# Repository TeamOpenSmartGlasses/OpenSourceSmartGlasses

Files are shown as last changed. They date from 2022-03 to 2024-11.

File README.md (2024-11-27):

# Open Source Smart Glasses

### Update 2024 - we've moved on to build [AugmentOS](https://augmentos.org/), a unifying OS for smart glasses such as *Even Reality G1* and *Vuzix Z100*. It combines your favorite smart glasses apps, an app store, and SDK. We hope you like it <3

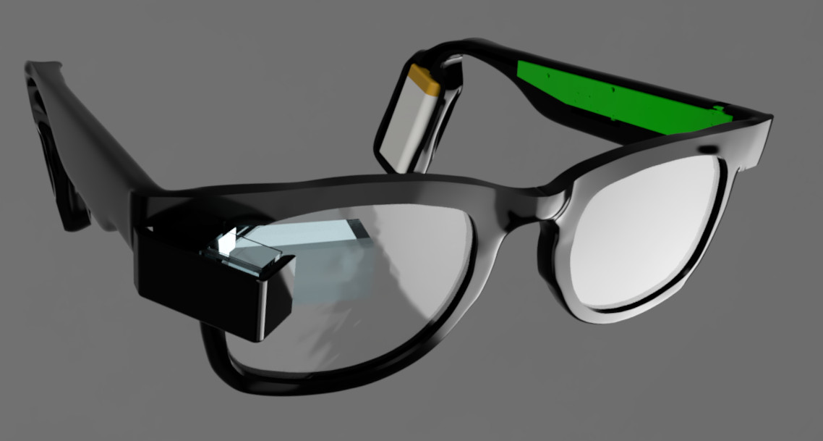
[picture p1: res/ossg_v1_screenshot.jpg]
OSSG Latest CAD Render


Smart glasses with display, microphones, wireless phone connection, prescription lenses, hours of battery life, and LED indicator. These glasses connect directly to the [Wearable Intelligence System](https://github.com/emexlabs/WearableIntelligenceSystem), so they host a suite of apps like live language translation, contextual search engine, intelligent assistant, web search, and more.

We're building open source smart glasses designed to be:  
1. All day wearable 
2. Immediately useful 
3. Extendable for makers, startups, and everyone else.  

This repo holds mechanical, electrical, and software files for the open source smartglasses developed by Team Open Smart Glasses.

This project is built by members of TeamOpenSmartGlasses and the [H20 Smart Glasses Community](https://smartglasses.community/), a community of engineers, researchers, makers, designers, entrepreneurs, and anyone else driven to build technology that enhances user's intelligence in daily life.  

## Videos

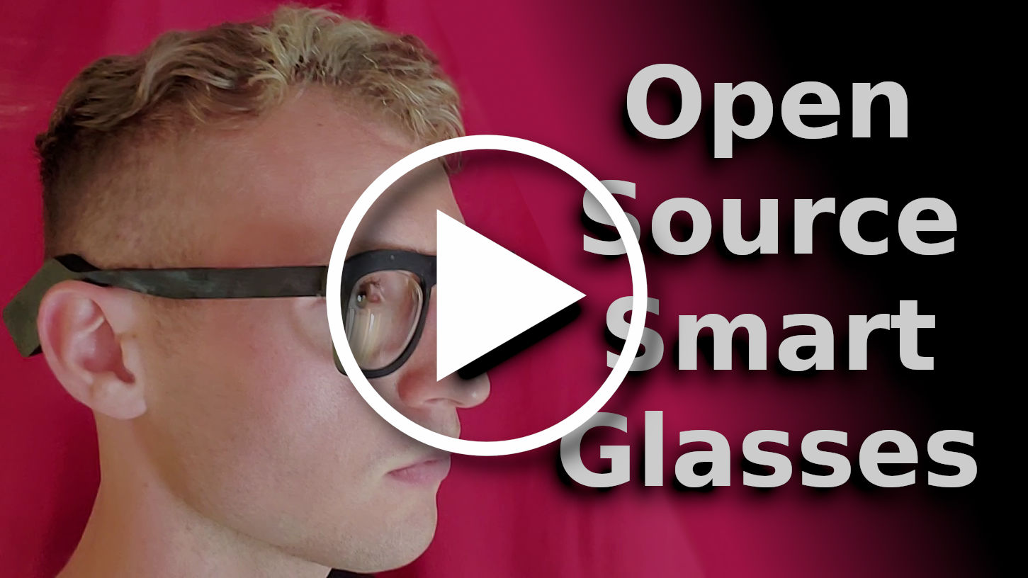
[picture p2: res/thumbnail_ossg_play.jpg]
Open Source Smart Glasses Prototype Project/Progress Video (https://www.youtube.com/watch?v=PwmGNWkpKW8 "Open Source Smart Glasses")


## Images

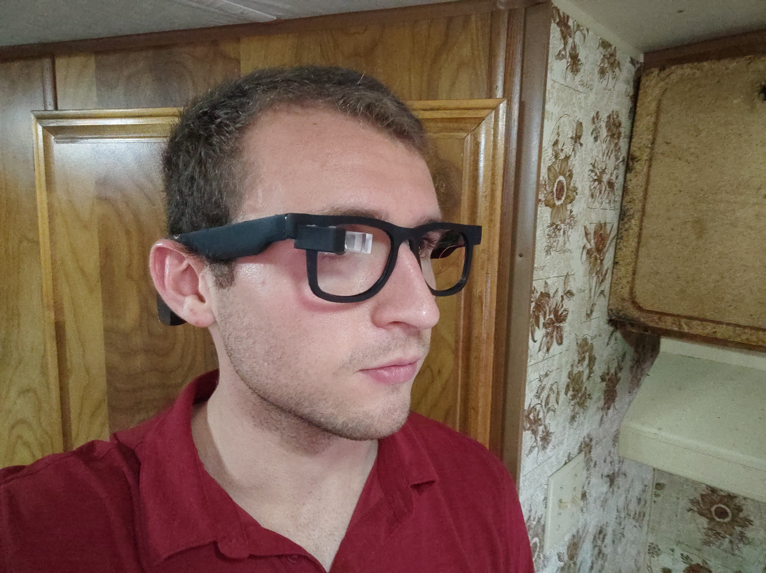
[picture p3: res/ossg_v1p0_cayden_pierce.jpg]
User Wearing OSSG v1.0

OSSG Latest CAD Render
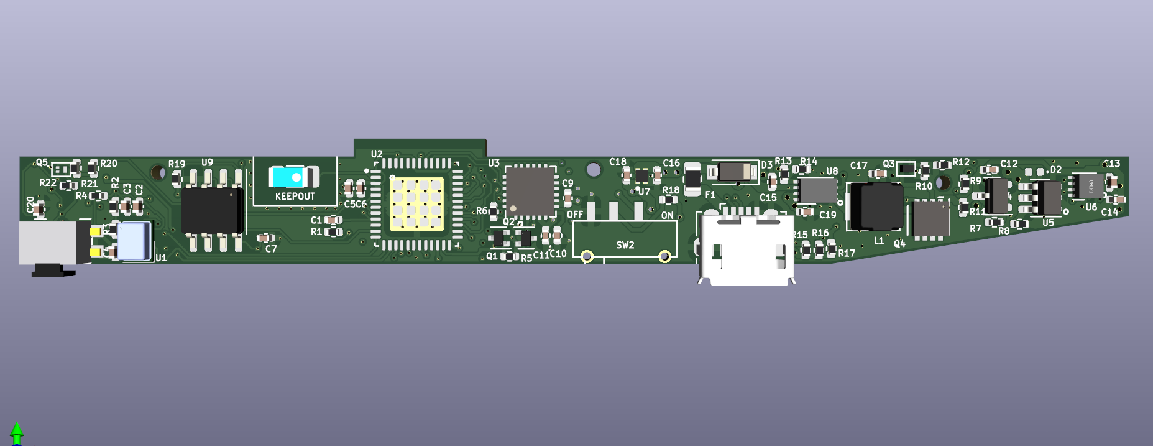
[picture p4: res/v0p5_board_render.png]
OSSG v0p5 Board Design Render

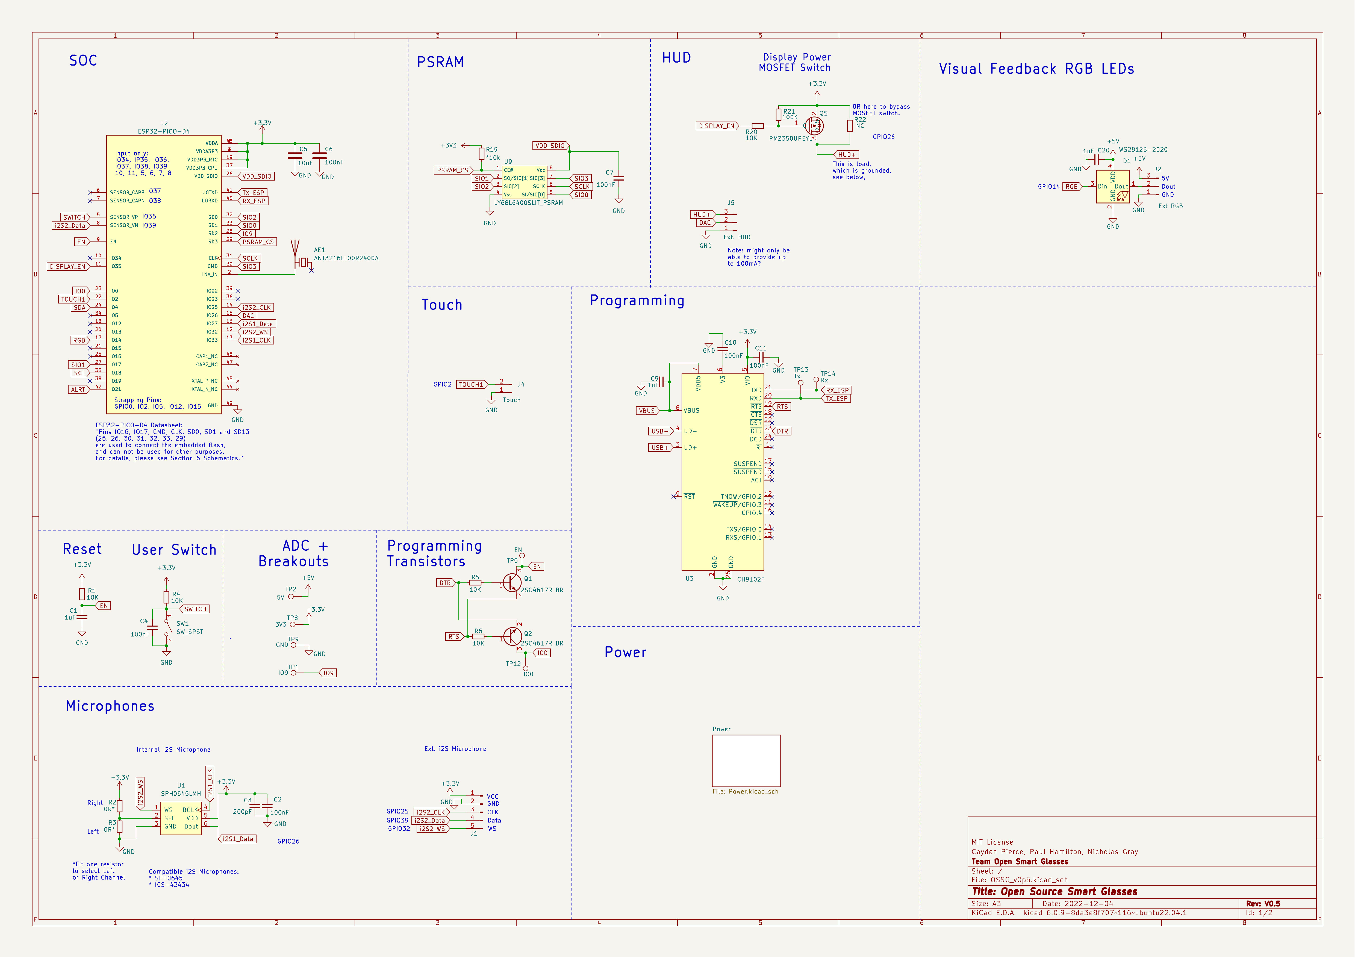
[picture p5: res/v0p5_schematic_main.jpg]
OSSG v0.5 Main Schematic

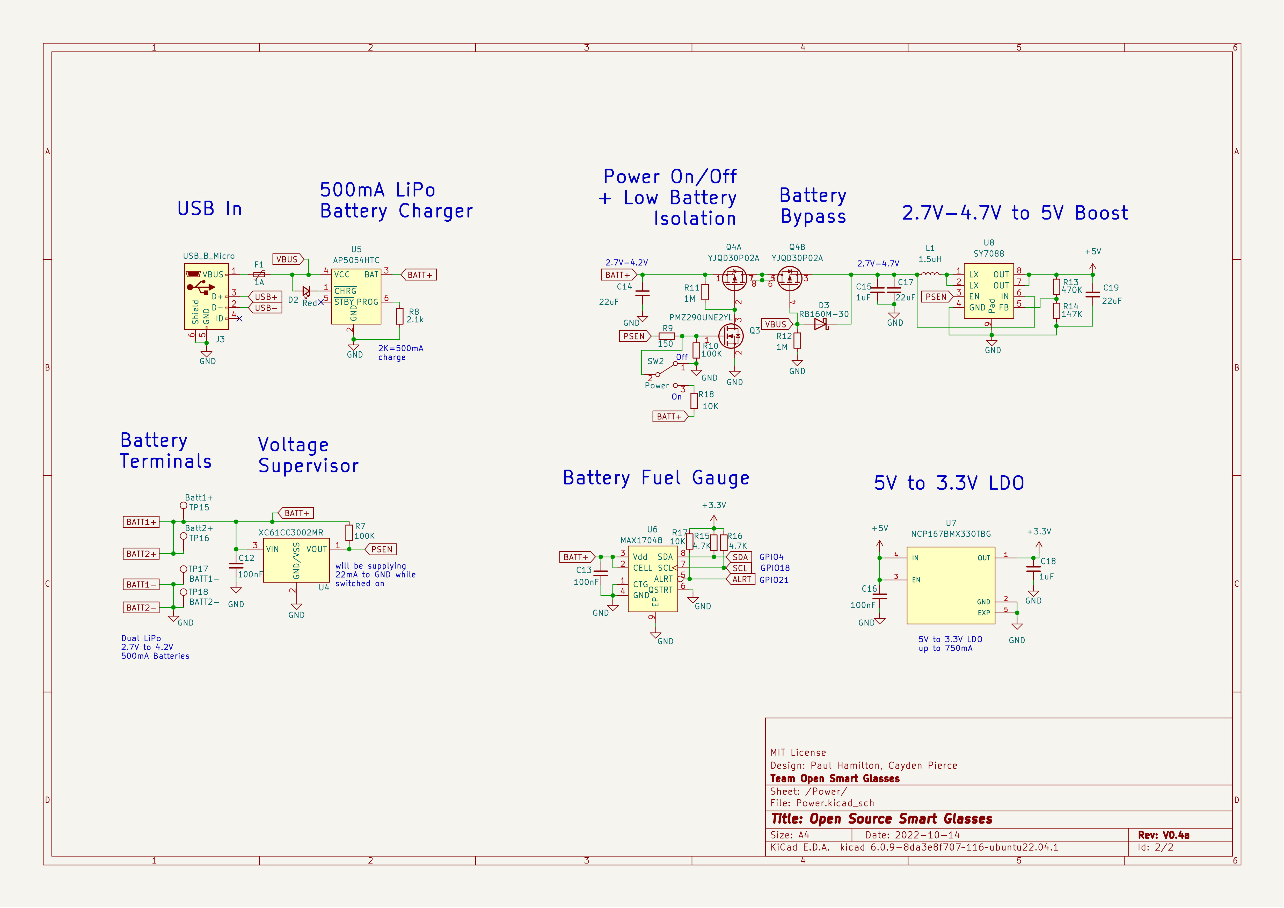
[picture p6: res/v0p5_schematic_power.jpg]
OSSG v0.5 Power Schematic

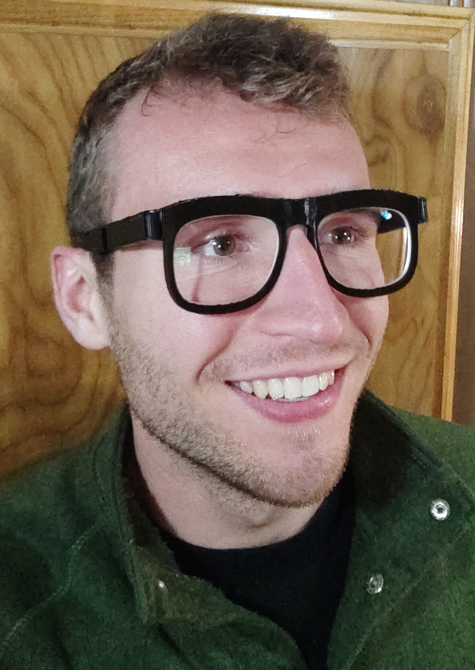
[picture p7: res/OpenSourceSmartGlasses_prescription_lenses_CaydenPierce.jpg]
OSSG Prescription Lenses

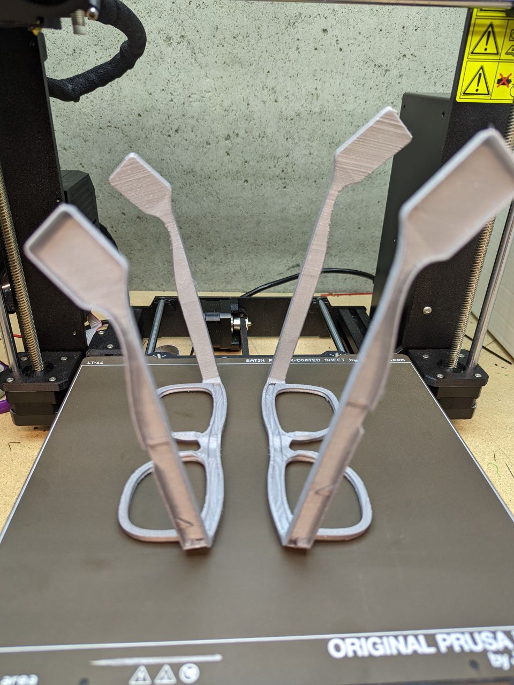
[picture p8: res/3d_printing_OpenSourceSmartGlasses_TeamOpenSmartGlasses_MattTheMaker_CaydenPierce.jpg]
OSSG 3D Printing DIY

## License

All work contained here is licensed under the MIT License.

## Overview

See the wiki, this README, and the discord for an overview of the project vision and roadmap. More information to be added soon. Here's [the discord](https://discord.gg/5ukNvkEAqT).

### OSSG - Open Source Smart Glasses

1. All day wearability. There is a difference between something that you could wear and something that you will wear. We are laser focused on building a form factor that users (us) will enjoy wearing from the start in terms of comfort, shape, size, weight, and aesthetics.
2. Immediately useful. There is a difference between will wear and want to wear. From the beginning, we are designing and building hardware with use cases in mind.
3. Extendable for makers, startups, researchers, and everyone else. Our Open Source approach is aimed at helping everyone use smart glasses. We believe the most valuable use cases will only arise when smart glasses are accessable to be built, worn, and hacked, so that's what we're making.

#### Plan

1. We want full fledged smart glasses with all-day wearability, display, camera, microphone, sensor suite, batteries, wireless communications, speakers, etc. that is low power, low heat, low profile (stylish), and provides a host of novel and valuable use cases, that is as open and extendable as possible.
2. Trying to do that all at once is too big of a task. Faster, better progress is made if one starts with something that works and then focuses on quick iterationn cycles for building something useful that we can wear all day, everday. We start with something all day wearable, and then we iterate from there. 
3. Instead of just focusing on hardware and hoping that the use case presents itself, our design starts from the use cases that we want, and we design from there. 
4. Build the first version of our glasses that meets the use case but stays technically simpler so we can never stray from our core value of all day wearability.
5. Once this early version is working and we all wear it all day, move on to more complicated things - like an applications processor and display.

## Team Open Smartglasses

Team Open Smartglasses is a group of engineers, researchers, makers, and designers from around the world joining forces to build Open Source Smartglasses. We're a highly technical team of people who have all built custom wearables on our own in the past, coming together to build the world's best smart glasses, Open Source.

## Community

If you're interested in developing Open Source Smart Glasses, feel free to to join the [Discord server](https://discord.gg/5ukNvkEAqT).

## Contributors / Collaborators

The system is fully Open Source and built by this growing list of contributors:

- [Cayden Pierce](https://caydenpierce.com) - [Emex Labs](https://emexwearables.com)
- [Alex Israelov](https://alexisraelov.com)
- Paul Hamilton
- [Adrian Papineau](https://www.parallelinnov.com/about-us/)
- [Nicholas Gray](https://github.com/Thecactusman0)
- Matthew Jansen
- Paul M
- Your Name Here, [join us](https://discord.gg/5ukNvkEAqT)!

## How Do I Buy A Pair?

We reccomend building your own. There is no way to purchase a pair. Please don't reach out to the developers to buy a pair.

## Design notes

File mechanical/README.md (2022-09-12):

## How to Print
To print full pair of glasses; 

- Print left arm
- Print right arm
- Print front frame
- Print left arm cover
- Print right arm cover

## How to Build
Hardware:
- M2 3-6mm bolts (preferably flat head)
- 2mm threaded inserts

Insert threaded inserts into glasses arms using soldering iron.

Screw arm covers into threaded inserts with M2 screws.

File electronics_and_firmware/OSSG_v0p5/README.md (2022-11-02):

# Open Source Smartglasses PCB V0.4
---

This version was an attempt to use a 2P battery pack.  

### PCB 0.4 Features:

First batch sent off for production: 2022-09-22 for Australian delivery, assembling and testing
- fix missing missing ESP32_VDD3P3 connection
- solder connector pads for i2S microphones (non PDM)
- onboard PDM (over i2S)  microphone
- 2P battery configuration
- 2P battery charger
- MAX17048 Li battery fuel gauge
- power on/off switch
- USB 1A resetable fuse
- auto switch off when battery pack goes below 2.7V
- SY7088 3V to 5V at 1A DC-DC Boost converter
- provision for WS2812B-2020 RGB LED as visual feed back to wearer with connector for more external LEDs
- side mounted user tactile switch
- adjusted ESP32-Pico footprint
- adjusted mounting holes to M1.6 for screws and a M1.5 non-screw hole for alignment
- touch sensor connector pads
- Heads Up Display connector (experimental)

### PCB:

- 4 layer
- 9mm x 85mm long
- 0.8mm thick (Australian board is 1.0mm thick)

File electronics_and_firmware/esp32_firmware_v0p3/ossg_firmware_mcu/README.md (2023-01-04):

# OSSG Firmware

This firmware serves as as smart glasses thin client for the [Wearable Intelligence System](https://github.com/emexlabs/WearableIntelligenceSystem) (WIS) for smart glasses powered by ESP32. The WIS Android smart phone (ASP) and GNU/Linux Box (GLBOX) servers handle all of the processing, logic, AI, etc., and this firmware sends signals to the WIS and receives UI prompts from the WIS (i.e. a thin client). See the [WIS](https://github.com/emexlabs/WearableIntelligenceSystem) for the ASP + GLBOX, as well as another frontend with the same API but designed for Android-powered smart glasses (ASG).

## Features

* Displays pretty UI over composite video using LovyanGFX + LVGL
* Streams recoreded audio to an Android device
* Receives JSON commands from an Android device

## Setup

1. Install VSCODE
2. Install platformio in VSCODE
3. a) If your ESP32 has PSRAM, enable PSRAM in menuconfig. Otherwise, disable PSRAM in menuconfig
```
platformio run -t menuconfig
```
Component config -> ESP32 Specific -> SPIRAM/PSRAM Enable/Disable  
b) Comment/uncomment PSRAM lines from platformio.ini depending on your ESP32 hardware

## Gotchas

If build goes well and then at the very end you get undefined reference to a task function that doesn't take arguments, make sure you have it take the `void *args` argument.

## TODO

* Search engine result
* Command success page (success? And what the command did)
* Screen to stream in new text (live life captions/speech translate)

## History

This project's display solution is heavily inspired by the [Telescope](https://github.com/alex1115alex/Wearables-Telescope), a Google Glass-inspired project designed to be as compact and cheap as possible by taking advantage of the ESP32's composite video output capabilities. By Alex Israelov.

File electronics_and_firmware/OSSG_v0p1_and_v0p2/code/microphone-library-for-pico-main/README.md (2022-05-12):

# Firmware for Mico 

This project makes the minor modifications to Sandeep Mistry's 
repo below: 

https://github.com/ArmDeveloperEcosystem/microphone-library-for-pico

Changes:

1. Added a PIO based LED blink program.
2. Changed company and product description for USB audio.

Original README follows below:

<hr/>

# Microphone Library for Pico

Capture audio from a microphone on your [Raspberry Pi Pico](https://www.raspberrypi.org/products/raspberry-pi-pico/) or any [RP2040](https://www.raspberrypi.org/products/rp2040/) based board. 🎤

## Hardware

 * RP2040 board
   * [Raspberry Pi Pico](https://www.raspberrypi.org/products/raspberry-pi-pico/)
 * Microphones
   * Analog
     * [Electret Microphone Amplifier - MAX9814 with Auto Gain Control](https://www.adafruit.com/product/1713) 
   * PDM
     * [Adafruit PDM MEMS Microphone Breakout](https://www.adafruit.com/product/3492)

### Default Pinout

#### Analog Microphone

| Raspberry Pi Pico / RP2040 | Analog Microphone |
| --- | --- |
| 3.3V | VCC |
| GND | GND |
| GPIO 26 | OUT |

#### PDM Microphone

| Raspberry Pi Pico / RP2040 | PDM Microphone |
| --- | --- |
| 3.3V | VCC |
| GND | GND |
| GND | SEL |
| GPIO 2 | DAT |
| GPIO 3 | CLK |

GPIO pins are configurable in examples or API.

## Examples

See [examples](examples/) folder.

## Cloning

```sh
git clone https://github.com/ArmDeveloperEcosystem/microphone-library-for-pico.git 
```

## Building

1. [Set up the Pico C/C++ SDK](https://datasheets.raspberrypi.org/pico/getting-started-with-pico.pdf)
2. Set `PICO_SDK_PATH`
```sh
export PICO_SDK_PATH=/path/to/pico-sdk
```
3. Create `build` dir, run `cmake` and `make`:
```
mkdir build
cd build
cmake .. -DPICO_BOARD=pico
make
```
4. Copy example `.uf2` to Pico when in BOOT mode.

## License

[Apache-2.0 License](LICENSE)

## Acknowledgements

This project was created on behalf of the [Arm Software Developers](https://developer.arm.com/) team, follow them on Twitter: [@ArmSoftwareDev](https://twitter.com/armsoftwaredev) and YouTube: [Arm Software Developers](https://www.youtube.com/channel/UCHUAckhCfRom2EHDGxwhfOg) for more resources!

The [OpenPDM2PCM](https://os.mbed.com/teams/ST/code/X_NUCLEO_CCA02M1//file/53f8b511f2a1/Middlewares/OpenPDM2PCM/) library is used to filter raw PDM data into PCM. The [TinyUSB](https://github.com/hathach/tinyusb) library is used in the `usb_microphone` example.

---

Disclaimer: This is not an official Arm product.

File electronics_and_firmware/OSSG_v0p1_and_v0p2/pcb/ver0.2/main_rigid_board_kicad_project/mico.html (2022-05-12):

# mico.priv BOM Rev V 0.1

Date

# 2021-11-20

Company

# Electronut Labs

Comment 1

# Designed by Mahesh Venkitachalam

Comment 2

# Drawn by Sivaprakash

Comment 3

Comment 4

Total Parts

# 37 (Unique 18)

Ref

Qty

Value

Footprint

Datasheet

MANUFACTURER

MAXIMUM_PACKAGE_HEIGHT

PARTREV

STANDARD

[C] -

C1 C5 C17

3

10uF

Capacitor_SMD:C_0402_1005Metric

~

C2 C4 C6 C7 C10 C11 C12 C13 C14 C15 C16

11

0.1uF

Capacitor_SMD:C_0402_1005Metric

~

C3 C8 C9

3

1uF

Capacitor_SMD:C_0402_1005Metric

~

C18 C19

2

27pF

Capacitor_SMD:C_0402_1005Metric

~

[D] -

D1

1

APA3010SECK

mico:APA3010SECK

~

[J] -

J1

1

USB_plug

mico:usb-PCB

J2

1

SWD Prog

mico:SMD_1x04_P1.27mm

~

[R] -

R1 R3 R8

3

10K

Resistor_SMD:R_0402_1005Metric

~

R2 R7

2

1K

Resistor_SMD:R_0402_1005Metric

~

R4 R5

2

27R

Resistor_SMD:R_0402_1005Metric

~

R6

1

470R

Resistor_SMD:R_0402_1005Metric

~

[TP] -

TP1

1

TestPoint_2Pole

mico:SMD_1x02_P1.27mm

~

TP2

1

TestPoint

TestPoint:TestPoint_Pad_D1.0mm

~

[U] -

U1

1

MCP1702

Package_TO_SOT_SMD:SOT-23

http://ww1.microchip.com/downloads/en/DeviceDoc/20001826D.pdf

U2

1

MP23DB01HPTR

mico:MP23DB01HP

U3

1

W25Q128JV

mico:SOIC127P790X216-8N

U4

1

RP2040

mico:QFN40P700X700X90-57N

Raspberry Pi

0.9 mm

1.6.1

IPC 7351B

[Y] -

Y1

1

H130B-12.000-20-3050-EXT-TR

Crystal:Crystal_SMD_5032-4Pin_5.0x3.2mm

~

# BOM made with KICAD_BOM_WIZARD (https://github.com/HashDefineElectronics/KiCad_BOM_Wizard) (Generated 11/21/21 00:19:01)

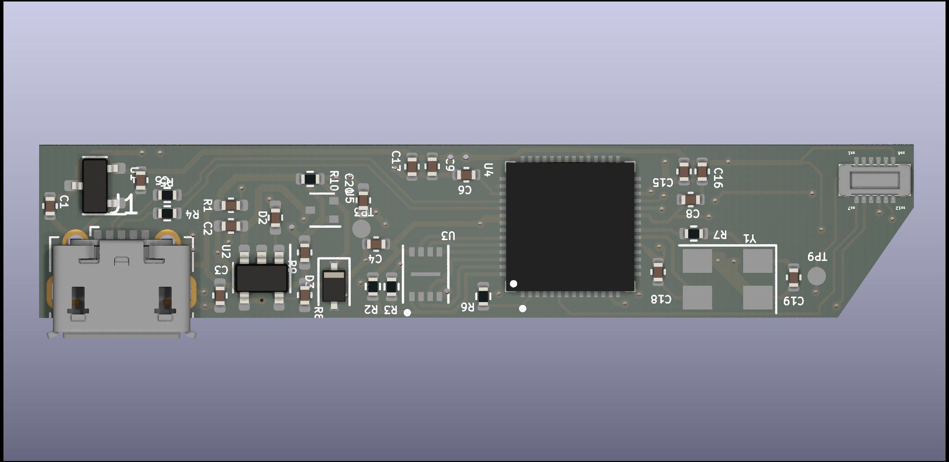
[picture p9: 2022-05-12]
electronics_and_firmware/OSSG_v0p1_and_v0p2/pcb/ver0.2/main_rigid_board_kicad_project/msa_main_board_0v2.png

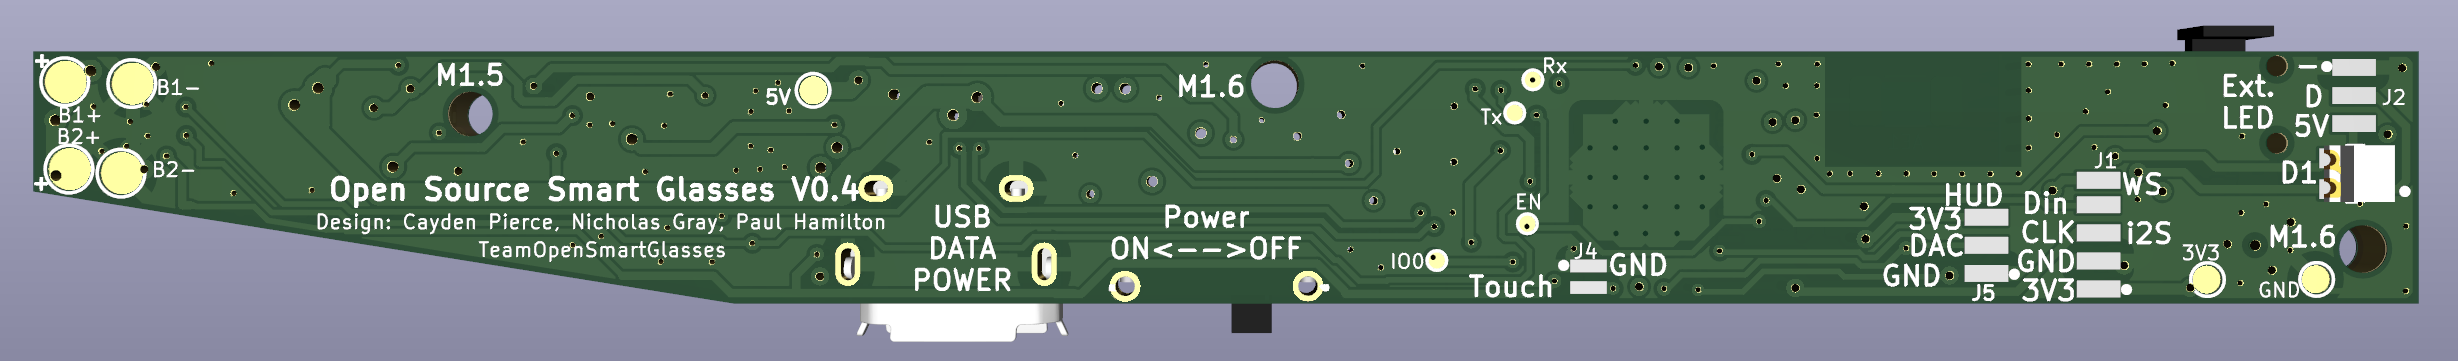
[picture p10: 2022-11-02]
electronics_and_firmware/OSSG_v0p5/Screenshots/V0.4b6-PCB-Backside_20220921-222840.png

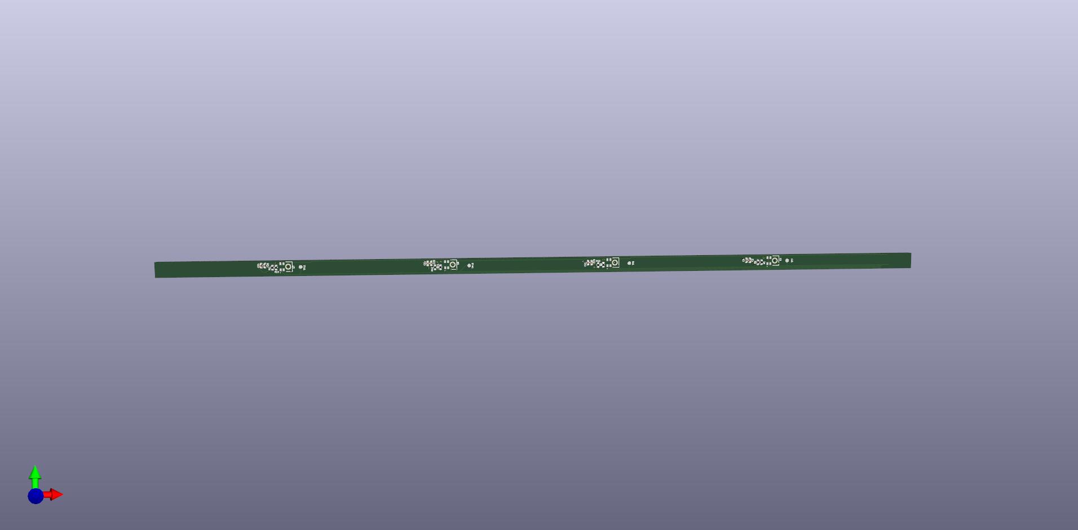
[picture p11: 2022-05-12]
electronics_and_firmware/OSSG_v0p1_and_v0p2/pcb/ver0.2/mic_array_flex_board_kicad_project/msa_flex_pcb_v0.2.jpg

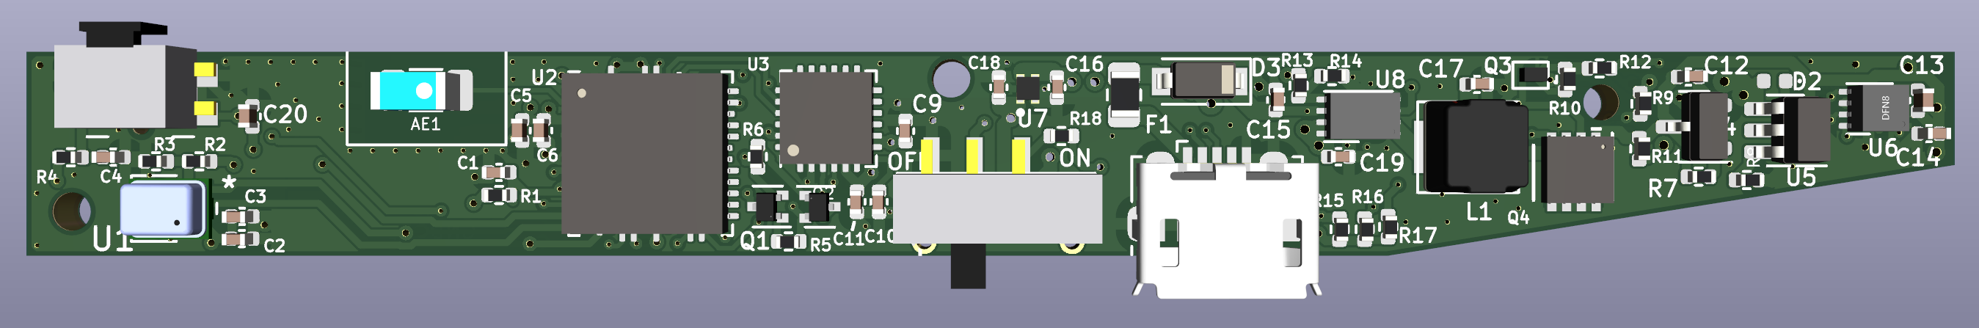
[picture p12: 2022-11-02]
electronics_and_firmware/OSSG_v0p5/Screenshots/V0.4b6-PCB-Frontside_20220921-222951.png

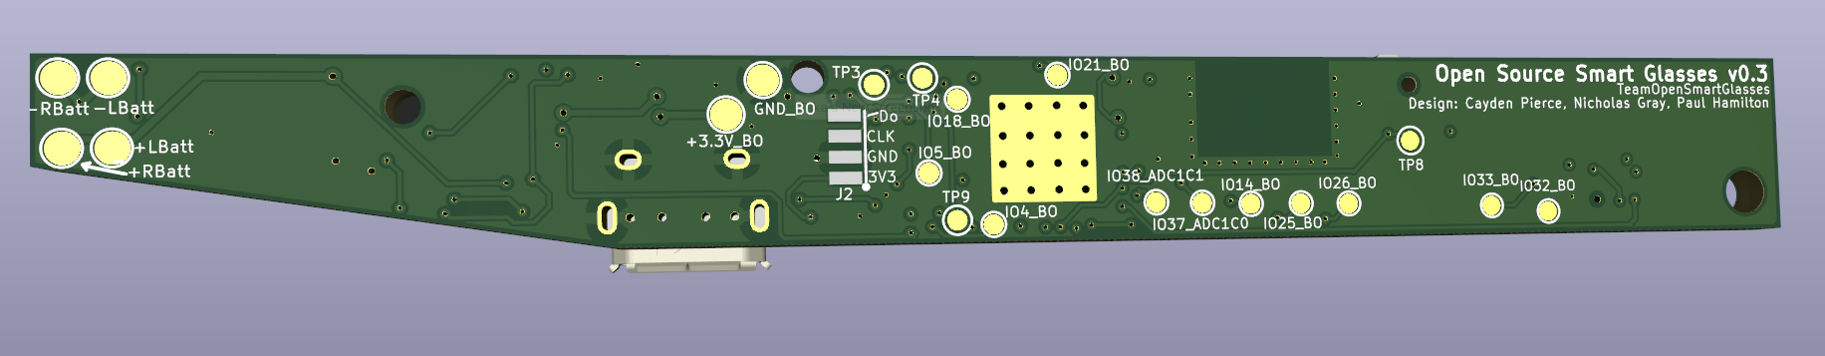
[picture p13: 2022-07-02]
electronics_and_firmware/OSSG_v0p4-2S/Screenshots/V0.3_SmartglassesPCB-3DModels_Backside.png

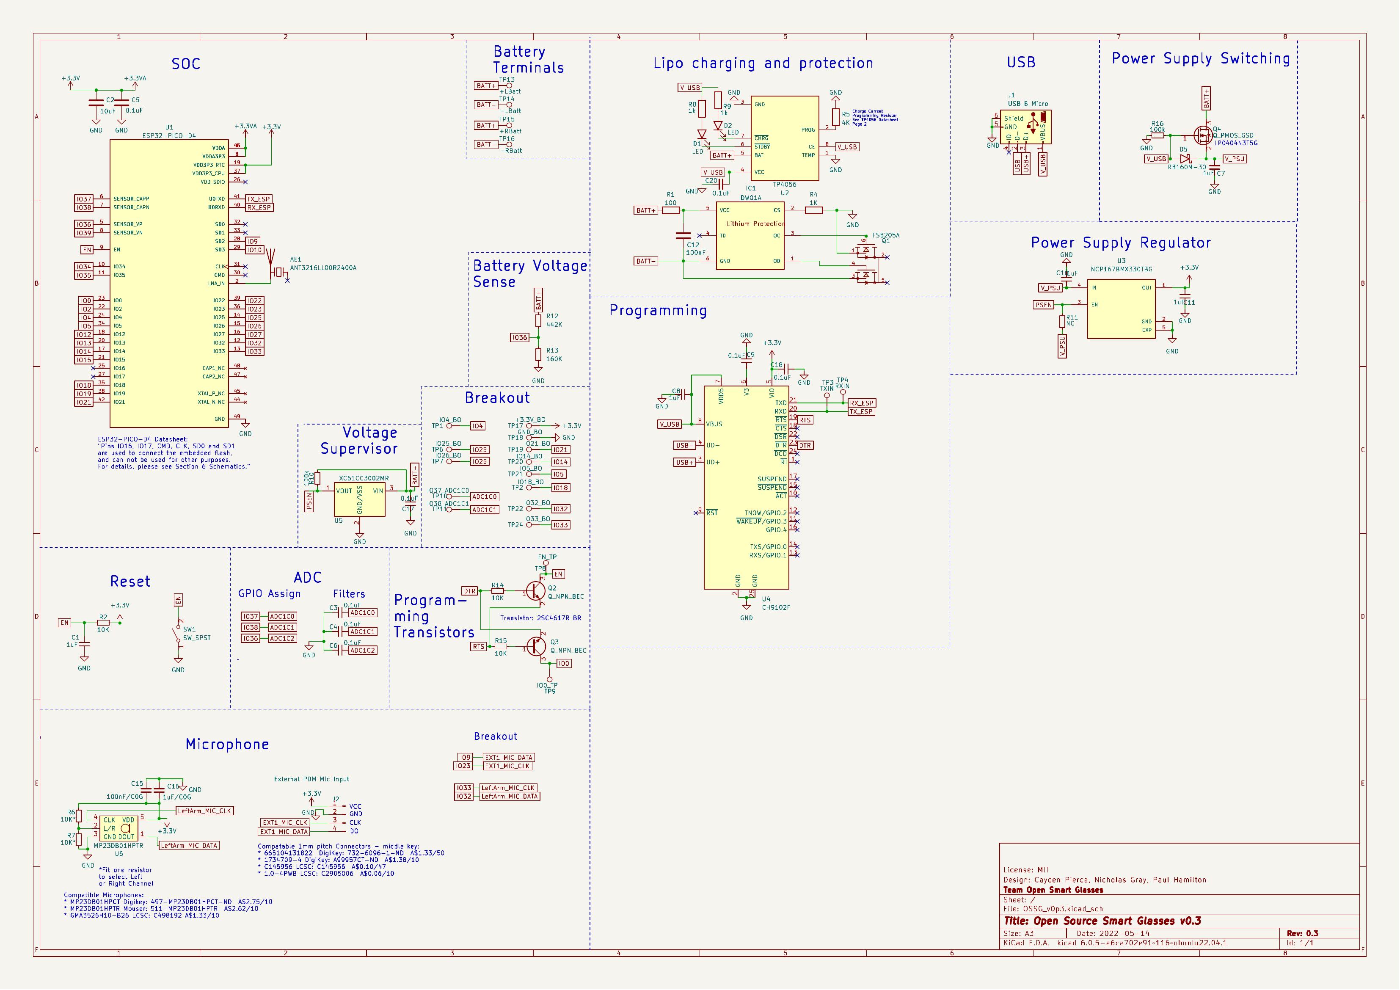
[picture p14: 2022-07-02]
res/OSSGv0p3_schematic_20220701.jpg

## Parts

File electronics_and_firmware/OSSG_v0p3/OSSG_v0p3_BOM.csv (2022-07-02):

Item | Qty | Reference(s) | Value | LibPart | Footprint | Datasheet | DigiKeyLink | LCSC | LCSCLink | LinkLCSC | MANUFACTURER | MAXIMUM_PACKAGE_HEIGHT | MPN | MPN_LCSC | MPN_LSCC | PARTREV | Price | Price_LCSC | Price_LCSSC | STANDARD | VALUE
1 | 1 | AE1 | ANT3216LL00R2400A | Device:Antenna_Chip | OSSG_footprints:ANT3216LL00R2400A | https://datasheet.lcsc.com/lcsc/1810241140_YAGEO-ANT3216LL00R2400A_C293767.pdf |  |  |  |  |  |  |  | C293767 |  |  |  | 0.1226
2 | 5 | C1, C7, C8, C10, C11 | 1uF | Device:C_Small | Capacitor_SMD:C_0402_1005Metric | https://search.murata.co.jp/Ceramy/image/img/A01X/G101/ENG/GRT155C80J105KE01-01.pdf | https://www.digikey.ca/en/products/detail/murata-electronics/GRT155C80J105KE01J/13904934 |  | https://lcsc.com/product-detail/Multilayer-Ceramic-Capacitors-MLCC-SMD-SMT_Samsung-Electro-Mechanics-CL05A105KP5NNNC_C14445.html |  |  |  | 490-GRT155C80J105KE01JCT-ND | C14445 |  |  | 0.0448 | 0.0018
3 | 1 | C2 | 10uF | Device:C | Capacitor_SMD:C_0402_1005Metric | https://media.digikey.com/pdf/Data%20Sheets/Samsung%20PDFs/CL05A106MP5NUNC_Spec.pdf | https://www.digikey.ca/en/products/detail/samsung-electro-mechanics/CL05A106MP5NUNC/3887108 |  | https://lcsc.com/product-detail/Multilayer-Ceramic-Capacitors-MLCC-SMD-SMT_Samsung-Electro-Mechanics-CL05A106MQ5NUNC_C15525.html |  |  |  | 1276-1450-1-ND | C15525 |  |  | 0.1092 | 0.0057
4 | 7 | C3, C4, C6, C9, C17, C18, C20 | 0.1uF | Device:C_Small | Capacitor_SMD:C_0402_1005Metric | ~ |  |  | https://lcsc.com/product-detail/Chip-Resistor-Surface-Mount_FH-Guangdong-Fenghua-Advanced-Tech-RC-02W101JT_C258109.html | https://lcsc.com/product-detail/Multilayer-Ceramic-Capacitors-MLCC-SMD-SMT_FH-Guangdong-Fenghua-Advanced-Tech-0402B104K160NT_C41851.html |  |  |  | C41851 |  |  |  | 0.0008
5 | 1 | C5 | 0.1uF | Device:C | Capacitor_SMD:C_0402_1005Metric | https://media.digikey.com/pdf/Data%20Sheets/Samsung%20PDFs/CL05A104KA5NNNC.pdf | https://www.digikey.ca/en/products/detail/samsung-electro-mechanics/CL05A104KA5NNNC/3886701 |  |  | https://lcsc.com/product-detail/Multilayer-Ceramic-Capacitors-MLCC-SMD-SMT_FH-Guangdong-Fenghua-Advanced-Tech-0402B104K160NT_C41851.html |  |  | 1276-1043-1-ND | C41851 |  |  | 0.006 | 0.0008
6 | 1 | C12 | 100nF | Device:C | Capacitor_SMD:C_0402_1005Metric | ~ |  |  |  |  |  |  |  | C41851 |  |  |  | 0.0008
7 | 1 | C15 | 100nF/C0G | Device:C_Small | Capacitor_SMD:C_0402_1005Metric | https://datasheet.lcsc.com/lcsc/1811141742_FH-Guangdong-Fenghua-Advanced-Tech-0402B104K160NT_C41851.pdf |  |  |  | https://lcsc.com/product-detail/Multilayer-Ceramic-Capacitors-MLCC-SMD-SMT_FH-Guangdong-Fenghua-Advanced-Tech-0402B104K160NT_C41851.html |  |  |  | C41851 |  |  |  | 0.0009
8 | 1 | C16 | 1uF/C0G | Device:C_Small | Capacitor_SMD:C_0402_1005Metric | ~ |  |  |  |  |  |  |  | C14445 |  |  |  | 0.0018
9 | 2 | D1, D2 | LED | Device:LED | Diode_SMD:D_0402_1005Metric | ~ |  |  |  |  |  |  |  | C2984137 |  |  |  | 0.0727
10 | 1 | D5 | RB160M-30 | Device:D_Schottky | Diode_SMD:D_SOD-123 | https://datasheet.lcsc.com/lcsc/2201121800_High-Diode-RB160M-30_C2937163.pdf |  |  |  |  |  |  |  | C2937163 |  |  |  | 0.0743
11 | 1 | IC1 | DW01A | DW01A:DW01A | Package_TO_SOT_SMD:SOT-23-6 |  |  | C351410 | https://lcsc.com/product-detail/Battery-Management-ICs_PUOLOP-DW01A_C351410.html |  |  |  | DW01A | C351410 |  |  |  | 0.0605 |  |  | DW01A
12 | 1 | J1 | USB_B_Micro | Connector:USB_B_Micro | Connector_USB:USB_Micro-B_Amphenol_10118194_Horizontal | https://www.molex.com/pdm_docs/sd/1050170001_sd.pdf | https://www.digikey.ca/en/products/detail/molex/1050170001/2350832 |  |  | https://lcsc.com/product-detail/USB-Connectors_MOLEX-1050170001_C136000.html |  |  | WM1399CT-ND | C136000 |  |  | 1.33 | 0.244
14 | 1 | Q1 | FS8205A | FS8205A:FS8205A | Package_TO_SOT_SMD:SOT-23-6 |  |  |  | https://www.lcsc.com/product-detail/MOSFETs_TECH-PUBLIC-FS8205A_C2830320.html |  | Fortune Semiconductor | 1.2mm |  | C2830320 |  | 1.7 | 0.0661 |  |  | IPC 7351B
15 | 2 | Q2, Q3 | Q_NPN_BEC | Device:Q_NPN_BEC | Package_TO_SOT_SMD:SOT-523 | ~ |  |  | https://lcsc.com/product-detail/Bipolar-Transistors-BJT_CBI-2SC4617R-BR_C2836080.html |  |  |  |  | C2836080 |  |  |  | 0.0163
16 | 1 | Q4 | Q_PMOS_GSD | Device:Q_PMOS_GSD | Package_TO_SOT_SMD:SOT-883 | ~ |  |  |  |  |  |  |  | C172433 |  |  |  | 0.0424
17 | 1 | R1 | 100 | Device:R | Resistor_SMD:R_0402_1005Metric | ~ |  |  | https://lcsc.com/product-detail/Chip-Resistor-Surface-Mount_FH-Guangdong-Fenghua-Advanced-Tech-RC-02W101JT_C258109.html |  |  |  |  | C258109 |  |  |  | 0.005
18 | 3 | R2, R14, R15 | 10K | Device:R_Small | Resistor_SMD:R_0402_1005Metric | https://www.seielect.com/catalog/sei-rmcf_rmcp.pdf | https://www.digikey.ca/en/products/detail/stackpole-electronics-inc/RMCF0402JT10K0/1758206 |  | https://lcsc.com/product-detail/Chip-span-style-background-color-ff0-Resistor-span-Surface-Mount_FOJAN-FRC0402J103-TS_C2906885.html |  |  |  | RMCF0402JT10K0CT-ND | C2906885 |  |  | 0.018 | 0.0005
19 | 1 | R4 | 1K | Device:R | Resistor_SMD:R_0402_1005Metric | ~ |  |  |  | https://lcsc.com/product-detail/Chip-Resistor-Surface-Mount_FOJAN-FRC0402J102-TS_C2906899.html |  |  |  | C2906899 |  |  |  | 0.0005
20 | 1 | R5 | 4K | Device:R | Resistor_SMD:R_0402_1005Metric | ~ |  |  | https://lcsc.com/product-detail/Chip-Resistor-Surface-Mount_UNI-ROYAL-Uniroyal-Elec-0402WGF4021TCE_C43251.html |  |  |  |  | C43251 |  |  |  | 0.0006
21 | 2 | R6, R7 | 10K* | Device:R_Small | Resistor_SMD:R_0402_1005Metric | https://www.seielect.com/catalog/sei-rmcf_rmcp.pdf | https://www.digikey.ca/en/products/detail/stackpole-electronics-inc/RMCF0402JT10K0/1758206 |  | https://lcsc.com/product-detail/Chip-span-style-background-color-ff0-Resistor-span-Surface-Mount_FOJAN-FRC0402J103-TS_C2906885.html |  |  |  | RMCF0402JT10K0CT-ND | C2906885 |  |  | 0.018 | 0.0005
22 | 2 | R8, R9 | 1k | Device:R | Resistor_SMD:R_0402_1005Metric | ~ |  |  | https://lcsc.com/product-detail/Chip-Resistor-Surface-Mount_FOJAN-FRC0402J102-TS_C2906899.html |  |  |  |  | C2906899 |  |  |  | 0.0005
23 | 2 | R10, R16 | 100k | Device:R_Small | Resistor_SMD:R_0402_1005Metric | ~ |  |  |  |  |  |  |  | C106234 |  |  |  | 0.0005
25 | 1 | R12 | 442K | Device:R_Small | Resistor_SMD:R_0402_1005Metric | ~ |  |  |  | https://lcsc.com/product-detail/Chip-span-style-background-color-ff0-Resistor-span-Surface-Mount_YAGEO-RC0402FR-07442KL_C273339.html |  |  |  | C273339 |  |  |  | 0.0006
26 | 1 | R13 | 160K | Device:R_Small | Resistor_SMD:R_0402_1005Metric | ~ |  |  | https://lcsc.com/product-detail/Chip-span-style-background-color-ff0-Resistor-span-Surface-Mount_UNI-ROYAL-Uniroyal-Elec-0402WGJ0164TCE_C423115.html |  |  |  |  | C423115 |  |  |  | 0.0005
27 | 1 | SW1 | SW_SPST | Switch:SW_SPST | Button_Switch_SMD:SW_SPST_B3U-3000P-B | https://omronfs.omron.com/en_US/ecb/products/pdf/en-b3u.pdf | https://www.digikey.ca/en/products/detail/omron-electronics-inc-emc-div/B3U-3100P-B/1811780 |  | https://lcsc.com/product-detail/Tactile-Switches_Omron-Electronics-B3U-3000PM-B_C306884.html |  |  |  | SW1103CT-ND | C306884 |  |  | 1.49 |  | 0.8963
49 | 1 | U1 | ESP32-PICO-D4 | ESP32-PICO-D4:ESP32-PICO-D4 | OSSG_footprints:ESP32_PICO_D4 | https://www.espressif.com/sites/default/files/documentation/esp32-pico-d4_datasheet_en.pdf | https://www.digikey.ca/en/products/detail/espressif-systems/ESP32-PICO-D4/9381722 |  | https://lcsc.com/product-detail/RF-Transceiver-ICs_Espressif-Systems-ESP32-PICO-D4_C193707.html |  | Espressif Systems | 1.04 mm | 1904-1029-1-ND | C193707 |  | v1.9 | 4.1837 |  |  | IPC 7351B
50 | 1 | U2 | TP4056 | TP4056:TP4056 | Package_SO:SOP-8_5.28x5.23mm_P1.27mm | https://dlnmh9ip6v2uc.cloudfront.net/datasheets/Prototyping/TP4056.pdf |  |  | https://lcsc.com/product-detail/Battery-Management-ICs_TOPPOWER-Nanjing-Extension-Microelectronics-TP4056M_C21417.html |  | NanJing Top Power ASIC Corp. | 1.75mm |  | C21417 |  |  |  | 0.3102 |  | IPC 7351B
51 | 1 | U3 | NCP167BMX330TBG | NCP167BMX330TBG:NCP167BMX330TBG | OSSG_footprints:REG_NCP167BMX330TBG | https://datasheet.lcsc.com/lcsc/2107280040_onsemi-NCP167BMX330TBG_C892227.pdf |  |  |  |  | ON Semiconductor | 0.43mm |  | C892227 |  | 3 |  | 0.4418 |  | Manufacturer recommendations
52 | 1 | U4 | CH9102F | wch-usb-uart:CH9102F | Package_DFN_QFN:QFN-24-1EP_4x4mm_P0.5mm_EP2.6x2.6mm | https://datasheet.lcsc.com/lcsc/2108181630_WCH-Jiangsu-Qin-Heng-CH9102F_C2858418.pdf |  |  |  |  |  |  |  | C2858418 |  |  |  | 1.35
53 | 1 | U5 | XC61CC3002MR | OSSG_components_lib:XC61C_voltage_supervisor | Package_TO_SOT_SMD:SOT-23 | https://datasheet.lcsc.com/lcsc/1811010914_Torex-Semicon-XC61CC3002MR_C80698.pdf |  |  |  |  |  |  |  | C80698 |  |  |  | 0.1688
54 | 1 | U6 | MP23DB01HPTR | microphone-rescue:MP23DB01HPTR-Pauls_Symbol_Library | OSSG_footprints:MP23DB01HPTR | https://www.st.com/resource/en/datasheet/mp23db01hp.pdf | https://www.digikey.ca/en/products/detail/stmicroelectronics/MP23DB01HPTR/12337705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 |  | https://www.lcsc.com/product-detail/MEMS-Microphones_INGHAi-GMA3526H10-B26_C498192.html |  |  |  | 497-MP23DB01HPCT-ND | C498192 |  |  | 3.31 | 1.0964
 | 2 | NA | 0R |  | 402 |  |  |  |  |  |  |  |  | C60485

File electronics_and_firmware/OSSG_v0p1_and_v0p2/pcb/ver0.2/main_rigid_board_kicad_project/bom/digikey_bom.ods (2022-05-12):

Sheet: OVERVIEW
OVERVIEW OF BOM – see sheets below
V0.1 – proof of concept, get microphone array fully working
V0.2 – put microphone array into a wearable form factor, make battery powered to experiment with wireless running
V0.3 – add applications processor for digital signal processing and streaming of audio over bluetooth/wifi, refine wearable casing for comfort
V0.3+ - NOT included in this application, but further versions will implement optics so users can see live captions
TOTAL ASK (3 iterations): | $1,513.98

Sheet: v0.1
Reference | Quantity | Value | Footprint | Datasheet | MANUFACTURER | MAXIMUM_PACKAGE_HEIGHT | PARTREV | STANDARD | Digikey Link | Digikey cost (CAD) at 3 units | Digikey PN | Total Price
C10 C7 C6 C11 C12 C13 C14 C15 C16 C4 C2 C20 C22 C24 | 14 | 0.1uF | Capacitor_SMD:C_0402_1005Metric | ~ |  |  |  |  | https://www.digikey.ca/en/products/detail/samsung-electro-mechanics/CL05A104KA5NNNC/3886701 | 0.0082 | CL05A104KA5NNNC | 0.1148
C17 C5 C1 | 3 | 10uF | Capacitor_SMD:C_0402_1005Metric | ~ |  |  |  |  | https://www.digikey.ca/en/products/detail/samsung-electro-mechanics/CL05A106MP5NUNC/3887108 | 0.181 | CL05A106MP5NUNC | 0.543
C18 C19 | 2 | 27pF | Capacitor_SMD:C_0402_1005Metric | ~ |  |  |  |  | https://www.digikey.ca/en/products/detail/kemet/CBR04C270J5GAC/12701212 | 0.17 | CBR04C270J5GAC | 0.34
C8 C9 C3 C21 C23 C25 | 6 | 1uF | Capacitor_SMD:C_0402_1005Metric | ~ |  |  |  |  | https://www.digikey.ca/en/products/detail/murata-electronics/GRT155C80J105KE01J/13904934 | 0.081 | GRT155C80J105KE01J | 0.486
D1 | 1 | APA3010SECK | LED_SMD:LED_0402_1005Metric | ~ |  |  |  |  | https://www.digikey.ca/en/products/detail/kingbright/APA3010SECK-GX/3084811 | 0.64 | APA3010SECK | 0.64
FID1 FID2 FID3 | 3 | Fiducial | Fiducial:Fiducial_0.5mm_Mask1mm | ~ |  |  |  |  |  |  | NA | 0
J1 | 1 | USB_A | mico:USB-A | ~ |  |  |  |  | https://www.digikey.ca/en/products/detail/samtec-inc/USB-AM-S-F-W-TH/6692093 | 2.18 | USB-AM-S-F-W-TH | 2.18
J2 | 1 | SWD Prog | mico:SMD_1x04_P1.27mm | ~ |  |  |  |  |  |  | NA | 0
R3 R8 R1 R10 R9 R12 R11 R14 R13 | 9 | 10K | Resistor_SMD:R_0402_1005Metric | ~ |  |  |  |  | https://www.digikey.ca/en/products/detail/stackpole-electronics-inc/RMCF0402JT10K0/1758206 | 0.017 | RMCF0402JT10K0 | 0.153
R4 R5 | 2 | 27R | Resistor_SMD:R_0402_1005Metric | ~ |  |  |  |  | https://www.digikey.ca/en/products/detail/stackpole-electronics-inc/RMCF0402FT27R0/4439986 | 0.022 | RMCF0402FT27R0 | 0.044
R6 | 1 | 470R | Resistor_SMD:R_0402_1005Metric | ~ |  |  |  |  | https://www.digikey.ca/en/products/detail/stackpole-electronics-inc/RMCF0402FT470R/1761381 | 0.022 | RMCF0402FT470R | 0.022
R7 R2 | 2 | 1K | Resistor_SMD:R_0402_1005Metric | ~ |  |  |  |  | https://www.digikey.ca/en/products/detail/stackpole-electronics-inc/RMCF0402FT1K00/1761754 | 0.017 | RMCF0402FT1K00 | 0.034
TP1 | 1 | TestPoint_2Pole | mico:SMD_1x02_P1.27mm | ~ |  |  |  |  |  |  | NA | 0
TP2 | 1 | TestPoint | mico:SMD_1x01_P1.27mm | ~ |  |  |  |  |  |  | NA | 0
U1 | 1 | MCP1702 | Package_TO_SOT_SMD:SOT-23 | http://ww1.microchip.com/downloads/en/DeviceDoc/20001826D.pdf |  |  |  |  | https://www.digikey.ca/en/products/detail/microchip-technology/MCP1702T-1802E-CB/1098465 | 0.85 | MCP1702T-1802E/CB | 0.85
U2 U6 U7 U5 | 4 | MP23DB01HPTR | mico:MIC_SPH0641LU4H-1 |  |  |  |  |  | https://www.digikey.ca/en/products/detail/stmicroelectronics/MP23DB01HPTR/12337705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 | 2.52 | MP23DB01HPTR | 10.08
U3 | 1 | W25Q128JV | mico:PSON50P300X200X60-9N |  |  |  |  |  | https://www.digikey.ca/en/products/detail/winbond-electronics/W25Q80DVUXIE-TR/5155060 | 0.92 | W25Q80DVUXIE | 0.92
U4 | 1 | RP2040 | mico:QFN40P700X700X90-57N |  | Raspberry Pi | 0.9 mm | 1.6.1 | IPC 7351B | https://www.digikey.ca/en/products/detail/raspberry-pi/SC0914-13/14306010 | 1.46 | SC0914(13) | 1.46
Y1 | 1 | H130B-12.000-20-3050-EXT-TR | Crystal:Crystal_SMD_5032-4Pin_5.0x3.2mm | ~ |  |  |  |  | https://www.digikey.ca/en/products/detail/raltron-electronics/H130B-12-000-20-3050-EXT-TR/13150898 | 0.52 | H130B-12.000-20-3050-EXT-TR | 0.52
 |  |  |  |  |  |  |  |  |  |  |  | 0
 |  |  |  |  |  |  |  |  |  |  |  | 0
 |  |  |  |  |  |  |  |  |  |  |  | 0
 |  |  |  |  |  |  |  |  |  |  |  | 0
 |  |  |  |  |  |  |  |  |  |  |  | 0
 |  |  |  |  |  |  |  |  |  |  |  | 0
 |  |  |  |  |  |  |  |  |  |  |  | 0
 |  |  |  |  |  |  |  |  |  |  |  | 0
 |  |  |  |  |  |  |  |  |  |  |  | 0
 |  |  |  |  |  |  |  |  |  |  |  | 0
 |  |  |  |  |  |  |  |  |  |  |  | 0
 |  |  |  |  |  |  |  |  |  |  | TOTAL: | 18.3868
 |  |  |  |  |  |  |  |  |  | Number of boards: | 5
 |  |  |  |  |  |  |  |  |  | Total Parts cost: |  | 91.934
 |  |  |  |  |  |  |  |  |  | PCB Cost: |  | $80.00
 |  |  |  |  |  |  |  |  |  | Stencil Cost: |  | 50
 |  |  |  |  |  |  |  |  |  | Solder wick |  | 8.87 | https://www.amazon.ca/gp/product/B007Z7Y7XM/ref=ppx_yo_dt_b_asin_title_o05_s00?ie=UTF8&psc=1
 |  |  |  |  |  |  |  |  |  | Solder |  | 15.99 | https://www.amazon.ca/gp/product/B06XKSSQDF/ref=ppx_yo_dt_b_asin_title_o09_s01?ie=UTF8&psc=1
 |  |  |  |  |  |  |  |  |  | Tweezers set |  | 15.99 | https://www.amazon.ca/gp/product/B07N2QGS75/ref=ppx_yo_dt_b_asin_title_o02_s01?ie=UTF8&psc=1
 |  |  |  |  |  |  |  |  |  | USB cables |  | 14.99 | https://www.amazon.ca/gp/product/B00P0ES0TE/ref=ppx_yo_dt_b_asin_title_o06_s00?ie=UTF8&psc=1
 |  |  |  |  |  |  |  |  |  | Solder flux |  | 9.89 | https://www.amazon.ca/gp/product/B08ZT19JJS/ref=ppx_yo_dt_b_asin_title_o09_s00?ie=UTF8&psc=1
 |  |  |  |  |  |  |  |  |  | SMD solder hotplate |  | 31.5 | https://www.amazon.ca/gp/product/B000B2WOWE/ref=ppx_yo_dt_b_asin_title_o04_s00?ie=UTF8&psc=1
 |  |  |  |  |  |  |  |  |  | Jumper wires |  | 9.9 | https://www.amazon.ca/gp/product/B01M1IEUAF/ref=ppx_yo_dt_b_asin_title_o07_s00?ie=UTF8&psc=1
 |  |  |  |  |  |  |  |  |  | TOTAL: |  | $329.06

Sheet: v0.2
Reference | Quantity | Value | Footprint | Datasheet | MANUFACTURER | MAXIMUM_PACKAGE_HEIGHT | PARTREV | STANDARD | Digikey Link | Digikey cost (CAD) EACH at 3 units | Digikey PN | Total Price
C10 C7 C6 C11 C12 C13 C14 C15 C16 C4 C2 C20 C22 C24 | 14 | 0.1uF | Capacitor_SMD:C_0402_1005Metric | ~ |  |  |  |  | https://www.digikey.ca/en/products/detail/samsung-electro-mechanics/CL05A104KA5NNNC/3886701 | 0.0082 | CL05A104KA5NNNC | 0.1148
C17 C5 C1 | 3 | 10uF | Capacitor_SMD:C_0402_1005Metric | ~ |  |  |  |  | https://www.digikey.ca/en/products/detail/samsung-electro-mechanics/CL05A106MP5NUNC/3887108 | 0.181 | CL05A106MP5NUNC | 0.543
C18 C19 | 2 | 27pF | Capacitor_SMD:C_0402_1005Metric | ~ |  |  |  |  | https://www.digikey.ca/en/products/detail/kemet/CBR04C270J5GAC/12701212 | 0.17 | CBR04C270J5GAC | 0.34
C8 C9 C3 C21 C23 C25 | 6 | 1uF | Capacitor_SMD:C_0402_1005Metric | ~ |  |  |  |  | https://www.digikey.ca/en/products/detail/murata-electronics/GRT155C80J105KE01J/13904934 | 0.081 | GRT155C80J105KE01J | 0.486
D1 | 1 | APA3010SECK | LED_SMD:LED_0402_1005Metric | ~ |  |  |  |  | https://www.digikey.ca/en/products/detail/kingbright/APA3010SECK-GX/3084811 | 0.64 | APA3010SECK | 0.64
FID1 FID2 FID3 | 3 | Fiducial | Fiducial:Fiducial_0.5mm_Mask1mm | ~ |  |  |  |  |  |  | NA | 0
J1 | 1 | USB_A | mico:USB-A | ~ |  |  |  |  | https://www.digikey.ca/en/products/detail/samtec-inc/USB-AM-S-F-W-TH/6692093 | 2.18 | USB-AM-S-F-W-TH | 2.18
J2 | 1 | SWD Prog | mico:SMD_1x04_P1.27mm | ~ |  |  |  |  |  |  | NA | 0
R3 R8 R1 R10 R9 R12 R11 R14 R13 | 9 | 10K | Resistor_SMD:R_0402_1005Metric | ~ |  |  |  |  | https://www.digikey.ca/en/products/detail/stackpole-electronics-inc/RMCF0402JT10K0/1758206 | 0.017 | RMCF0402JT10K0 | 0.153
R4 R5 | 2 | 27R | Resistor_SMD:R_0402_1005Metric | ~ |  |  |  |  | https://www.digikey.ca/en/products/detail/stackpole-electronics-inc/RMCF0402FT27R0/4439986 | 0.022 | RMCF0402FT27R0 | 0.044
R6 | 1 | 470R | Resistor_SMD:R_0402_1005Metric | ~ |  |  |  |  | https://www.digikey.ca/en/products/detail/stackpole-electronics-inc/RMCF0402FT470R/1761381 | 0.022 | RMCF0402FT470R | 0.022
R7 R2 | 2 | 1K | Resistor_SMD:R_0402_1005Metric | ~ |  |  |  |  | https://www.digikey.ca/en/products/detail/stackpole-electronics-inc/RMCF0402FT1K00/1761754 | 0.017 | RMCF0402FT1K00 | 0.034
TP1 | 1 | TestPoint_2Pole | mico:SMD_1x02_P1.27mm | ~ |  |  |  |  |  |  | NA | 0
TP2 | 1 | TestPoint | mico:SMD_1x01_P1.27mm | ~ |  |  |  |  |  |  | NA | 0
U1 | 1 | MCP1702 | Package_TO_SOT_SMD:SOT-23 | http://ww1.microchip.com/downloads/en/DeviceDoc/20001826D.pdf |  |  |  |  | https://www.digikey.ca/en/products/detail/microchip-technology/MCP1702T-1802E-CB/1098465 | 0.85 | MCP1702T-1802E/CB | 0.85
U2 U6 U7 U5 | 4 | MP23DB01HPTR | mico:MIC_SPH0641LU4H-1 |  |  |  |  |  | https://www.digikey.ca/en/products/detail/stmicroelectronics/MP23DB01HPTR/12337705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 | 2.52 | MP23DB01HPTR | 10.08
U3 | 1 | W25Q128JV | mico:PSON50P300X200X60-9N |  |  |  |  |  | https://www.digikey.ca/en/products/detail/winbond-electronics/W25Q80DVUXIE-TR/5155060 | 0.92 | W25Q80DVUXIE | 0.92
U4 | 1 | RP2040 | mico:QFN40P700X700X90-57N |  | Raspberry Pi | 0.9 mm | 1.6.1 | IPC 7351B | https://www.digikey.ca/en/products/detail/raspberry-pi/SC0914-13/14306010 | 1.46 | SC0914(13) | 1.46
Y1 | 1 | H130B-12.000-20-3050-EXT-TR | Crystal:Crystal_SMD_5032-4Pin_5.0x3.2mm | ~ |  |  |  |  | https://www.digikey.ca/en/products/detail/raltron-electronics/H130B-12-000-20-3050-EXT-TR/13150898 | 0.52 | H130B-12.000-20-3050-EXT-TR | 0.52
 | 2 | 400 mAh lithium polymer batteries |  |  |  |  |  |  |  | 15 |  | 30
 | 3 | Lithium polymer battery charge controller |  | https://cdn.sparkfun.com/assets/learn_tutorials/6/9/5/MCP738312.pdf |  |  |  |  | https://www.digikey.ca/en/products/detail/microchip-technology/MCP73831T-2ACI-OT/964301 | 1.01 |  | 3.03
 |  |  |  |  |  |  |  |  |  |  |  | 0
 |  |  |  |  |  |  |  |  |  |  |  | 0
 |  |  |  |  |  |  |  |  |  |  |  | 0
 |  |  |  |  |  |  |  |  |  |  |  | 0
 |  |  |  |  |  |  |  |  |  |  |  | 0
 |  |  |  |  |  |  |  |  |  |  |  | 0
 |  |  |  |  |  |  |  |  |  |  |  | 0
 |  |  |  |  |  |  |  |  |  |  |  | 0
 |  |  |  |  |  |  |  |  |  |  |  | 0
 |  |  |  |  |  |  |  |  |  |  | TOTAL: | 51.4168
 |  |  |  |  |  |  |  |  |  | Number of boards: | 3
 |  |  |  |  |  |  |  |  |  | Total Parts cost: |  | 154.2504
 |  |  |  |  |  |  |  |  |  | Rigid PCB + stencil Cost (PCBWAY): |  | 94.68
 |  |  |  |  |  |  |  |  |  | Flex PCB + Stencil (PCBWAY): |  | 205.42
 |  |  |  |  |  |  |  |  |  | 30 awg Silicone Electrical Wire Cable |  | 25 | https://www.amazon.ca/Silicone-Electrical-Electronics-Stranded-Flexible/dp/B07THYFTJY
 |  |  |  |  |  |  |  |  |  | Estimated 3D print cost: |  | 15
 |  |  |  |  |  |  |  |  |  | Glasses lenses cost (quantity 2 pairs) |  | 60
 |  |  |  |  |  |  |  |  |  | TOTAL: |  | $595.42

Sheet: v0.3
Reference | Quantity | Value | Note | Footprint | Datasheet | MANUFACTURER | MAXIMUM_PACKAGE_HEIGHT | PARTREV | STANDARD | Digikey Link | Digikey cost (CAD) EACH at 3 units | Digikey PN | Total Price
C10 C7 C6 C11 C12 C13 C14 C15 C16 C4 C2 C20 C22 C24 | 14 | 0.1uF |  | Capacitor_SMD:C_0402_1005Metric | ~ |  |  |  |  | https://www.digikey.ca/en/products/detail/samsung-electro-mechanics/CL05A104KA5NNNC/3886701 | 0.0082 | CL05A104KA5NNNC | 0.1148
C17 C5 C1 | 3 | 10uF |  | Capacitor_SMD:C_0402_1005Metric | ~ |  |  |  |  | https://www.digikey.ca/en/products/detail/samsung-electro-mechanics/CL05A106MP5NUNC/3887108 | 0.181 | CL05A106MP5NUNC | 0.543
C18 C19 | 2 | 27pF |  | Capacitor_SMD:C_0402_1005Metric | ~ |  |  |  |  | https://www.digikey.ca/en/products/detail/kemet/CBR04C270J5GAC/12701212 | 0.17 | CBR04C270J5GAC | 0.34
C8 C9 C3 C21 C23 C25 | 6 | 1uF |  | Capacitor_SMD:C_0402_1005Metric | ~ |  |  |  |  | https://www.digikey.ca/en/products/detail/murata-electronics/GRT155C80J105KE01J/13904934 | 0.081 | GRT155C80J105KE01J | 0.486
D1 | 1 | APA3010SECK |  | LED_SMD:LED_0402_1005Metric | ~ |  |  |  |  | https://www.digikey.ca/en/products/detail/kingbright/APA3010SECK-GX/3084811 | 0.64 | APA3010SECK | 0.64
FID1 FID2 FID3 | 3 | Fiducial |  | Fiducial:Fiducial_0.5mm_Mask1mm | ~ |  |  |  |  |  |  | NA | 0
J1 | 1 | USB_A |  | mico:USB-A | ~ |  |  |  |  | https://www.digikey.ca/en/products/detail/samtec-inc/USB-AM-S-F-W-TH/6692093 | 2.18 | USB-AM-S-F-W-TH | 2.18
J2 | 1 | SWD Prog |  | mico:SMD_1x04_P1.27mm | ~ |  |  |  |  |  |  | NA | 0
R3 R8 R1 R10 R9 R12 R11 R14 R13 | 9 | 10K |  | Resistor_SMD:R_0402_1005Metric | ~ |  |  |  |  | https://www.digikey.ca/en/products/detail/stackpole-electronics-inc/RMCF0402JT10K0/1758206 | 0.017 | RMCF0402JT10K0 | 0.153
R4 R5 | 2 | 27R |  | Resistor_SMD:R_0402_1005Metric | ~ |  |  |  |  | https://www.digikey.ca/en/products/detail/stackpole-electronics-inc/RMCF0402FT27R0/4439986 | 0.022 | RMCF0402FT27R0 | 0.044
R6 | 1 | 470R |  | Resistor_SMD:R_0402_1005Metric | ~ |  |  |  |  | https://www.digikey.ca/en/products/detail/stackpole-electronics-inc/RMCF0402FT470R/1761381 | 0.022 | RMCF0402FT470R | 0.022
R7 R2 | 2 | 1K |  | Resistor_SMD:R_0402_1005Metric | ~ |  |  |  |  | https://www.digikey.ca/en/products/detail/stackpole-electronics-inc/RMCF0402FT1K00/1761754 | 0.017 | RMCF0402FT1K00 | 0.034
TP1 | 1 | TestPoint_2Pole |  | mico:SMD_1x02_P1.27mm | ~ |  |  |  |  |  |  | NA | 0
TP2 | 1 | TestPoint |  | mico:SMD_1x01_P1.27mm | ~ |  |  |  |  |  |  | NA | 0
U1 | 1 | MCP1702 |  | Package_TO_SOT_SMD:SOT-23 | http://ww1.microchip.com/downloads/en/DeviceDoc/20001826D.pdf |  |  |  |  | https://www.digikey.ca/en/products/detail/microchip-technology/MCP1702T-1802E-CB/1098465 | 0.85 | MCP1702T-1802E/CB | 0.85
U2 U6 U7 U5 | 4 | MP23DB01HPTR |  | mico:MIC_SPH0641LU4H-1 |  |  |  |  |  | https://www.digikey.ca/en/products/detail/stmicroelectronics/MP23DB01HPTR/12337705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 | 2.52 | MP23DB01HPTR | 10.08
U3 | 1 | W25Q128JV |  | mico:PSON50P300X200X60-9N |  |  |  |  |  | https://www.digikey.ca/en/products/detail/winbond-electronics/W25Q80DVUXIE-TR/5155060 | 0.92 | W25Q80DVUXIE | 0.92
U4 | 1 | RP2040 |  | mico:QFN40P700X700X90-57N |  | Raspberry Pi | 0.9 mm | 1.6.1 | IPC 7351B | https://www.digikey.ca/en/products/detail/raspberry-pi/SC0914-13/14306010 | 1.46 | SC0914(13) | 1.46
Y1 | 1 | H130B-12.000-20-3050-EXT-TR |  | Crystal:Crystal_SMD_5032-4Pin_5.0x3.2mm | ~ |  |  |  |  | https://www.digikey.ca/en/products/detail/raltron-electronics/H130B-12-000-20-3050-EXT-TR/13150898 | 0.52 | H130B-12.000-20-3050-EXT-TR | 0.52
 | 2 | 400 mAh lithium polymer batteries |  |  |  |  |  |  |  |  | 15 |  | 30
 | 3 | Lithium polymer battery charge controller |  |  | https://cdn.sparkfun.com/assets/learn_tutorials/6/9/5/MCP738312.pdf |  |  |  |  | https://www.digikey.ca/en/products/detail/microchip-technology/MCP73831T-2ACI-OT/964301 | 1.01 |  | 3.03
 | 1 | MT41K256M16TW-107 | DDR3 memory |  |  |  |  |  |  |  | 14.31 |  | 14.31
 | 1 | MCIMX6Z0DVM09AB | Applications processor |  |  |  |  |  |  |  | 8.88 |  | 8.88
 | 1 | RTL8723BS-VQ-CG | Wifi/BT module chip |  |  |  |  |  |  |  | 3.17 |  | 3.17
 |  |  |  |  |  |  |  |  |  |  |  |  | 0
 |  |  |  |  |  |  |  |  |  |  |  |  | 0
 |  |  |  |  |  |  |  |  |  |  |  |  | 0
 |  |  |  |  |  |  |  |  |  |  |  |  | 0
 |  |  |  |  |  |  |  |  |  |  |  |  | 0
 |  |  |  |  |  |  |  |  |  |  |  |  | 0
 |  |  |  |  |  |  |  |  |  |  |  | TOTAL: | 77.7768
 |  |  |  |  |  |  |  |  |  |  | Number of boards: | 3
 |  |  |  |  |  |  |  |  |  |  | Total Parts cost: |  | 233.3304
 |  |  |  |  |  |  |  |  |  |  | Rigid PCB 1 + stencil Cost (PCBWAY): |  | 94.68
 |  |  |  |  |  |  |  |  |  |  | Flex PCB + Stencil (PCBWAY): |  | 205.42
 |  |  |  |  |  |  |  |  |  |  | Estimated 3D print cost: |  | 15
 |  |  |  |  |  |  |  |  |  |  | Rigid PCB 2 + stencil cost (JLCPCB): |  | 202.14
 |  |  |  |  |  |  |  |  |  |  | Solder paste |  | 41.07 | https://www.amazon.ca/MG-Chemicals-Pneumatic-Dispenser-Dispensing/dp/B00M1RC0YY?rnid=11192166011
 |  |  |  |  |  |  |  |  |  |  | TOTAL: |  | $589.50

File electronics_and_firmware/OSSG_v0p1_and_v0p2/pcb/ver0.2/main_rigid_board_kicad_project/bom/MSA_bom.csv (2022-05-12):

Id | Designator | Package | Quantity | Designation | Supplier and ref
1 | R6 | R_0402_1005Metric | 1 | 470R
2 | U4 | QFN40P700X700X90-57N | 1 | RP2040
3 | J1 | USB-A | 1 | USB_A
4 | U3 | PSON50P300X200X60-9N | 1 | W25Q128JV
5 | J2 | SMD_1x04_P1.27mm | 1 | SWD Prog
6 | U1 | SOT-23 | 1 | MCP1702
7 | TP2 | SMD_1x01_P1.27mm | 1 | TestPoint
8 | C4,C10,C6,C11,C12,C13,C15,C7,C16,C14,C2,C20,C22,C24 | C_0402_1005Metric | 14 | 0.1uF
9 | C18,C19 | C_0402_1005Metric | 2 | 27pF
10 | C17,C1,C5 | C_0402_1005Metric | 3 | 10uF
11 | R3,R1,R8,R9,R10,R11,R12,R13,R14 | R_0402_1005Metric | 9 | 10K
12 | C9,C8,C3,C21,C23,C25 | C_0402_1005Metric | 6 | 1uF
13 | R4,R5 | R_0402_1005Metric | 2 | 27R
14 | R7,R2 | R_0402_1005Metric | 2 | 1K
15 | Y1 | Crystal_SMD_5032-4Pin_5.0x3.2mm | 1 | H130B-12.000-20-3050-EXT-TR
16 | TP1 | SMD_1x02_P1.27mm | 1 | TestPoint_2Pole
17 | D1 | LED_0402_1005Metric | 1 | APA3010SECK
18 | FID1,FID2,FID3 | Fiducial_0.5mm_Mask1mm | 3 | Fiducial
19 | U2,U5,U6,U7 | MIC_SPH0641LU4H-1 | 4 | MP23DB01HPTR

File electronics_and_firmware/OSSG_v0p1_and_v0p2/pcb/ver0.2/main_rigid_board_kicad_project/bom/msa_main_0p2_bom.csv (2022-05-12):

Id | Designator | Package | Quantity | Designation | Supplier and ref
1 | R5,R4 | R_0402_1005Metric | 2 | 27R
2 | D2 | LED_0402_1005Metric | 1 | LED
3 | Y1 | Crystal_SMD_5032-4Pin_5.0x3.2mm | 1 | H130B-12.000-20-3050-EXT-TR
4 | C16,C15,C6,C4,C13,C7,C10,C11,C12,C14 | C_0402_1005Metric | 10 | 0.1uF
5 | R10 | R_0402_1005Metric | 1 | NC
6 | CONN1 | slim_stack_molex_RECEPTACLE_5035481222 | 1 | slim_stack_receptable_12pos_5035481222_schematic
7 | C5,C1,C17 | C_0402_1005Metric | 3 | 10uF
8 | U5 | SOT-523 | 1 | ‎DMP21D0UT-7‎
9 | D3 | D_SOD-323F | 1 | PMEG2010AEJ
10 | J1 | micro_usb_right_angle_1050170001_molex | 1 | USB_B_Micro
11 | C3,C2 | C_0402_1005Metric_Pad0.74x0.62mm_HandSolder | 2 | 4.7uF
12 | R1 | C_0402_1005Metric_Pad0.74x0.62mm_HandSolder | 1 | 470
13 | C19,C18 | C_0402_1005Metric | 2 | 27pF
14 | R8 | C_0402_1005Metric_Pad0.74x0.62mm_HandSolder | 1 | 10k
15 | R2,R7 | R_0402_1005Metric | 2 | 1K
16 | U1 | SOT-23 | 1 | MCP1702
17 | H1,H2 | Mount_hole_small_0.7mm | 2 | MountingHole
18 | R3 | R_0402_1005Metric | 1 | 10K
19 | C8,C9 | C_0402_1005Metric | 2 | 1uF
20 | D1 | LED_0402_1005Metric | 1 | APA3010SECK
21 | C20 | C_0402_1005Metric_Pad0.74x0.62mm_HandSolder | 1 | 1uF
22 | U2 | SOT-23-5 | 1 | MCP73831-2-OT
23 | U3 | PSON50P300X200X60-9N | 1 | W25Q128JV
24 | U4 | QFN40P700X700X90-57N | 1 | RP2040
25 | TP9,TP3,TP6,TP4,TP5,TP2 | SMD_1x01_P1.27mm | 6 | TestPoint
26 | R9 | C_0402_1005Metric_Pad0.74x0.62mm_HandSolder | 1 | 100k
27 | TP1 | SMD_1x02_P1.27mm | 1 | TestPoint_2Pole
28 | SW1 | SW_SPST_B3U-3100P-B | 1 | SW_SPST
29 | R6 | R_0402_1005Metric | 1 | 470R
30 | J2 | SMD_1x04_P1.27mm | 1 | SWD Prog
31 | BT1 | BatterySolderOn | 1 | Battery_Cell

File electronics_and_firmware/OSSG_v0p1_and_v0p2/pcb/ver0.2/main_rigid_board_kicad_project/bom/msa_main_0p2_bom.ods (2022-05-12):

Id | Designator | Package | Quantity | Designation | Manufacturer Part Number | Cost | Digikey PN | Notes
1 | R5,R4 | R_0402_1005Metric | 2 | 27R | RMCF0402FT27R0 | 0.01018 | 1276-3970-1-ND
2 | D2 | LED_0402_1005Metric | 1 | LED | EAST1005RA0 | 0.44 | 1080-EAST1005RA0CT-ND
3 | Y1 | Crystal_SMD_5032-4Pin_5.0x3.2mm | 1 | H130B-12.000-20-3050-EXT-TR | H130B-12.000-20-3050-EXT-TR | 0.52 | 2151-H130B-12.000-20-3050-EXT-TRCT-ND - Cut Tape |  | Part Number | Manufacturer Part Number | Description
4 | C16,C15,C6,C4,C13,C7,C10,C11,C12,C14 | C_0402_1005Metric | 14 | 0.1uF | CL05A104KA5NNNC | 0.0082 | 1276-1043-1-ND |  | 23-5035521222CT-ND | 5035521222 | CONN PLUG 12POS SMD GOLD
5 | R10 | R_0402_1005Metric | 1 | NC | RC0402JR-070RP | 0.032 | YAG1279CT-ND |  | 23-5035481222CT-ND | 5035481222 | CONN RCPT 12POS SMD GOLD
6 | CONN1 | slim_stack_molex_RECEPTACLE_5035481222 | 1 | slim_stack_receptable_12pos_5035481222_schematic | 5035481222 | 1.041 | 23-5035481222CT-ND |  | 1727-3857-1-ND | PMEG2010AEJ,115 | DIODE SCHOTTKY 20V 1A SOD323F
7 | C5,C1,C17 | C_0402_1005Metric | 3 | 10uF | CL05A106MP5NUNC | 0.181 | 1276-1450-1-ND |  | DMP21D0UT-7DICT-ND | DMP21D0UT-7 | MOSFET P-CH 20V 590MA SOT523
8 | U5 | SOT-523 | 1 | ‎DMP21D0UT-7‎ | DMP21D0UT-7 | 0.425 | DMP21D0UT-7DICT-ND |  | MCP73831T-2ACI/OTCT-ND | MCP73831T-2ACI/OT | IC BATT CNTL LI-ION 1CEL SOT23-5
9 | D3 | D_SOD-323F | 1 | PMEG2010AEJ | PMEG2010AEJ,115 | 0.497 | 1727-3857-1-ND |  | WM1399CT-ND | 1050170001 | CONN RCPT USB2.0 MICRO B SMD R/A
10 | J1 | micro_usb_right_angle_1050170001_molex | 1 | USB_B_Micro | 1050170001 | 1.09 | WM1399CT-ND |  | SW1103CT-ND | B3U-3100P-B | SWITCH TACTILE SPST-NO 0.05A 12V
11 | C3,C2 | C_0402_1005Metric_Pad0.74x0.62mm_HandSolder | 2 | 4.7uF | GRM155R60G475ME47D | 0.17 | 490-11980-1-ND |  | 1080-EAST1005RA0CT-ND | EAST1005RA0 | LED RED CLEAR 2SMD
12 | R1 | C_0402_1005Metric_Pad0.74x0.62mm_HandSolder | 1 | 470 | RMCF0402FT470R | 0.022 | 738-RMCF0402FT470RCT-ND |  | 1080-EAST1005BA0CT-ND | EAST1005BA0 | LED BLUE CLEAR 2SMD
13 | C19,C18 | C_0402_1005Metric | 2 | 27pF | CC0402JRNPO9BN270 | 0.17 | 311-1019-1-ND |  | YAG1279CT-ND | RC0402JR-070RP | RES SMD 0 OHM JUMPER 1/16W 0402
14 | R8 | C_0402_1005Metric_Pad0.74x0.62mm_HandSolder | 1 | 10k | RMCF0402JT10K0 | 0.153 | RMCF0402JT10K0CT-ND | *same as 10K below, should change footprint | 490-11980-1-ND | GRM155R60G475ME47D | CAP CER 4.7UF 4V X5R 0402
15 | R2,R7 | R_0402_1005Metric | 2 | 1K | RMCF0402FT1K00 | 0.034 | RMCF0402FT1K00CT-ND |  | 541-100KJCT-ND | CRCW0402100KJNED | RES SMD 100K OHM 5% 1/16W 0402
16 | U1 | SOT-23 | 1 | MCP1702 | AP130-33RG-7 | 0.85 | AP130-33RGDICT-ND | * swapped this out because MCP1702 out of stock | AP130-33RGDICT-ND | AP130-33RG-7 | IC REG LINEAR 3.3V 300MA SC59R
17 | R3 | R_0402_1005Metric | 1 | 10K | RMCF0402JT10K0 | 0.15 | RMCF0402JT10K0CT-ND
18 | C8,C9 | C_0402_1005Metric | 2 | 1uF | GRT155C80J105KE01J | 0.14 | 490-GRT155C80J105KE01JCT-ND
19 | D1 | LED_0402_1005Metric | 1 | APA3010SECK | EAST1005BA0 | 0.36 | 1080-EAST1005RA0CT-ND | *wrong designation, but this is the correct supplier for 0402 led
20 | C20 | C_0402_1005Metric_Pad0.74x0.62mm_HandSolder | 1 | 1uF | GRT155C80J105KE01J | 0.14 | 490-GRT155C80J105KE01JCT-ND
21 | U2 | SOT-23-5 | 1 | MCP73831-2-OT | MCP73831T-2ACI/OT | 1.01 | MCP73831T-2ACI/OTCT-ND
22 | U3 | PSON50P300X200X60-9N | 1 | W25Q128JV | W25Q80DVUXIE | 0.92 | W25Q80DVUXIECT-ND
23 | U4 | QFN40P700X700X90-57N | 1 | RP2040 | SC0914(13) | 1.46 | 2648-SC0914(13)CT-ND
24 | R9 | C_0402_1005Metric_Pad0.74x0.62mm_HandSolder | 1 | 100k | CRCW0402100KJNED | 0.15 | 497-MP23DB01HPCT-ND
25 | SW1 | SW_SPST_B3U-3100P-B | 1 | SW_SPST | B3U-3100P-B | 1.436 | SW1103CT-ND
26 | R6 | R_0402_1005Metric | 1 | 470R | RMCF0402FT470R | 0.022 | 738-RMCF0402FT470RCT-ND
27 | C25,C3,C23,C21 | C_0402_1005Metric | 4 | 1uF | GRT155C80J105KE01J | 0.081 | 490-GRT155C80J105KE01JCT-ND
28 | R10,R12,R8,R13,R11,R9,R14,R1 | R_0402_1005Metric | 8 | 10K | CL05A106MP5NUNC | 0.181 | 1276-1450-1-ND
29 | CONN1 | slim_stack_molex_PLUG_5035521222 | 1 | slim_stack_12pos_5035521222_schematic | 5035521222 | 1.075 | 23-5035521222CT-ND
30 | U6,U5,U2,U7 | MIC_SPH0641LU4H-1 | 4 | MP23DB01HPTR | MP23DB01HPTR | 2.52 | 497-MP23DB01HPCT-ND
 |  |  |  |  | EAST1005BA0 | 0.36 | 1080-EAST1005BA0CT-ND
 |  | TOTAL: |  |  |  | 15.64838
 |  | Main/Rigid board JLCPCB cost: | 55 | 10
 |  | Flex PCBWAY cost: | 180 | 10
 |  | Price per board: | 39.14838

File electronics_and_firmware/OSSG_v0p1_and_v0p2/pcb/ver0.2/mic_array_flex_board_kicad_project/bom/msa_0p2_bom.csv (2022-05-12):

Id | Designator | Package | Quantity | Designation | Supplier and ref
1 | C25,C3,C23,C21 | C_0402_1005Metric | 4 | 1uF
2 | R10,R12,R8,R13,R11,R9,R14,R1 | R_0402_1005Metric | 8 | 10K
3 | TP8,TP2,TP10,TP11,TP1,TP7 | SMD_1x01_P1.27mm | 6 | TestPoint
4 | C24,C2,C20,C22 | C_0402_1005Metric | 4 | 0.1uF
5 | CONN1 | slim_stack_molex_PLUG_5035521222 | 1 | slim_stack_12pos_5035521222_schematic
6 | U6,U5,U2,U7 | MIC_SPH0641LU4H-1 | 4 | MP23DB01HPTR

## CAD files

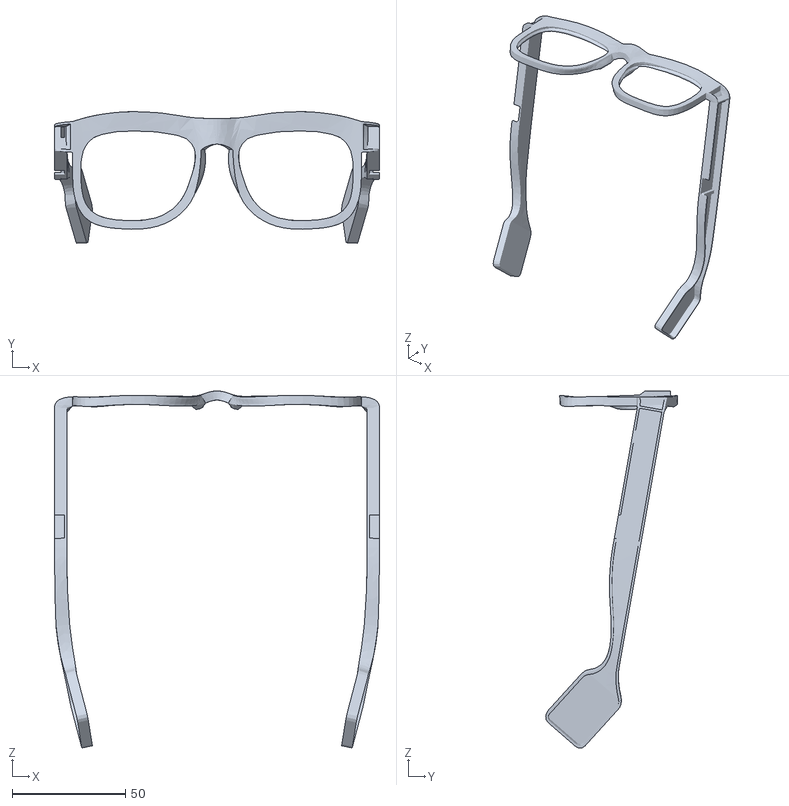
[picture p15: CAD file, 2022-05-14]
mechanical/MAIN_3DPRINT_OSSG_0p2.stl
143.6 x 58.1 x 157.7

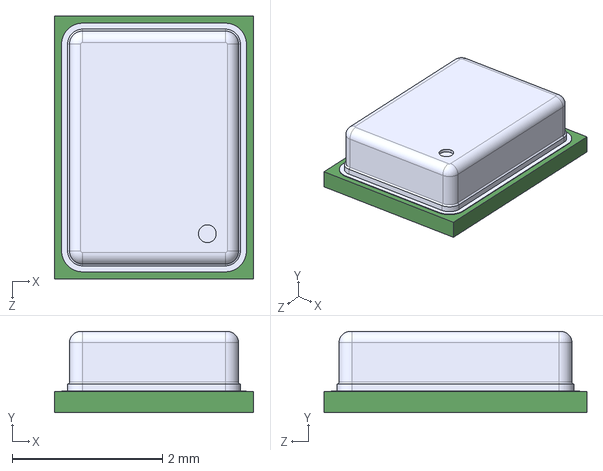
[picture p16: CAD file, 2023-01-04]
electronics_and_firmware/endpiece_mic_board_v0p2/3dmodels/SPH0645LM4H-B.step
2.65 x 1.08 x 3.50 mm

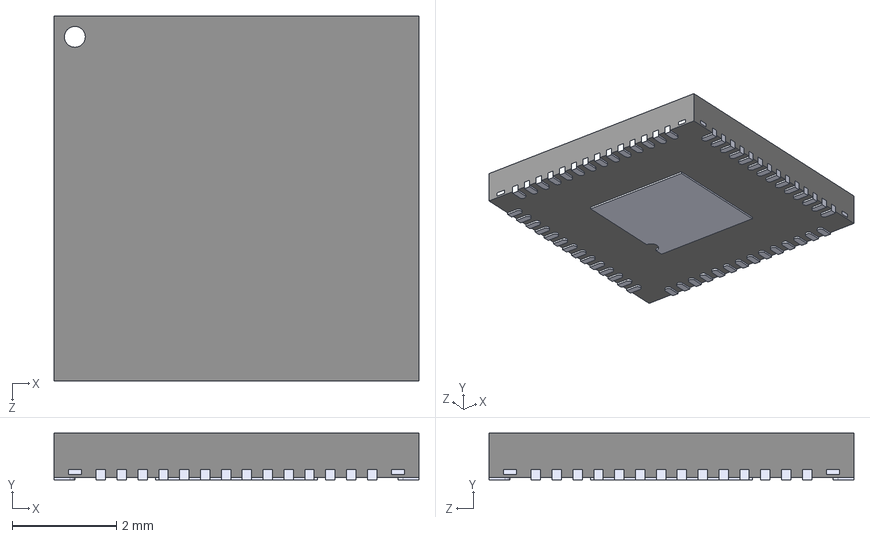
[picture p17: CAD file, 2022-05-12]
electronics_and_firmware/OSSG_v0p1_and_v0p2/pcb/RP2040--3DModel-STEP-269445.STEP
7.00 x 0.9 x 7.00 mm

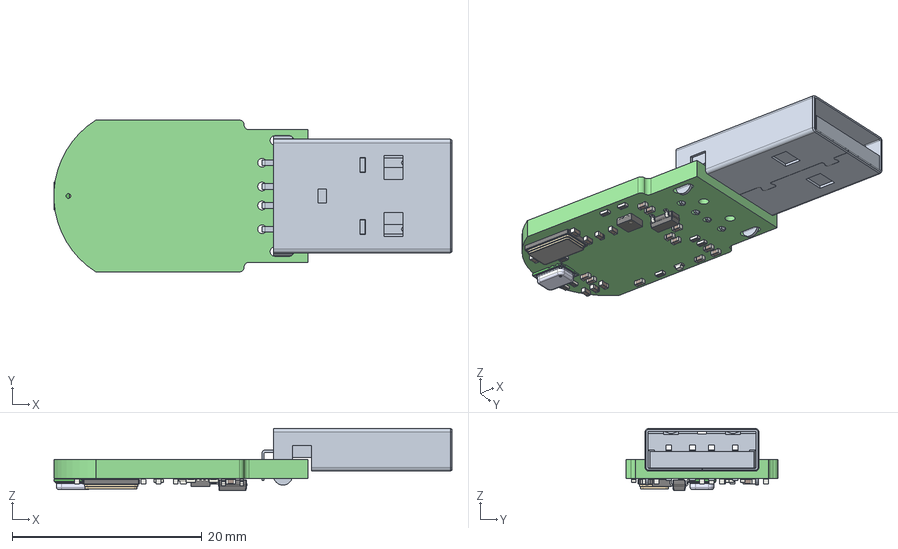
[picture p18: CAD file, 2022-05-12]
electronics_and_firmware/OSSG_v0p1_and_v0p2/pcb/ver0.2/main_rigid_board_kicad_project/mico.step
41.9 x 16.0 x 6.55 mm

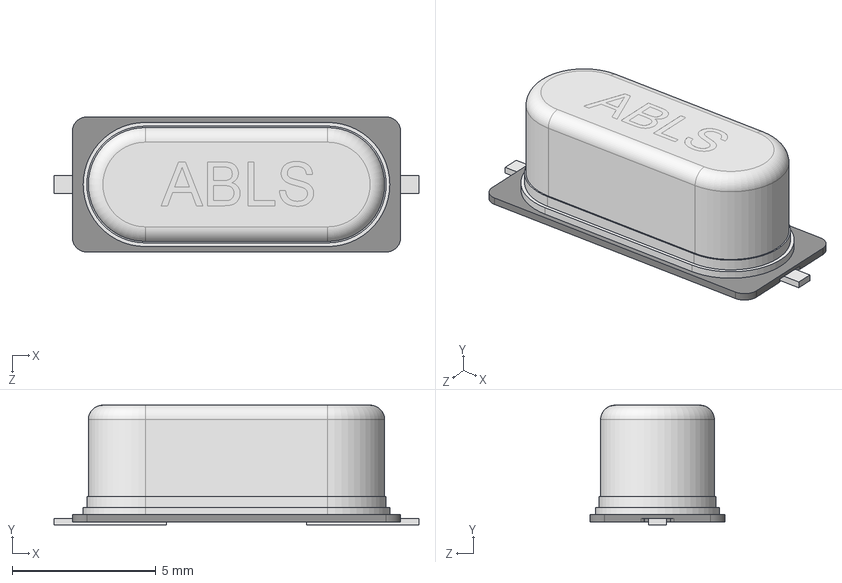
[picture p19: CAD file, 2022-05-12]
electronics_and_firmware/OSSG_v0p1_and_v0p2/pcb/ver0.2/main_rigid_board_kicad_project/step/XTAL1140X470X420N.step
12.7 x 4.17 x 4.70 mm

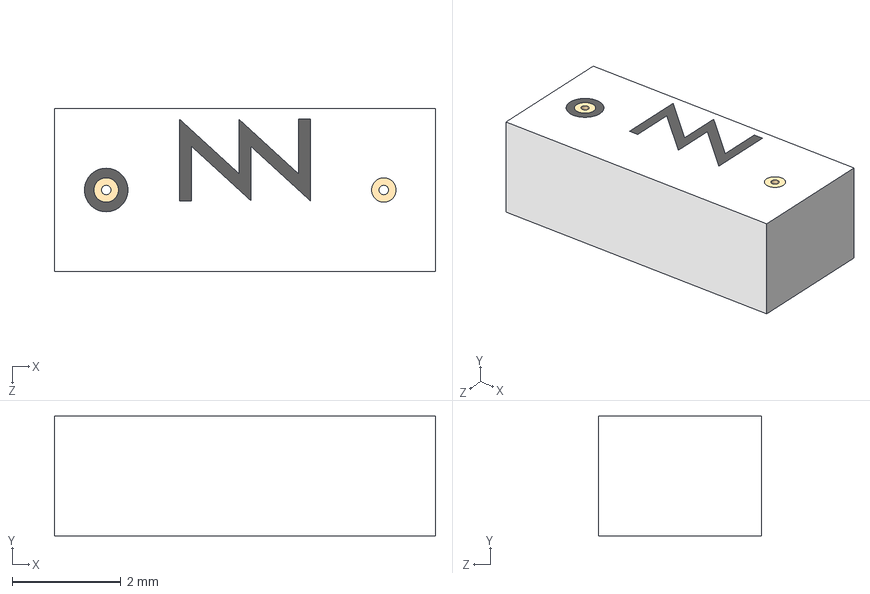
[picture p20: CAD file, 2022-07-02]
electronics_and_firmware/OSSG_v0p5/NN01-102.step
7.00 x 2.20 x 3.00 mm

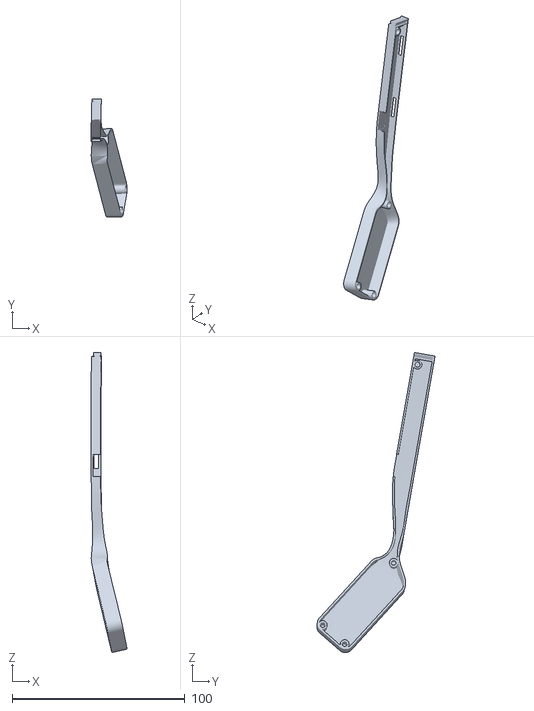
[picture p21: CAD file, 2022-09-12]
mechanical/ARM_RIGHT_3DPRINT_OSSG_0p3.stl
20.9 x 68.3 x 173.5

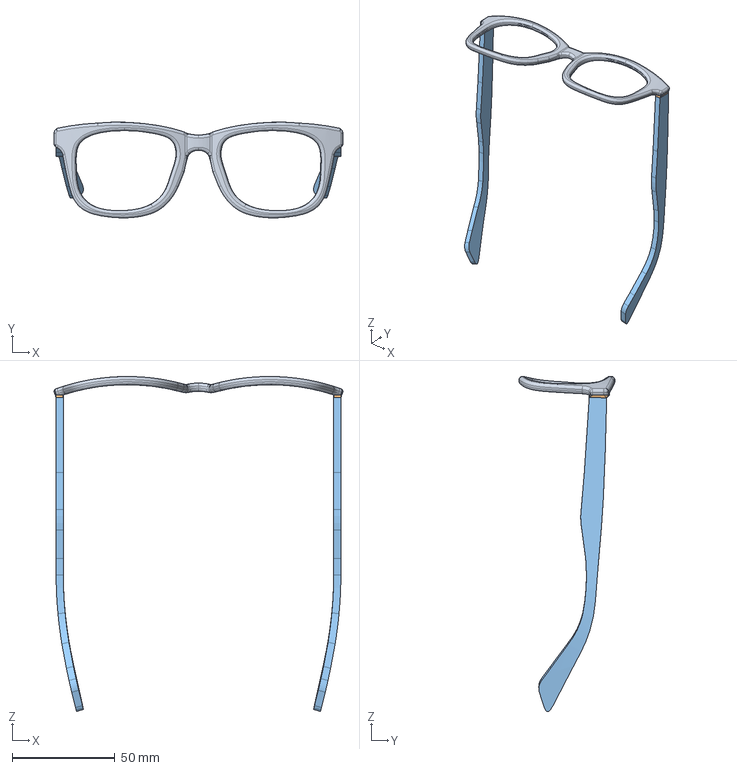
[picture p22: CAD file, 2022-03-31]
Zenni_onePiece_largerArms.stp
140.4 x 46.5 x 162.9 mm

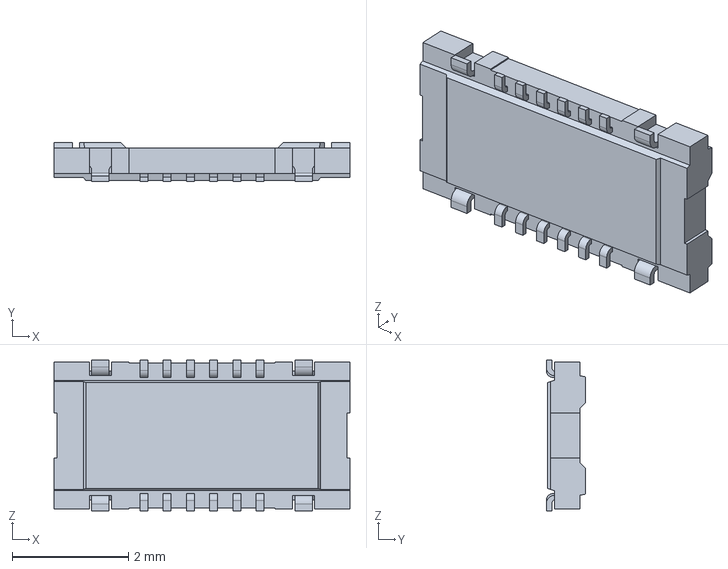
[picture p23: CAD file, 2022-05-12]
electronics_and_firmware/OSSG_v0p1_and_v0p2/pcb/slim_stack_molex_receptacle_12pox_5035481222.stp
5.10 x 0.68 x 2.60 mm

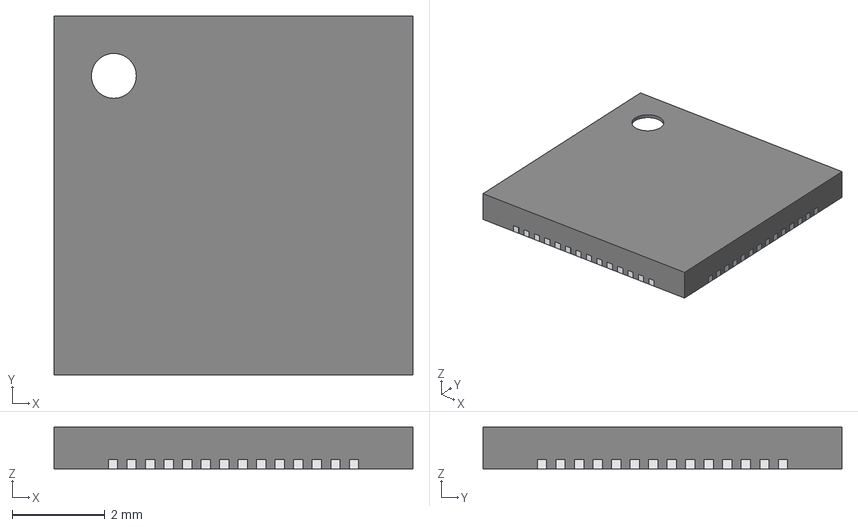
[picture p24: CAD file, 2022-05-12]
electronics_and_firmware/OSSG_v0p1_and_v0p2/pcb/ver0.2/main_rigid_board_kicad_project/step/RP2040.step
7.75 x 7.75 x 0.901 mm
Open_CASCADE_STEP_translator_6.8_5.1
Open_CASCADE_STEP_translator_6.8_5.2.1
Thermal_Shape
Open_CASCADE_STEP_translator_6.8_5.4.1 x 56

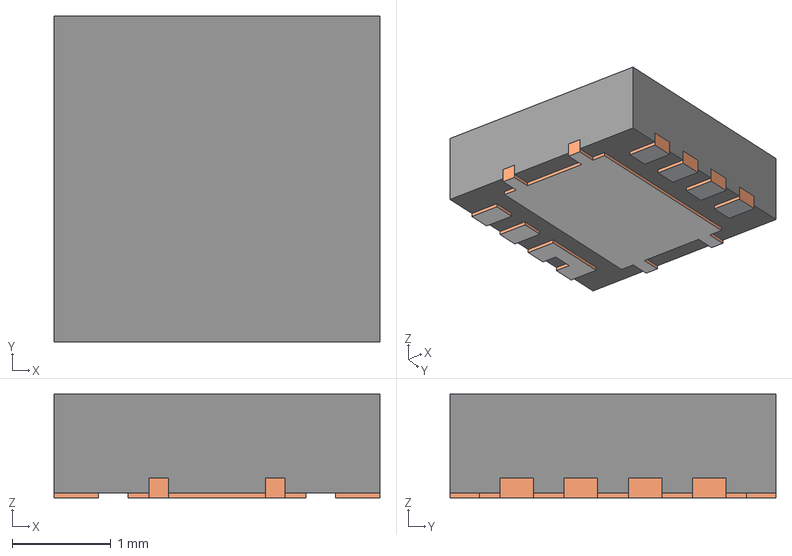
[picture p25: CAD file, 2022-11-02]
electronics_and_firmware/OSSG_v0p5/3dmodels/SON8_3.3x3.3.stp
3.30 x 3.30 x 1.05 mm
BODY-SON
FRAME-DPB0008A
PIN1-ID

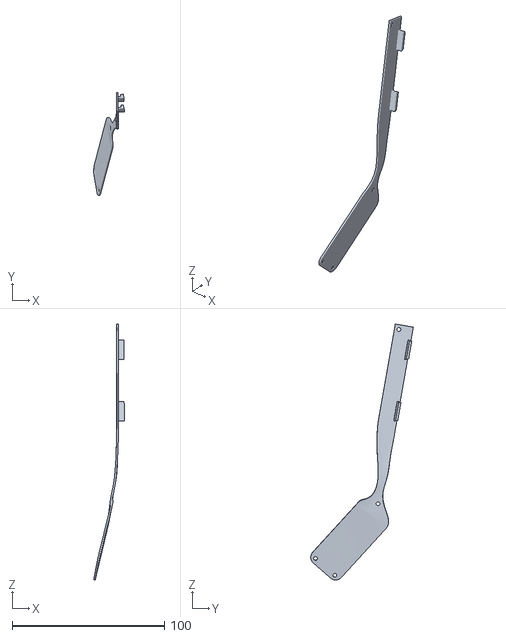
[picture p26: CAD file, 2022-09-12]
mechanical/ARM_COVER_LEFT_3DPRINT_OSSG_0p3.stl
20.1 x 67.4 x 168.1

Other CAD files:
Zenni125221.stp
Zenni125221_hingesV2.stp
combined_hardware_electronics_OSSG_v1.f3z
electronics_and_firmware/OSSG_v0p1_and_v0p2/pcb/1050170001.stp
electronics_and_firmware/OSSG_v0p1_and_v0p2/pcb/1051330001.stp
electronics_and_firmware/OSSG_v0p1_and_v0p2/pcb/mic_array_flex_board_kicad_project.step
electronics_and_firmware/OSSG_v0p1_and_v0p2/pcb/slim_stack_molex_PLUG_5035521222.stp
electronics_and_firmware/OSSG_v0p5/3dmodels/1.5uH-4.5x4mm.step
electronics_and_firmware/OSSG_v0p5/3dmodels/ANT3216LL-Antenna-Chip.step
electronics_and_firmware/OSSG_v0p5/3dmodels/B3U-3100P-B--3DModel-STEP-56544.STEP
electronics_and_firmware/OSSG_v0p5/3dmodels/ESP32-PICO-D4--3DModel-STEP-56544.STEP
electronics_and_firmware/OSSG_v0p5/3dmodels/ESP32-PICO-D4.step
electronics_and_firmware/OSSG_v0p5/3dmodels/NCP167BMX330TBG.step
electronics_and_firmware/OSSG_v0p5/3dmodels/PRO-OB-440.step
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

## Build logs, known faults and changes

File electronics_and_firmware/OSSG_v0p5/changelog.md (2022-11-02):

# OpenSource Smartglass Project
---

##PCB Versions:

### Version 0.5

Production: JLCPCB, 4 layer, blue
Date: TBD

- see if the BQ25887 a 4mm2 24pin 2S charger with built in balancer is avalable
- addin i2S audio amplifier, or a piezo MEMS speaker

### Version 0.4a

Production: JLCPCB, 4 layer, blue
Date: TBD

- change backside font from 0.07mm thick to a 0.11mm thickness
- change R15 and R16 from 10K to 4.7K on schematic (i2C pullup resistor values could go down to 2.7K if needed)
- added Left/Right text to Microphone selection on schematic
- add a pin 1 Dot to IC's
- moved User switch 0.35mm up and a bit to the front edge of PCB
- moved R8 text to board edge
- decreased C14 font size

### Version 0.4

Production: JLCPCB, 4 layer, green
Date: 2022-09-22

- fix ESP32-Pico 3.3VA to 3.3V missing connection
- swap out external PDM microphone for SPH0645/ICS-43434 i2S microphone footprint.  Keep onboard PDM microphone
- addin breakout for extra i2S microphone channel
- addin on/off switch, via MOSFET control, or EN pin on a LDO
- addin provision for a RGB LEDs on reverse side of board
- swap out TP4056 for a AP5054 SOT23-5 battery charger
- add a SY7088 3V to 5V boost DC-DC converter
- add in MAX17048 i2C based Fuel Gauge IC
- add on a touch senser breakout connector pads

### Version 0.3

Production: JLCPCB, 4 layer, green
Date: 2022 August 

- ESP32-Pico-D4 MCU
- PDM over i2S microphones
- TP4056 battery charger

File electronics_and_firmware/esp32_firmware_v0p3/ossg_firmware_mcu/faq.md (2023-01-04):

# Info // FaQ // QnA // Common questions // whatever

**WARNING: Pretty much everything here is subject to change**

## What is the current status of the project?

Here is a link to our todo list / roadmap: (to be inserted)

## What is the current hardware setup?

* ESP32-PICO-D4 with 4mb spiram (I use a TinyPico for development)
* display module with CVBS driver board
* I2s microphone
* Android phone running the WearableIntelligenceSystem app

#### Why an ESP32, and not an Android-based SoC (or other applications processor)?

Size, power consumption, availability, cost, etc are all issues that come with application processors, when all we really need from a client (the glasses) is a display, microphone, and wireless communication with the head unit (Android device).

## What display is (currently) being used

We are using the SONY ECX336C + CVBS driver board + (what our supplier calls the) "freeform optics". 

Some suppliers refer to it as the "OL23C" display module.

#### How can I get one?

You can find them on Alibaba, however, ordering this way tends to be pretty expensive. You may have to message the seller for single unit pricing. We're getting them cheaper @ ~$170/singleUnit directly from a supplier, and will consider doing a bulk order (even cheaper) if enough people are interested. 

NOTE: The freeform optics are only compatible with the ECX336C/OL23C and NOT the older ECX336A/OL23A display module. If you intend on buying the display and freeform optics separately (if that's even possible), make sure you buy the correct display. As far as I know, the only other difference is that the ECX336C/OL23C outputs to a max brightness of 3000cd/m2, while the ECX336A/OL23A only outputs to a max brightness of 800cd/m2.

#### How is the display attached to the optics?

The display + freeform optics come glued together.

## I'd love to contribute to the OSSG firmware, but can't dump hundreds on display hardware! What alternatives exist?

* If you still want a display, I'd recommend the SON-FL08 module. These are about $60 and come with a CVBS driver board and a magnifier. You will need to source your own prism (about $10). For an example of it in action (and links to buy), check out my [Telescope](https://github.com/alex1115alex/wearables-telescope) project.

* If you don't care about the display and just want to contribute while spending the least money, get a Composite-To-USB capture card from Amazon/etc for ~$10. More information about using this in the Telescope readme. 

## Is the “v1” release going to be self-built, or will it come pre-assembled?

As an open source project, you will always be able to build your own OSSG unit. Also, Cayden's company is selling prebuilt units, right now beta units, to help fund the project. You can sign up here: https://us9.list-manage.com/survey?u=18bb4d67053a9c3e4de35fe89&id=586a36974c

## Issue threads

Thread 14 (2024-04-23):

2024 status

joukepouke-personal, 2024-04-23:
is this still developed/supported? can i build and use these glasses?

shaojun, 2024-08-22:
Same question

CaydenPierce, 2024-08-30:
The lead developers (myself and @alex1115alex) are currently focusing our efforts on open source smart glasses software: https://github.com/TeamOpenSmartGlasses/AugmentOS

To develop this much further would require some serious funding, outside of me bankrupting myself in 2022/23 to make this happen, lol

This project should still fully work in 2024. May require a part or 2 swapped due to supply chain.

CommanderPho, 2024-11-22:
I'm interested also, is the latest PCB "OSSG_v0p5"?

alex1115alex, 2024-11-27:
^^^ OSSG is no longer in development, but you can find the latest changes on the release/v1.1 branch.

https://github.com/TeamOpenSmartGlasses/OpenSourceSmartGlasses/tree/release-v1.1

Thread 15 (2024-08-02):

Question regarding the hardware component. (Lens)

Kishlay-notabot, 2024-08-02:
If we could get a specific term, or type or name of the lens, or some schematic or blueprint, we can further delve deep to find places to reproduce it.
1. In the example images, is the glass lens made of acrylic?
2. How does the projection work? And don't we feel strain trying to focus on something so close to our eyes?
If these questions aren't appropriate from the repository's context, please redirect it to somewhere where the hardware can be discussed. Thankyou

CaydenPierce, 2024-08-30:
We bought off the shelf free-form optics, as discussed in the build guide.

It's not focused close to your eye, it's focused 1/2 meters away.

Further discussion feel free to join our discord

Kishlay-notabot, 2024-08-30:
thanks for the reply.

Closed 2024-08-30.

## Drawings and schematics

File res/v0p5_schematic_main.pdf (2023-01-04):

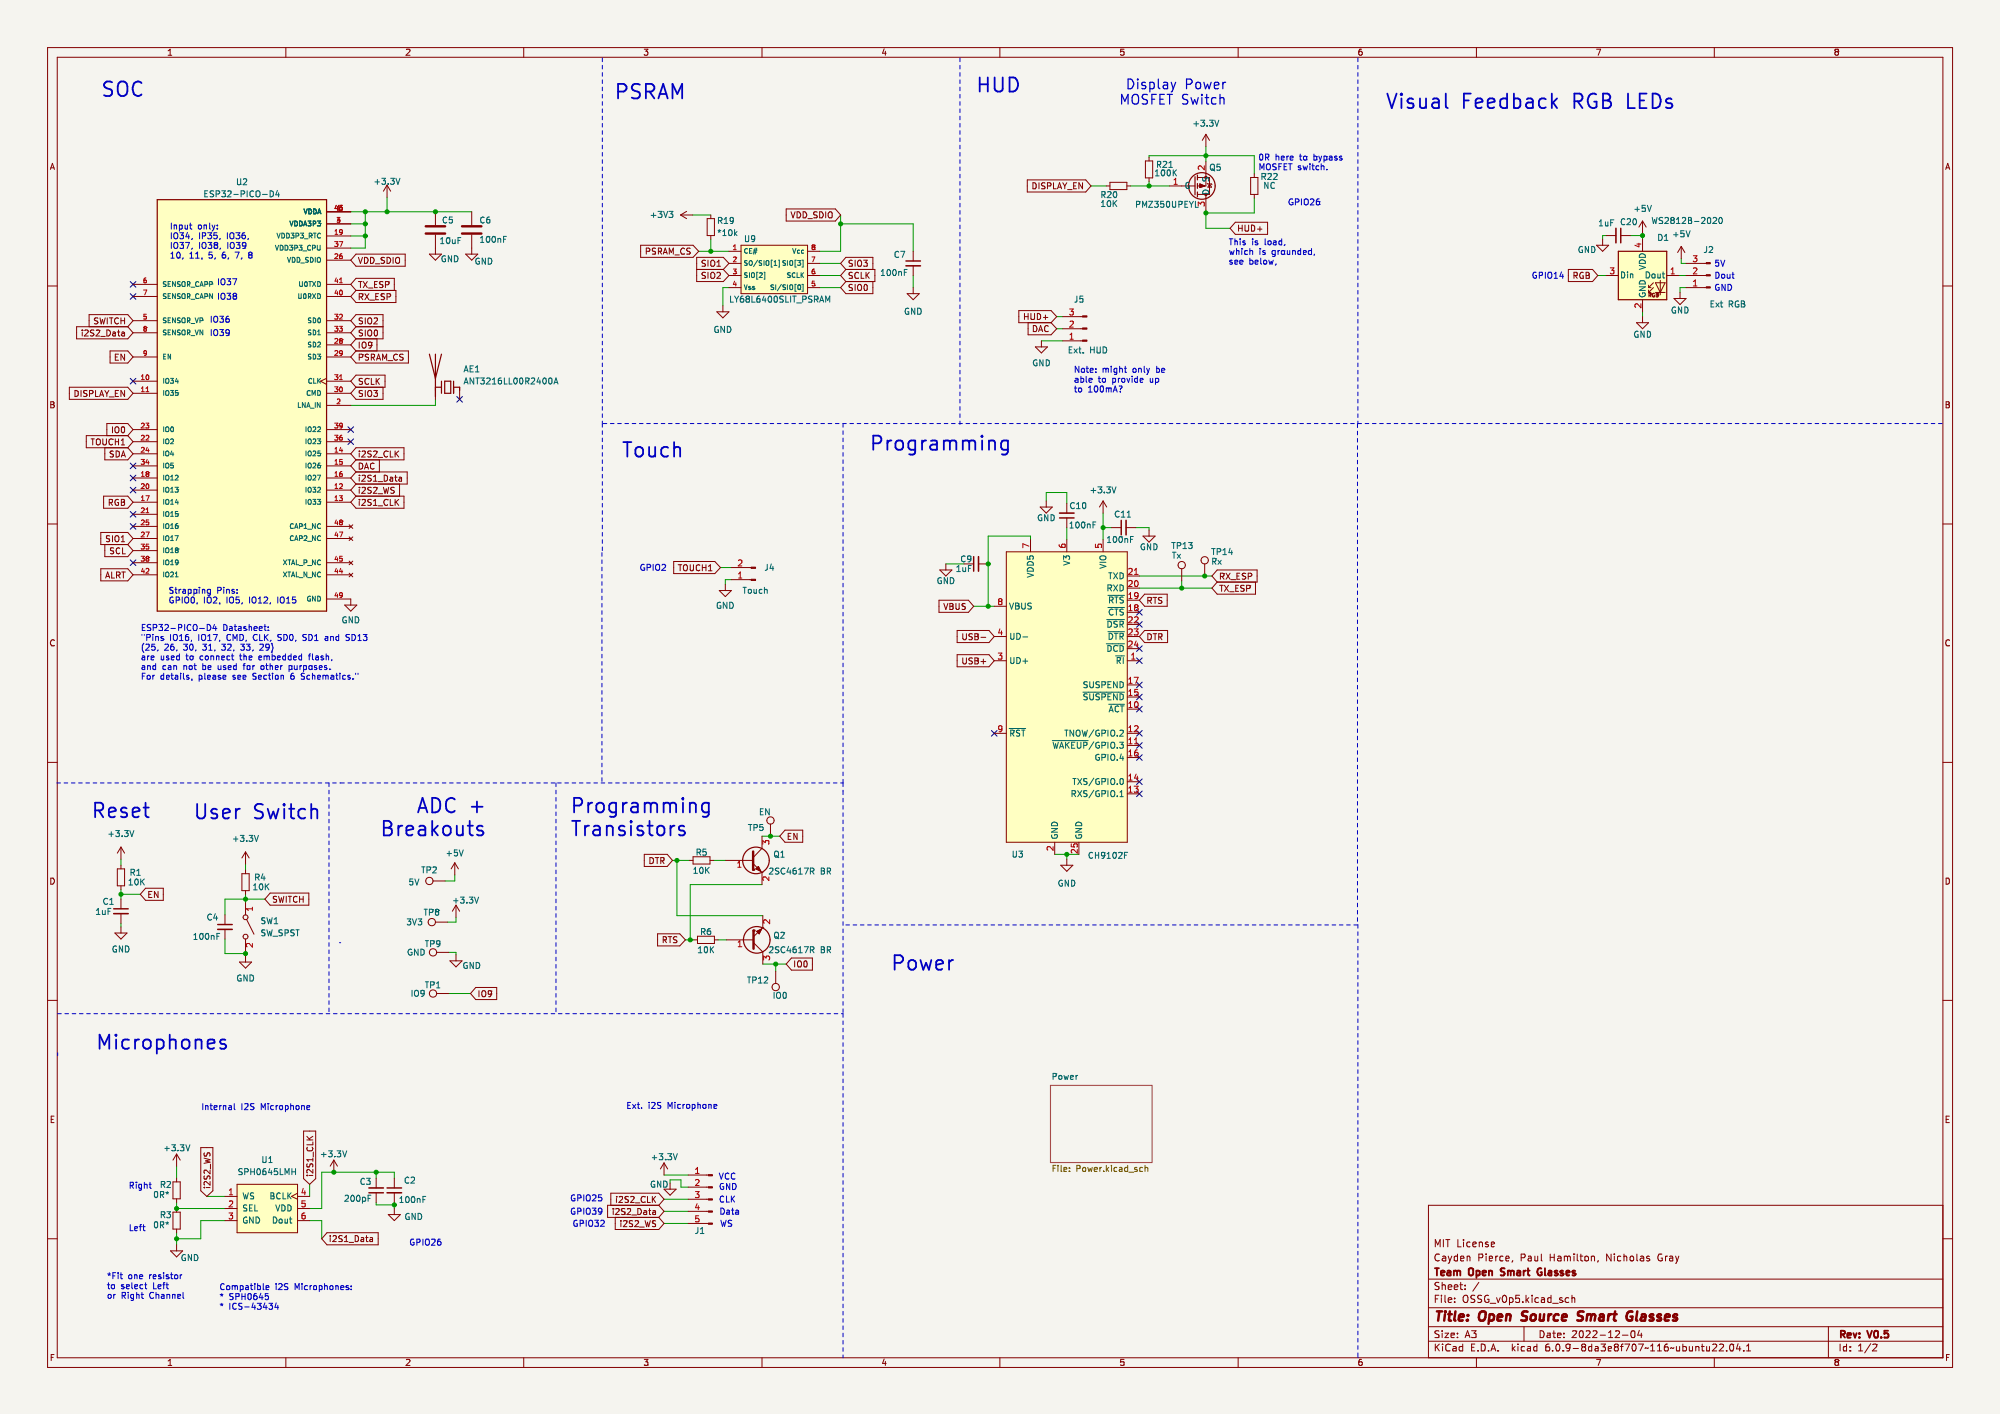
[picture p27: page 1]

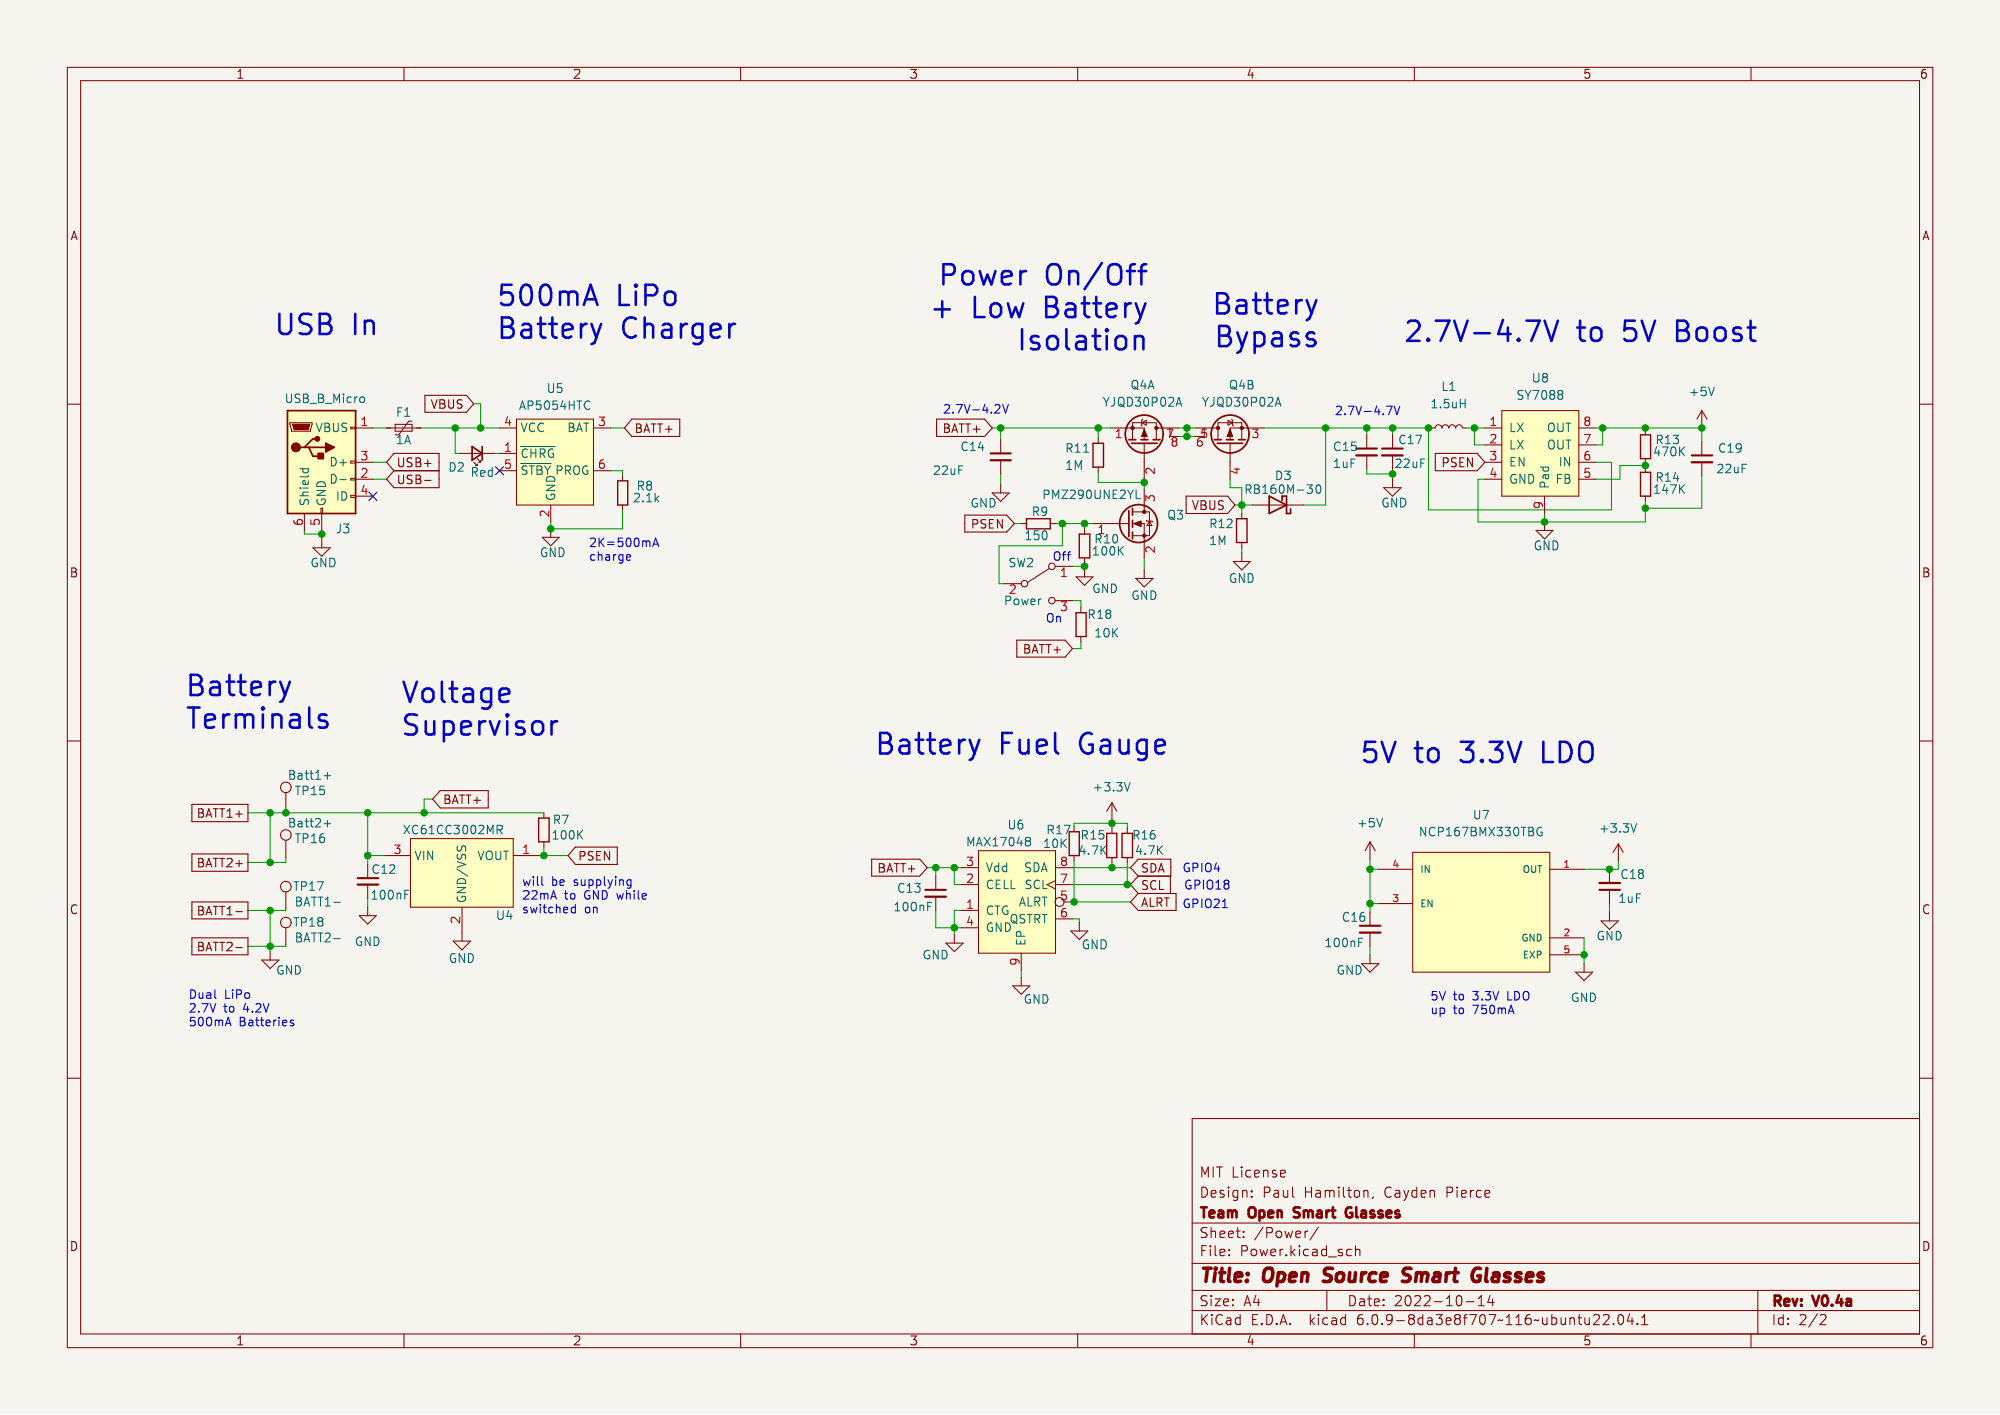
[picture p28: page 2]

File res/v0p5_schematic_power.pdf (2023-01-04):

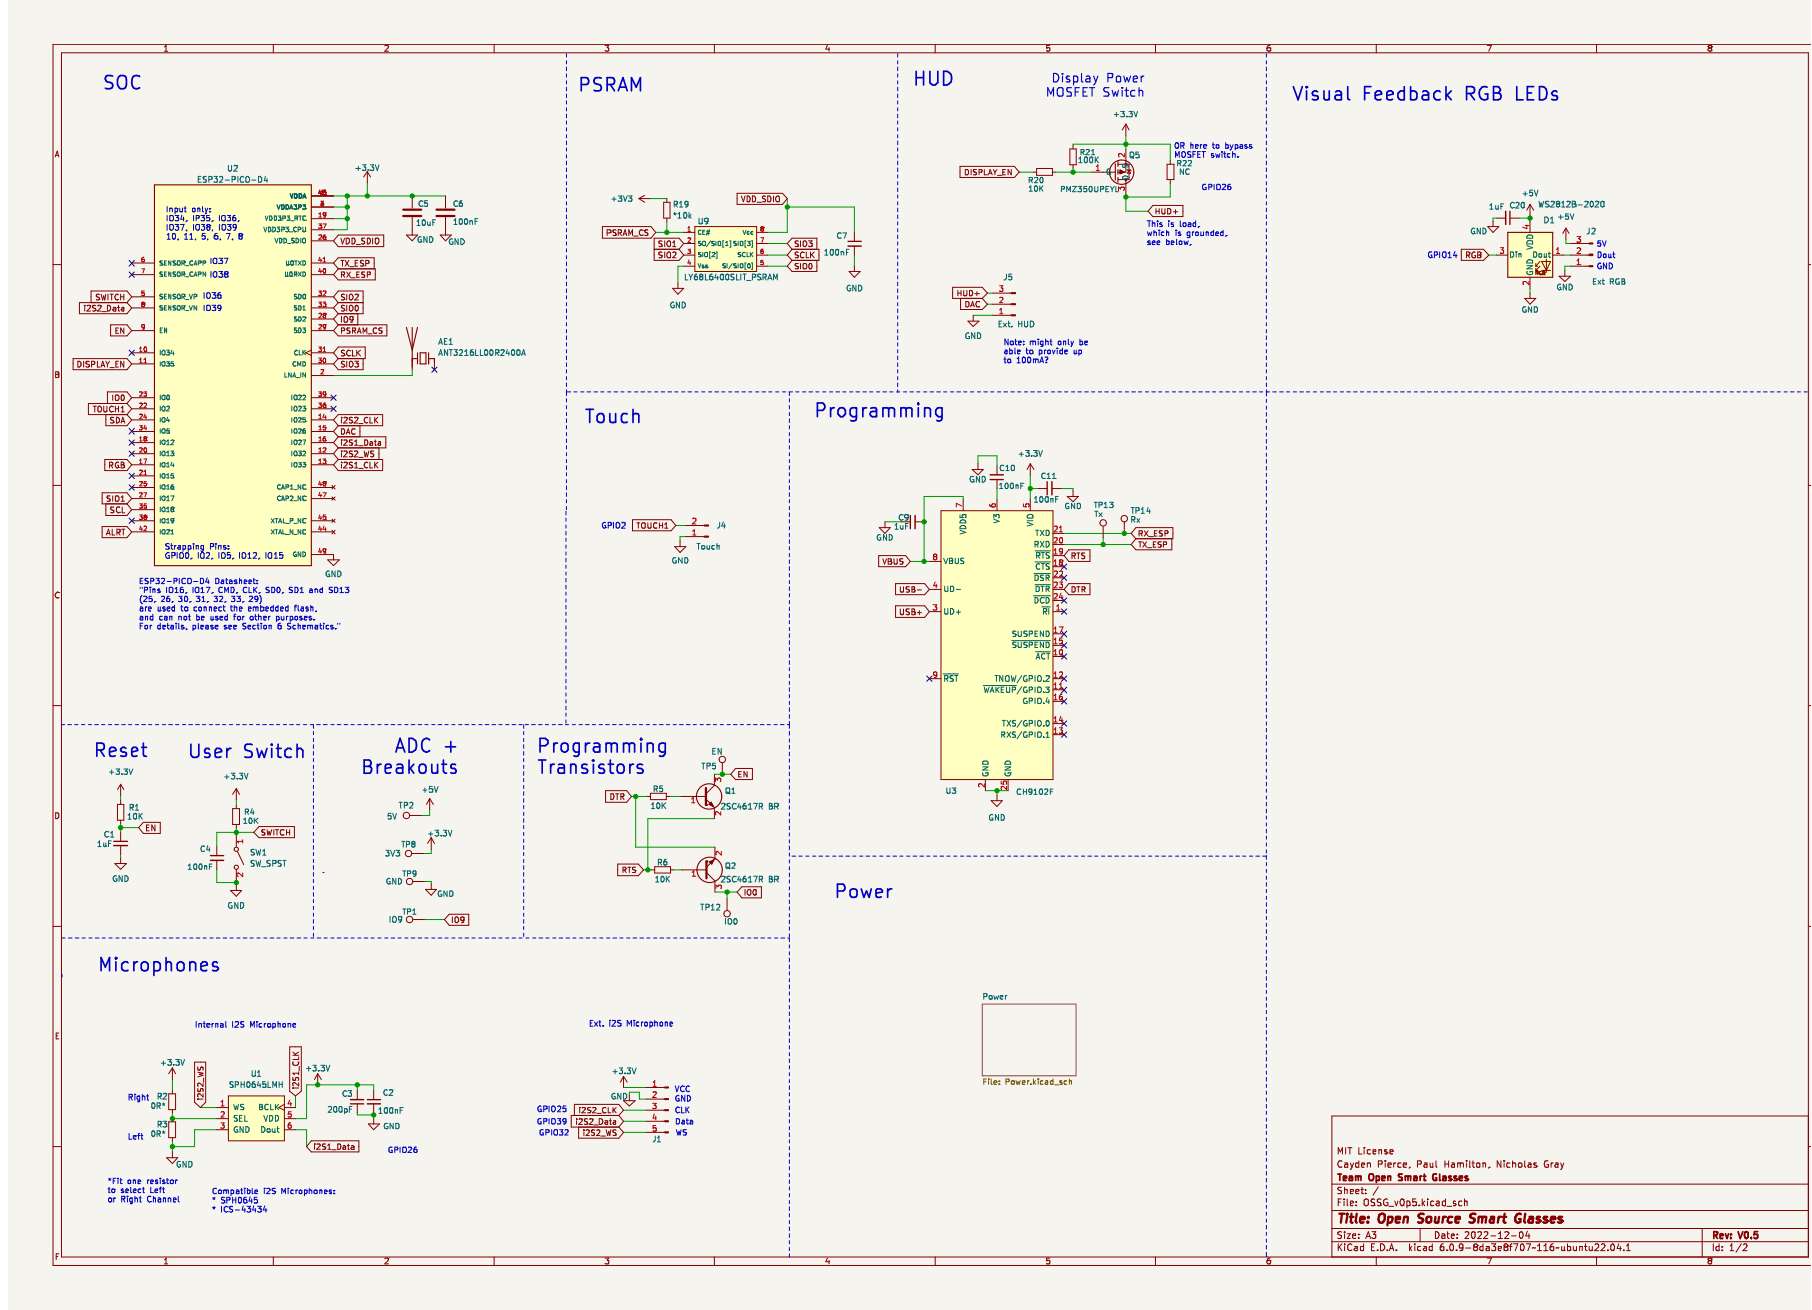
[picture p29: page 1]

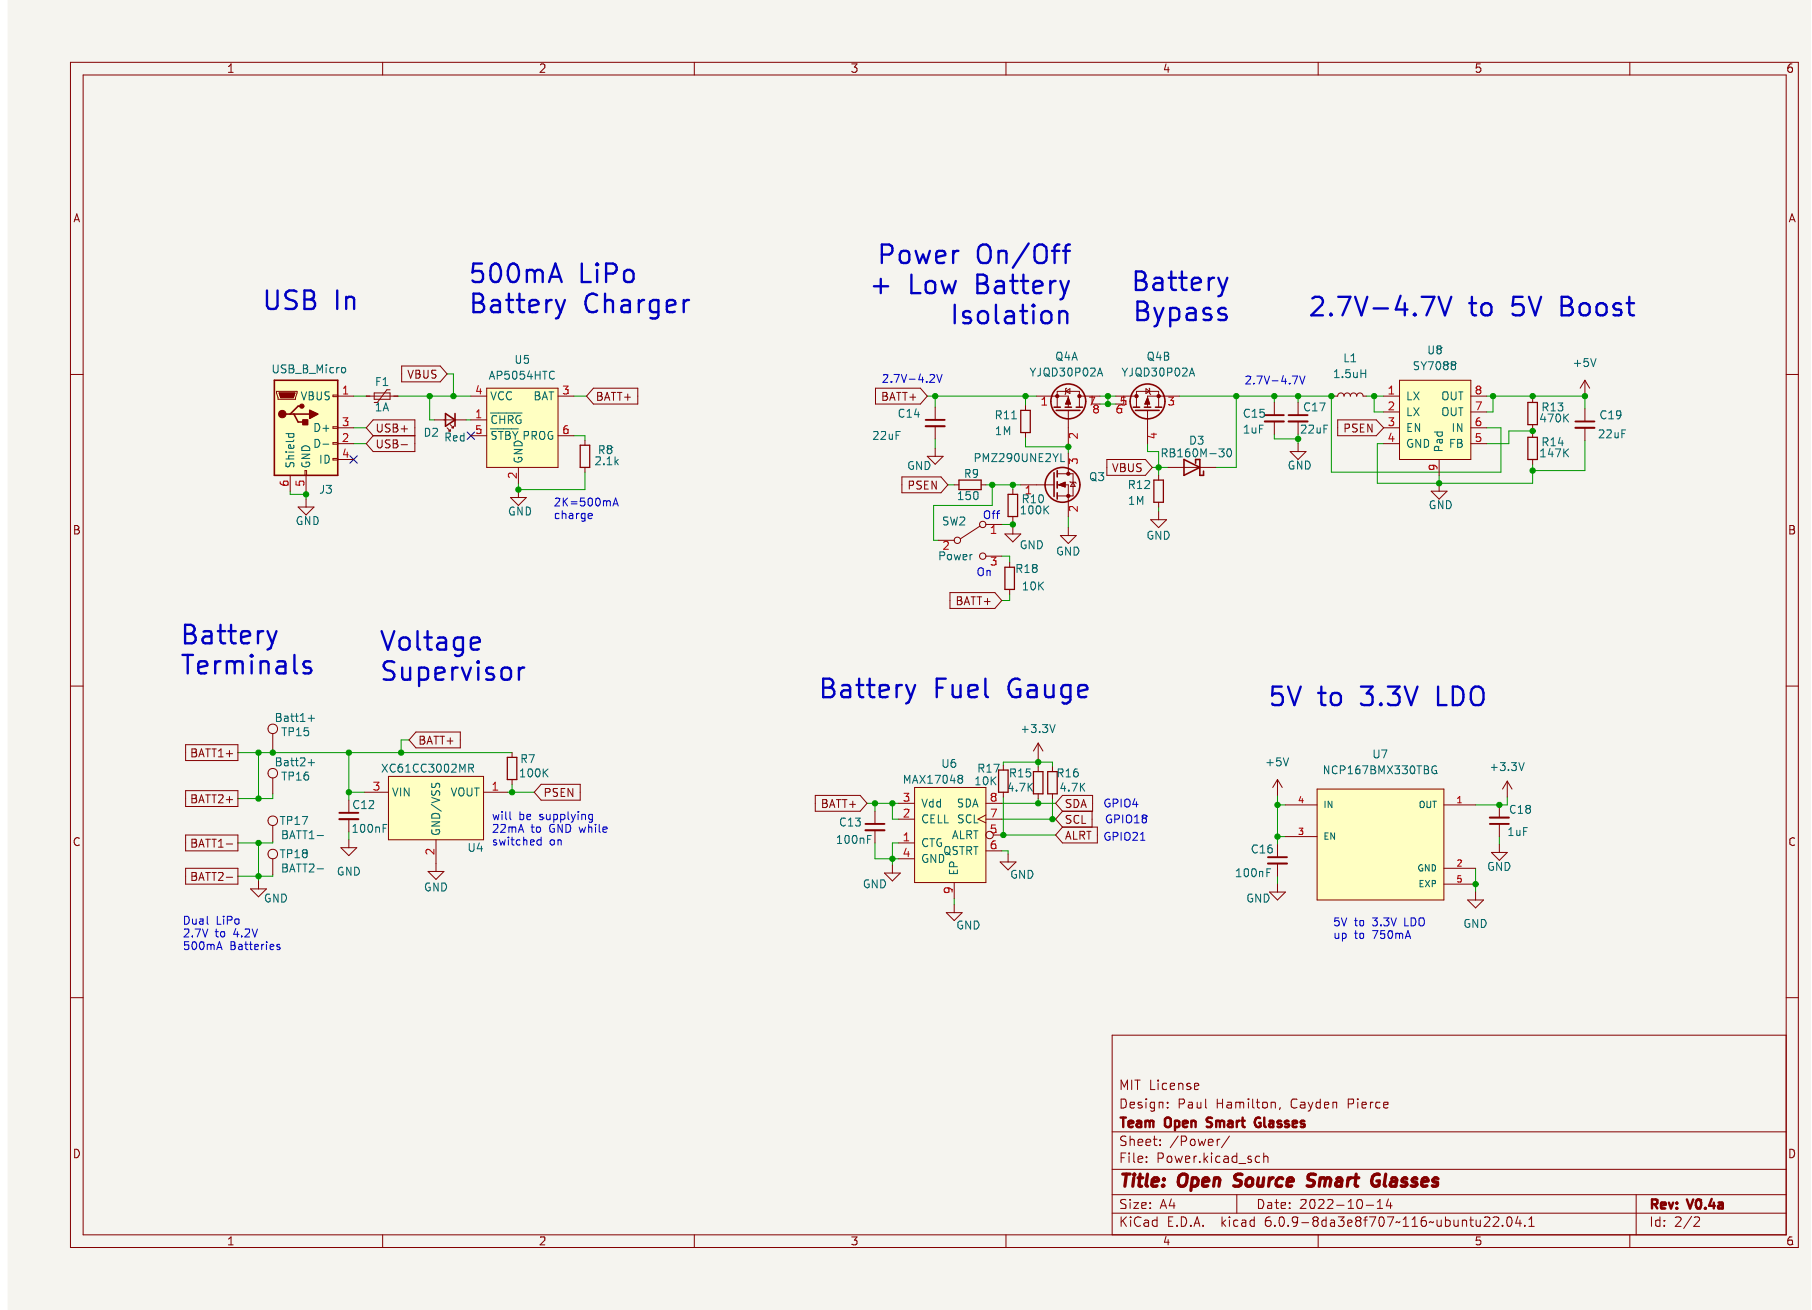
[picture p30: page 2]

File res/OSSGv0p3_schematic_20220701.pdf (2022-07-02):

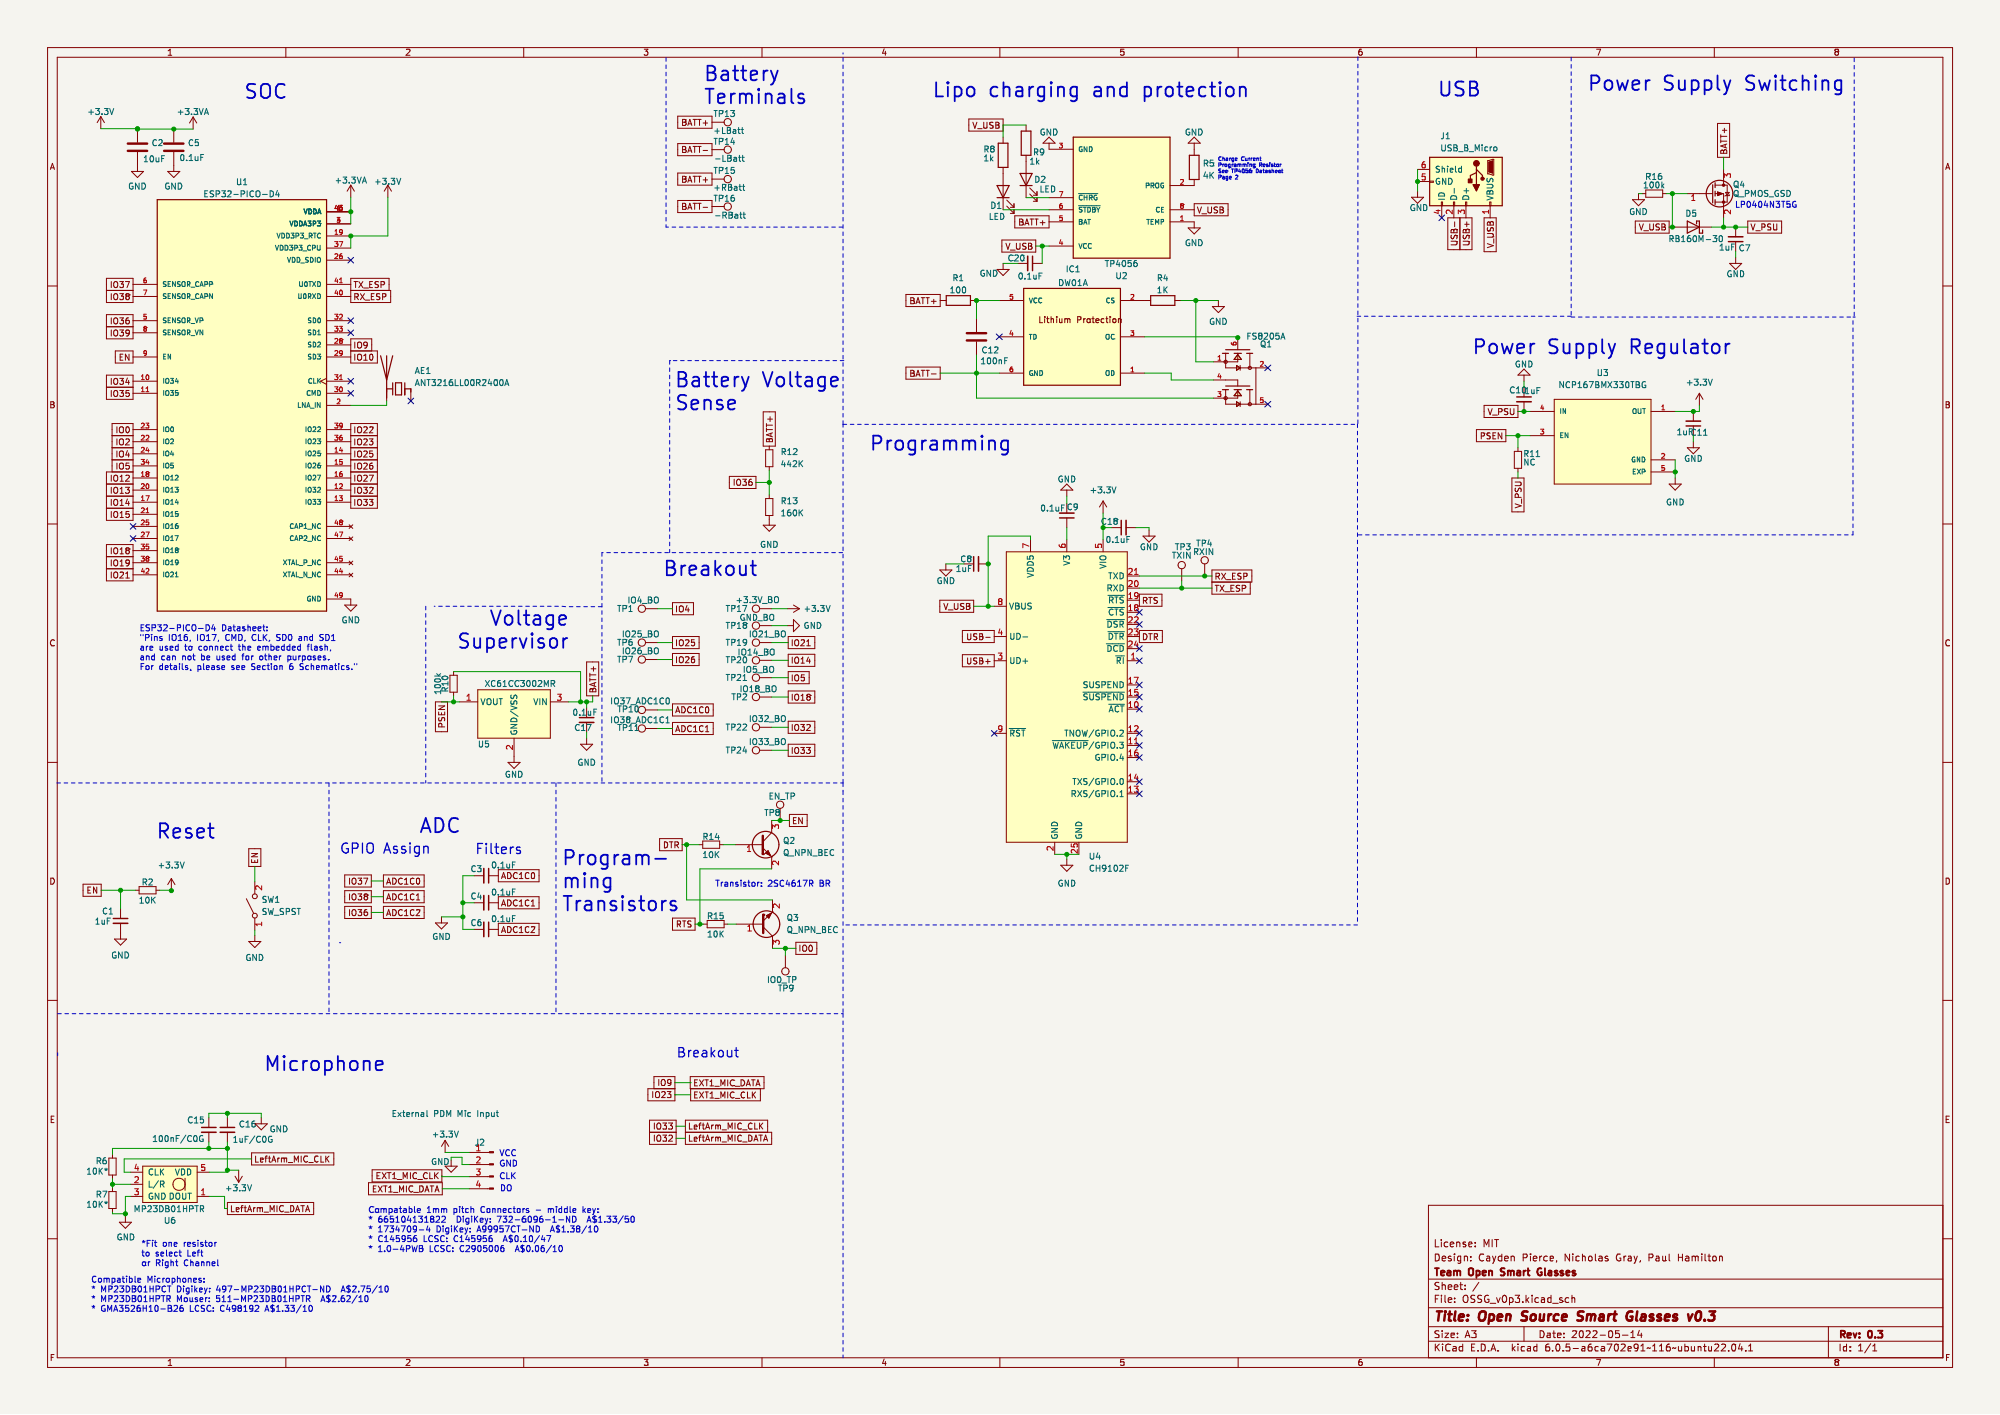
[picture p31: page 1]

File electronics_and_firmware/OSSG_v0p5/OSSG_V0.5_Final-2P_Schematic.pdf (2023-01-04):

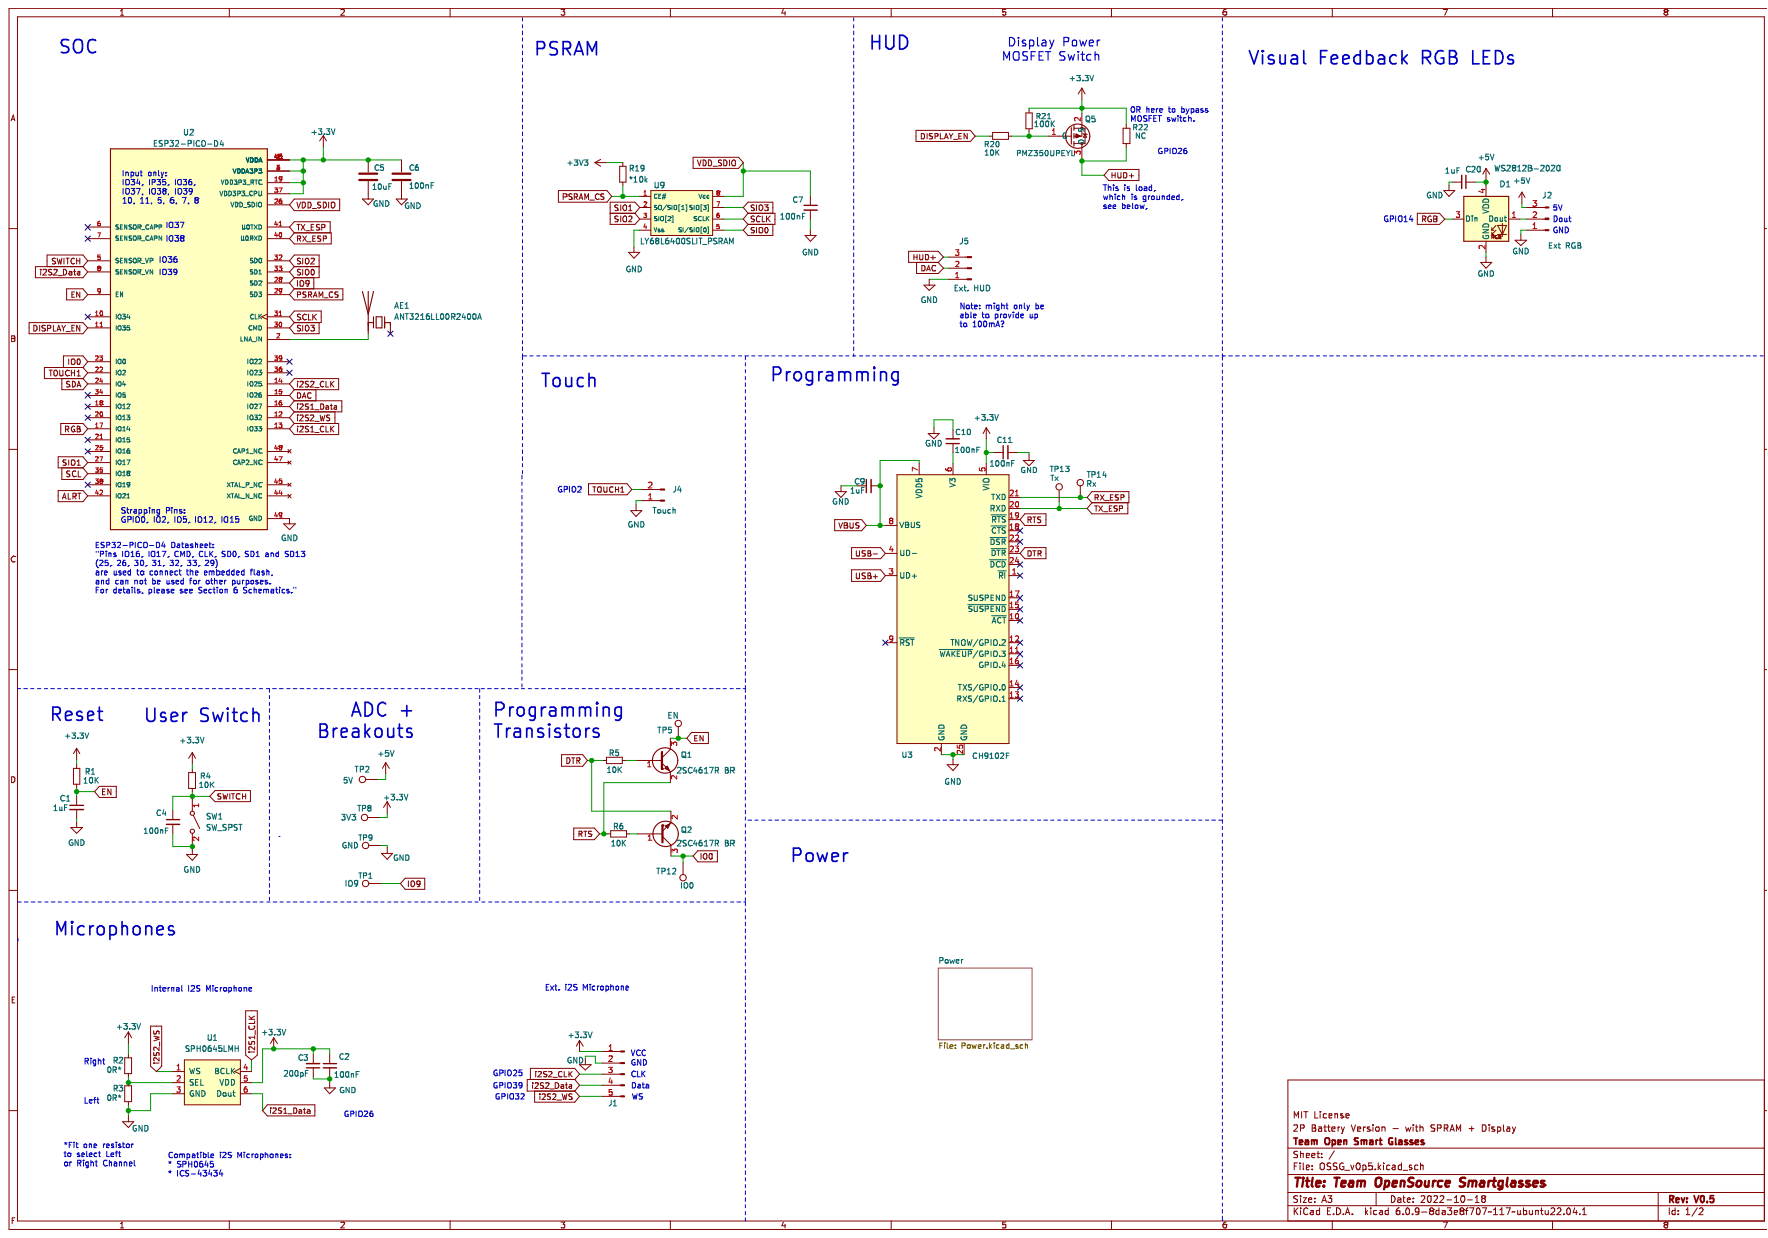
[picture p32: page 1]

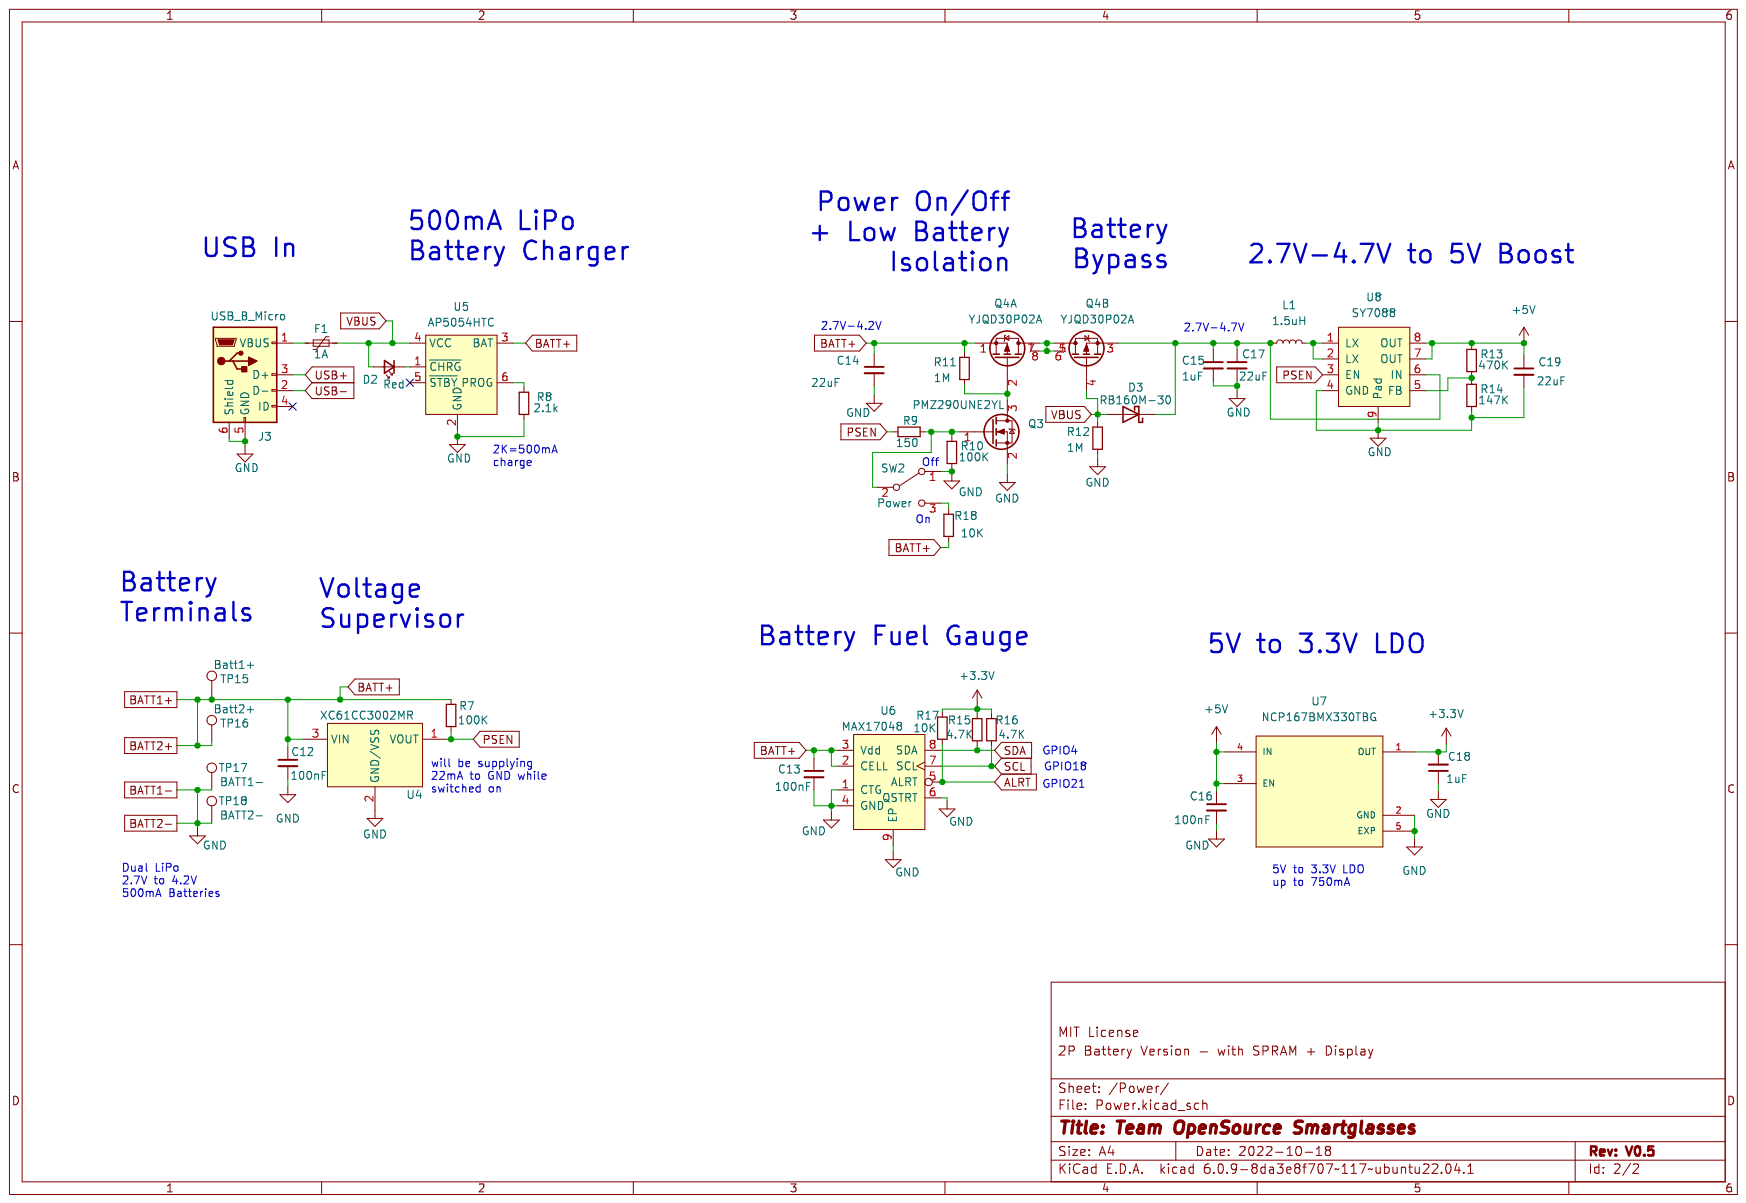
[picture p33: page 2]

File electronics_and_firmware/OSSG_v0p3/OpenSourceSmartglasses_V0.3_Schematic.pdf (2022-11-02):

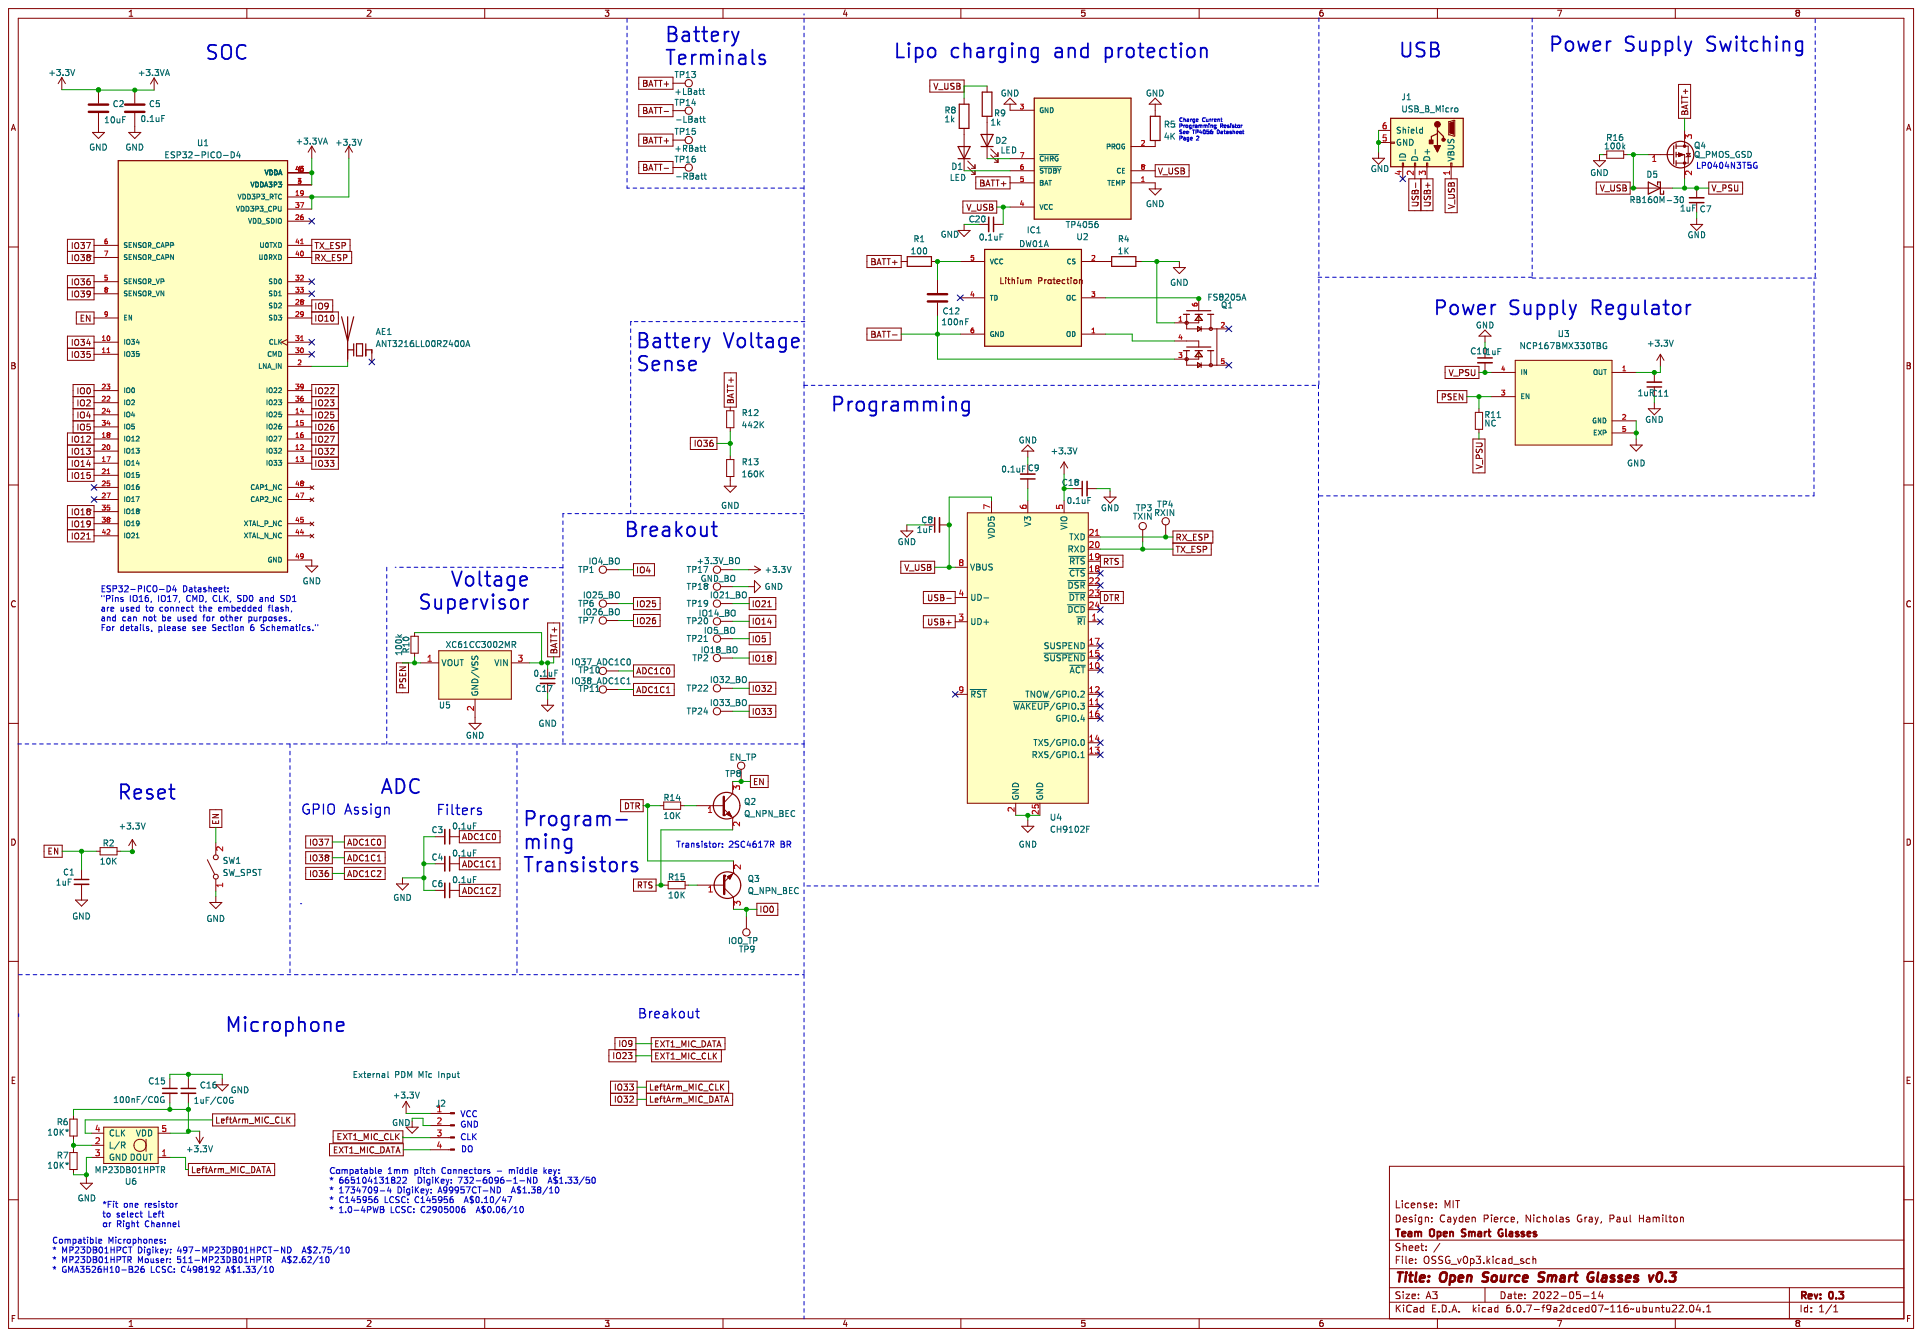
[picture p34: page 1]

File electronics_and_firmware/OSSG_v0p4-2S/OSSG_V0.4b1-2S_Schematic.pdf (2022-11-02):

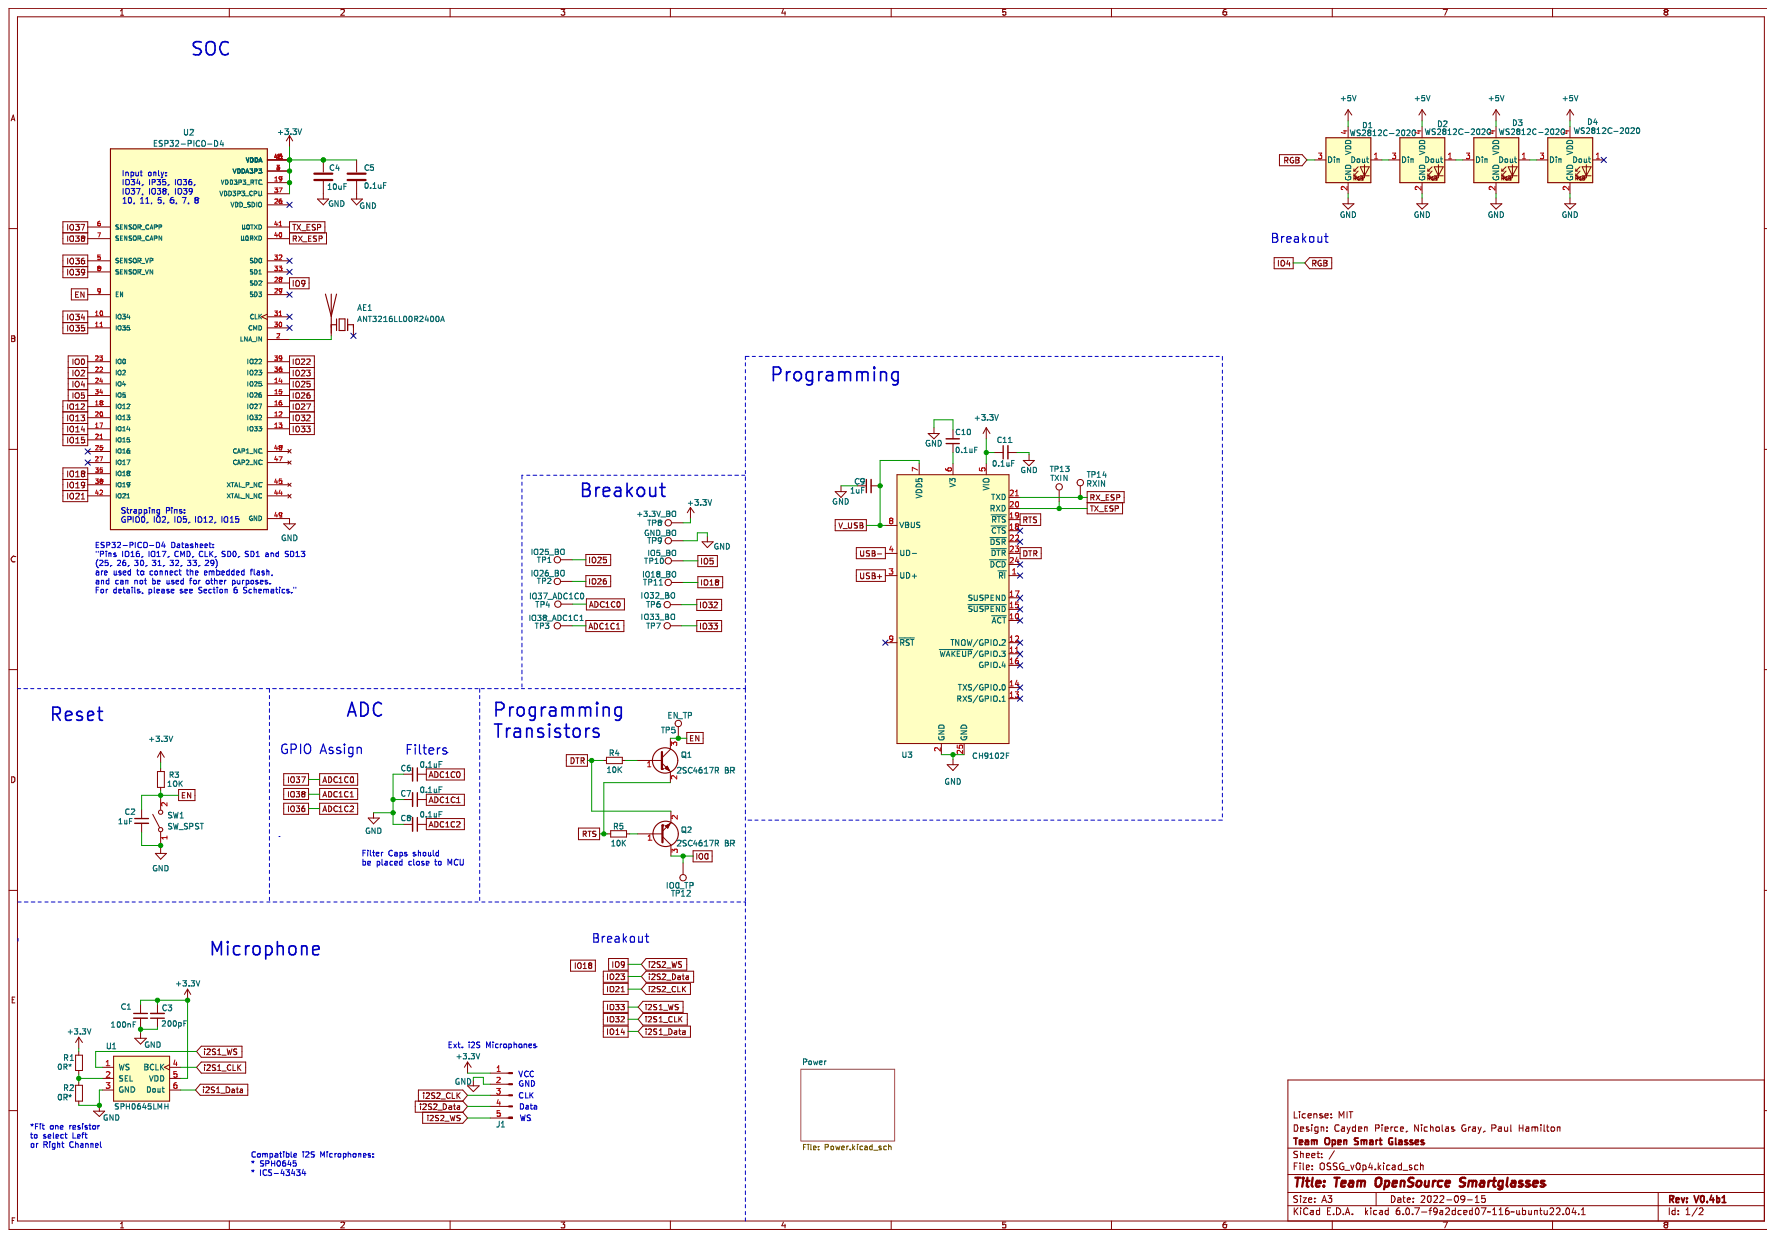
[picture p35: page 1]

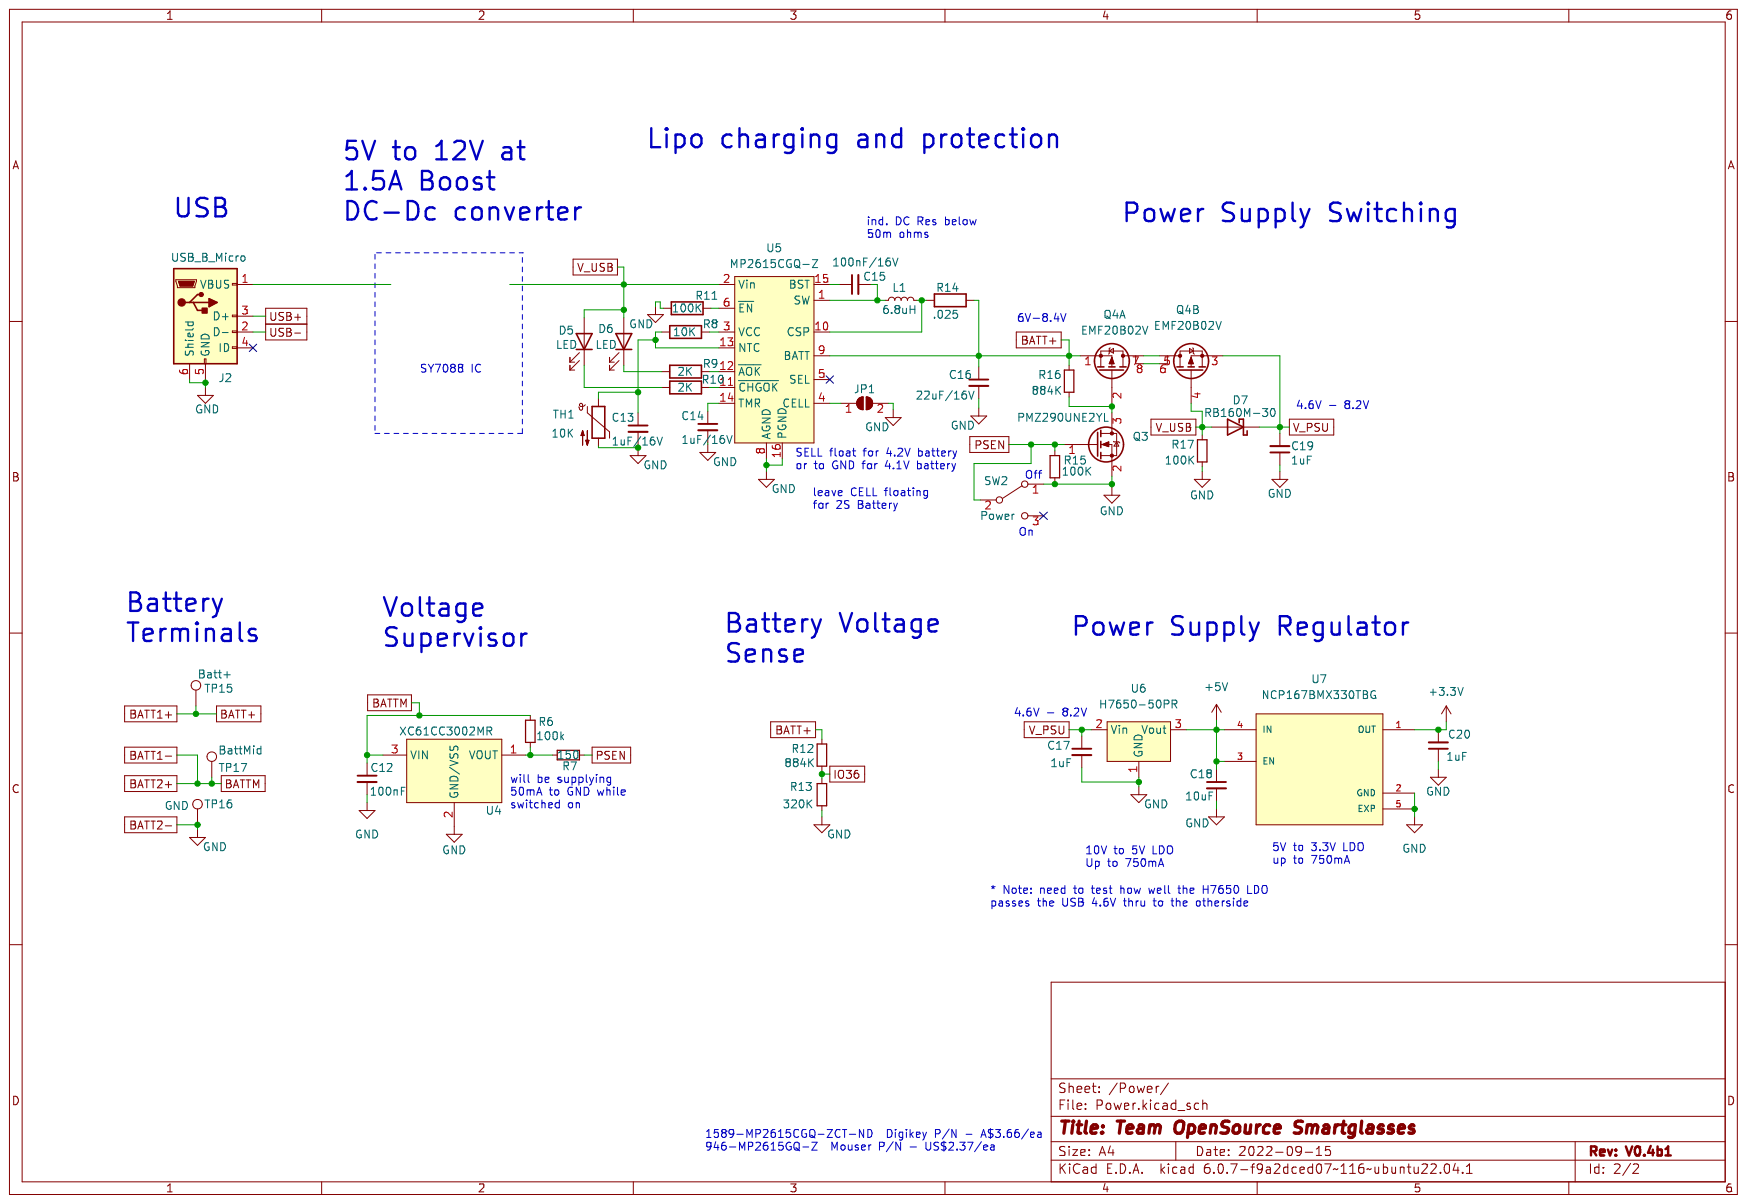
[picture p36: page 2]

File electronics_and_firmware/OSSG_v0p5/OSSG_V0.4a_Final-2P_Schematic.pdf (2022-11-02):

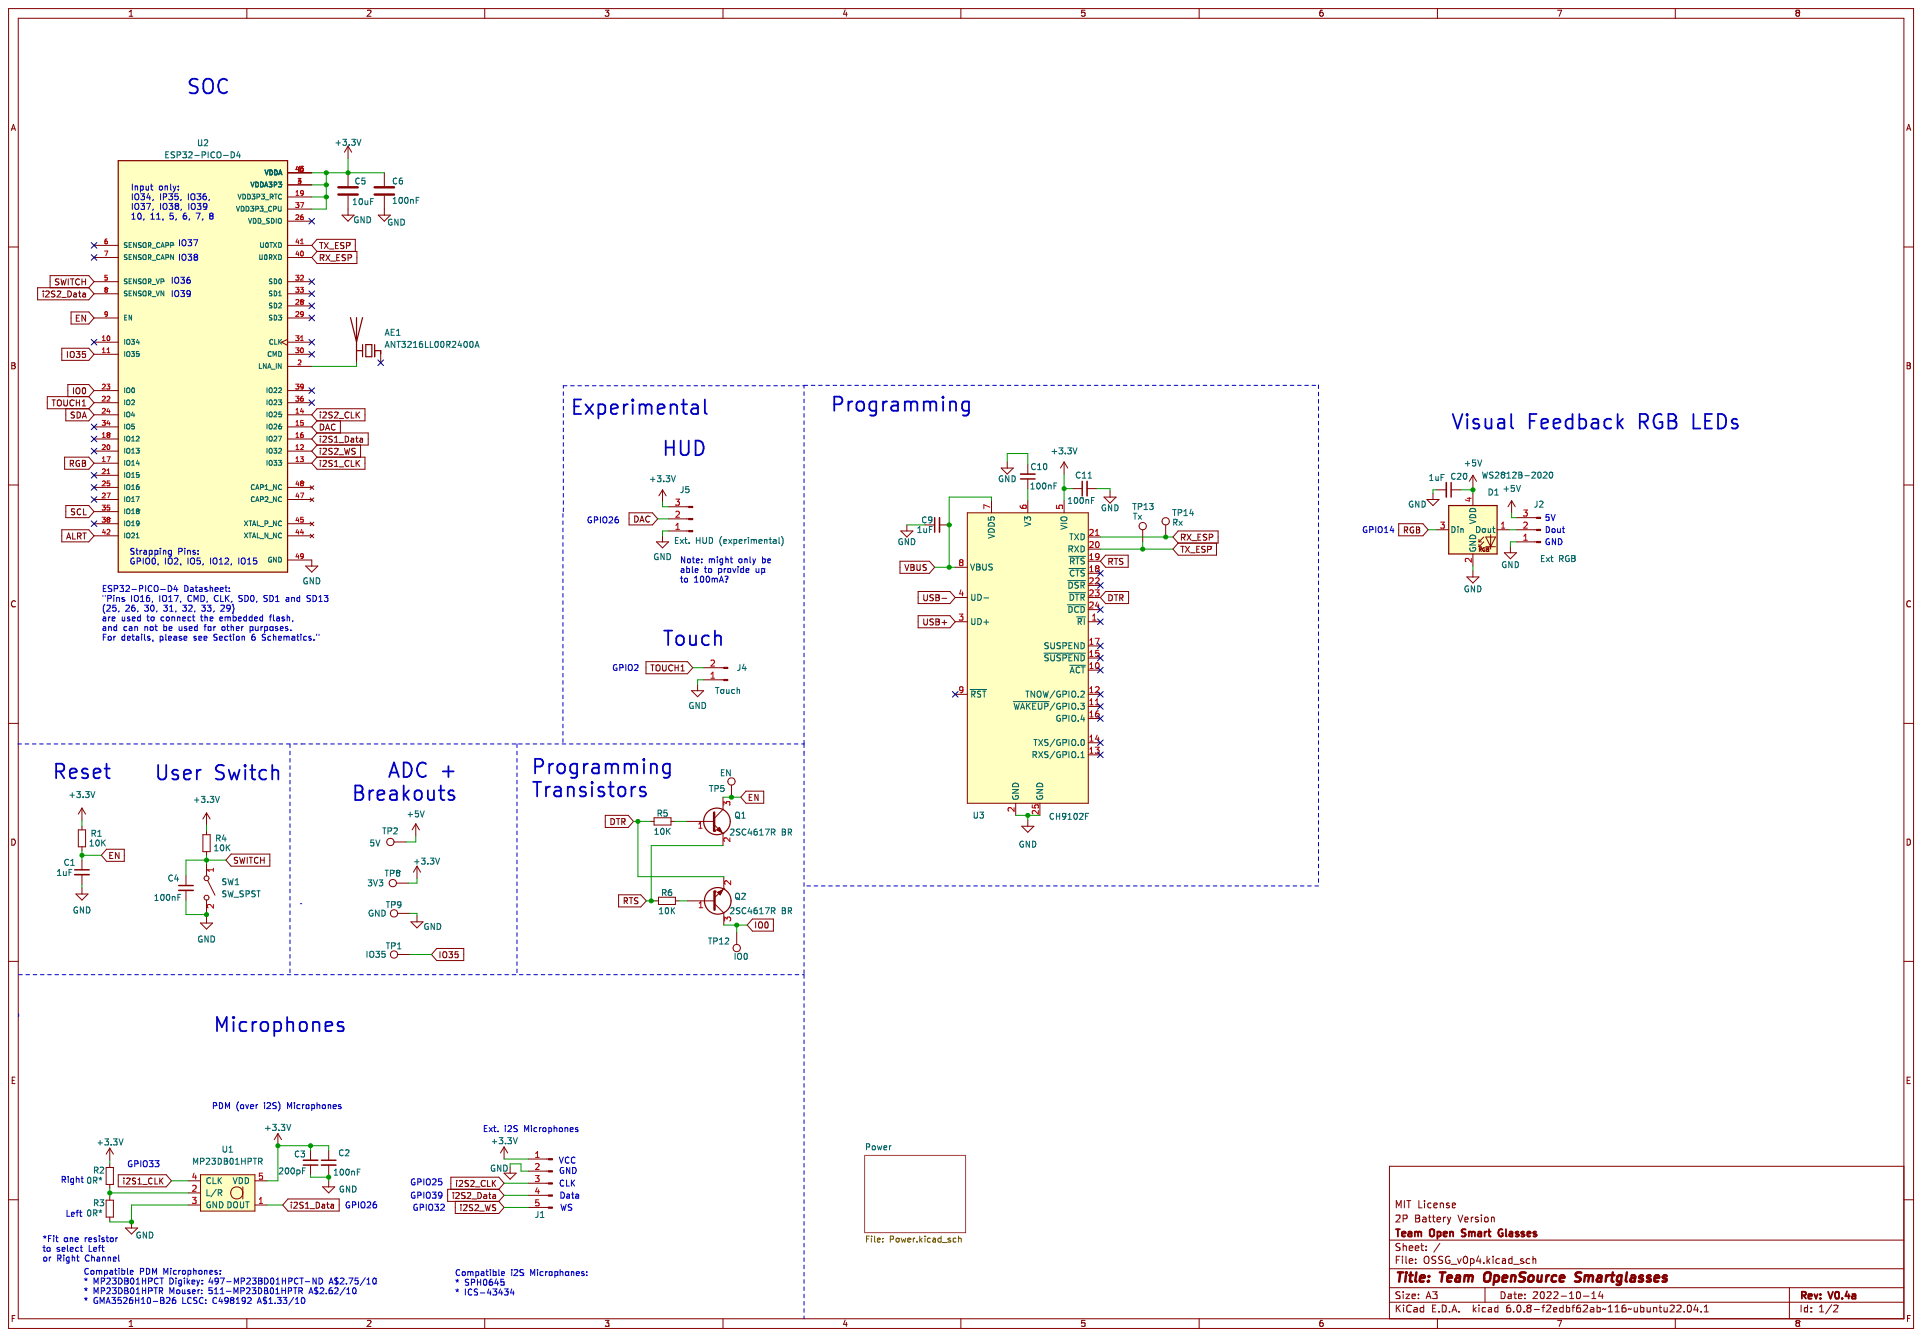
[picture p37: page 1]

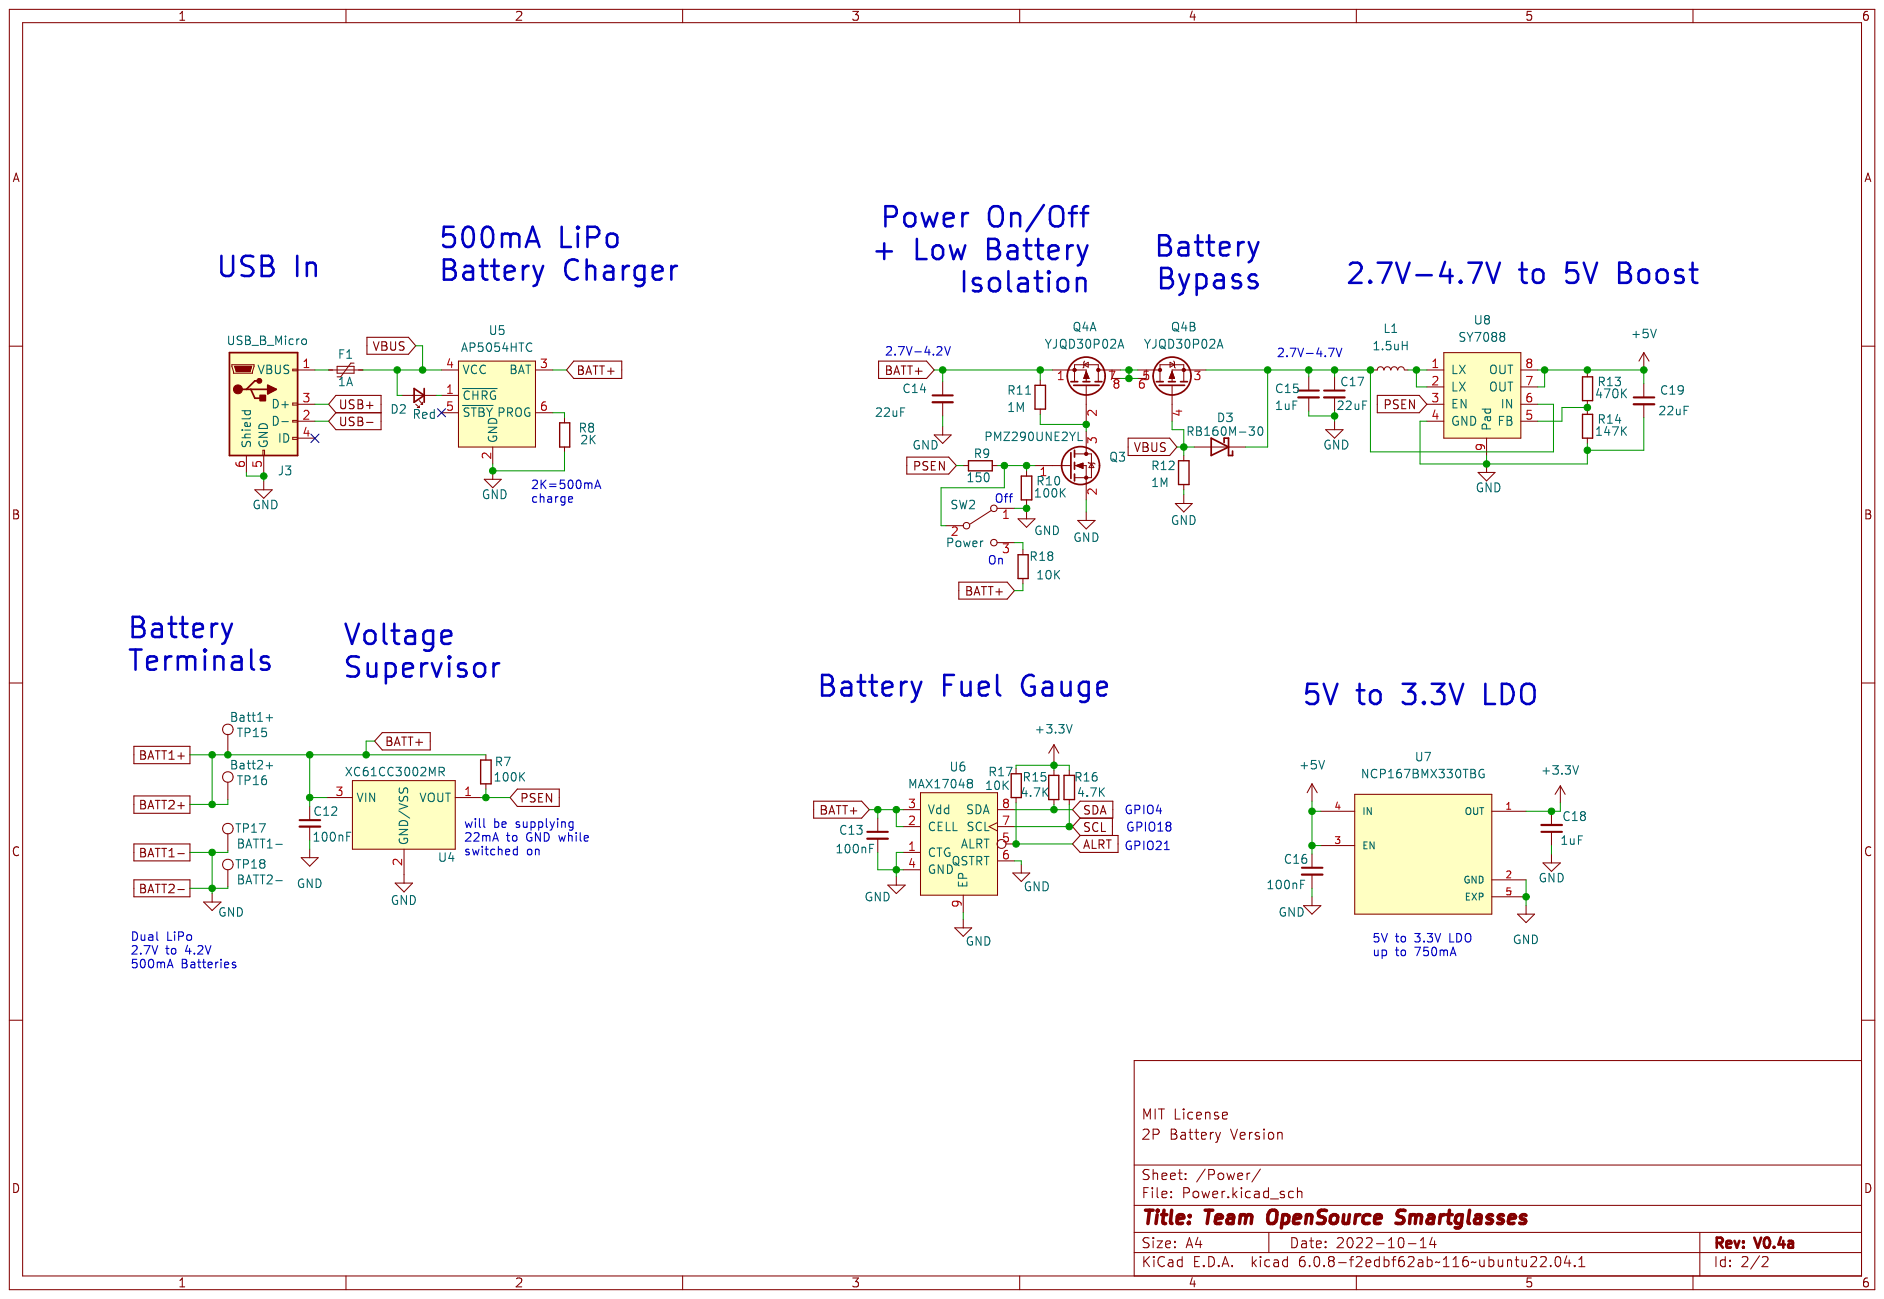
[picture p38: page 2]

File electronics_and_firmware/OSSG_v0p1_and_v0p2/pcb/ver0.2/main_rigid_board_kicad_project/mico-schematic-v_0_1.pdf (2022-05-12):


1 IOVDD 10 GPIO8 11 GPIO9 12 GPIO10 13 GPIO11 14 GPIO12 15 GPIO13 16 GPIO14 17 GPIO15 18 TESTEN 19 GPIO0 2 XIN 20 XOUT 21 IOVDD 22 DVDD 23 SWCLK 24 SWD 25 RUN 26 GPIO16 27 GPIO17 28 GPIO18 29 GPIO1 3 GPIO19 30 GPIO20 31 GPIO21 32 IOVDD 33 GPIO22 34 GPIO23 35 GPIO24 36 GPIO25 37 GPIO26/ADC0 38 GPIO27/ADC1 39 GPIO2 4 GPIO28/ADC2 40 GPIO29/ADC3 41 IOVDD 42 ADC_AVDD 43 VREG_VIN 44 VREG_VOUT 45 USB_DM 46 USB_DP 47 USB_VDD 48 IOVDD 49 GPIO3 5 DVDD 50 QSPI_SD3 51 QSPI_SCLK 52 QSPI_SD0 53 QSPI_SD2 54 QSPI_SD1 55 QSPI_CSN 56 GND 57 GPIO4 6 GPIO5 7 GPIO6 8 GPIO7 9 U4 RP2040 DOUT 1

File: mico.sch Sheet: / Electronut Labs Designed by Mahesh Venkitachalam

Id: 1/1 Title: mico.priv



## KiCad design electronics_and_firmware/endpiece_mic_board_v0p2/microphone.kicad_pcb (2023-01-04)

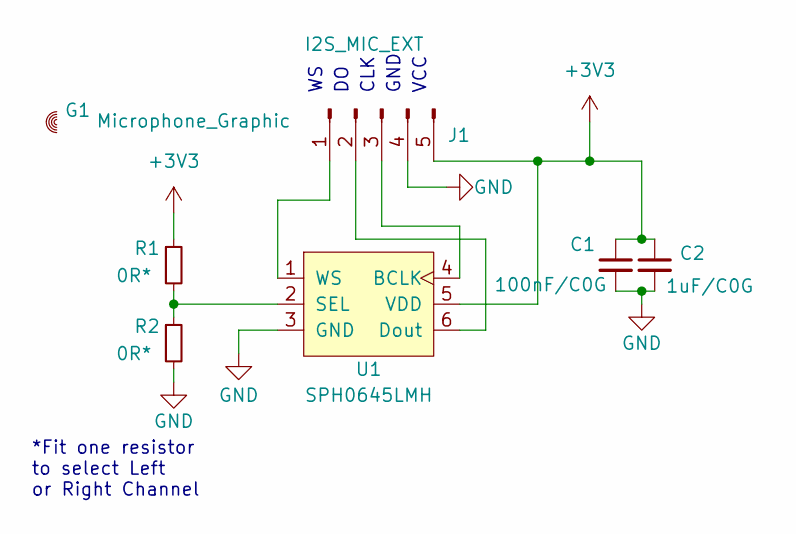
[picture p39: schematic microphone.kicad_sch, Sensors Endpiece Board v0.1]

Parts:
C1: 100nF/C0G; C_0402_1005Metric
C2: 1uF/C0G; C_0402_1005Metric
G1: Microphone_Graphic; Microhone_Graphic_sml
J1: I2S_MIC_EXT; Solder-5P-Connector
R1, R2: 0R*; R_0402_1005Metric
U1: SPH0645LMH; MIC_SPH0645LM4H-B

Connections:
+3V3: C1.1, C2.1, J1.5, R1.1, U1.5 (VDD)
GND: C1.2, C2.2, J1.4, R2.2, U1.3 (GND)
unnamed: J1.1, U1.1 (WS)
unnamed: J1.2, U1.6 (Dout)
unnamed: J1.3, U1.4 (BCLK)
unnamed: R1.2, R2.1, U1.2 (SEL)

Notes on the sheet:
CLK
*Fit one resistor to select Left or Right Channel
GND
VCC

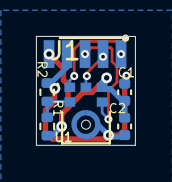
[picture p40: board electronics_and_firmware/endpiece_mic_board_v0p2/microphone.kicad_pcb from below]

Board: 2 copper layers, 5.5 x 6.0 mm, 7 parts (6 on the bottom side), 6 nets.

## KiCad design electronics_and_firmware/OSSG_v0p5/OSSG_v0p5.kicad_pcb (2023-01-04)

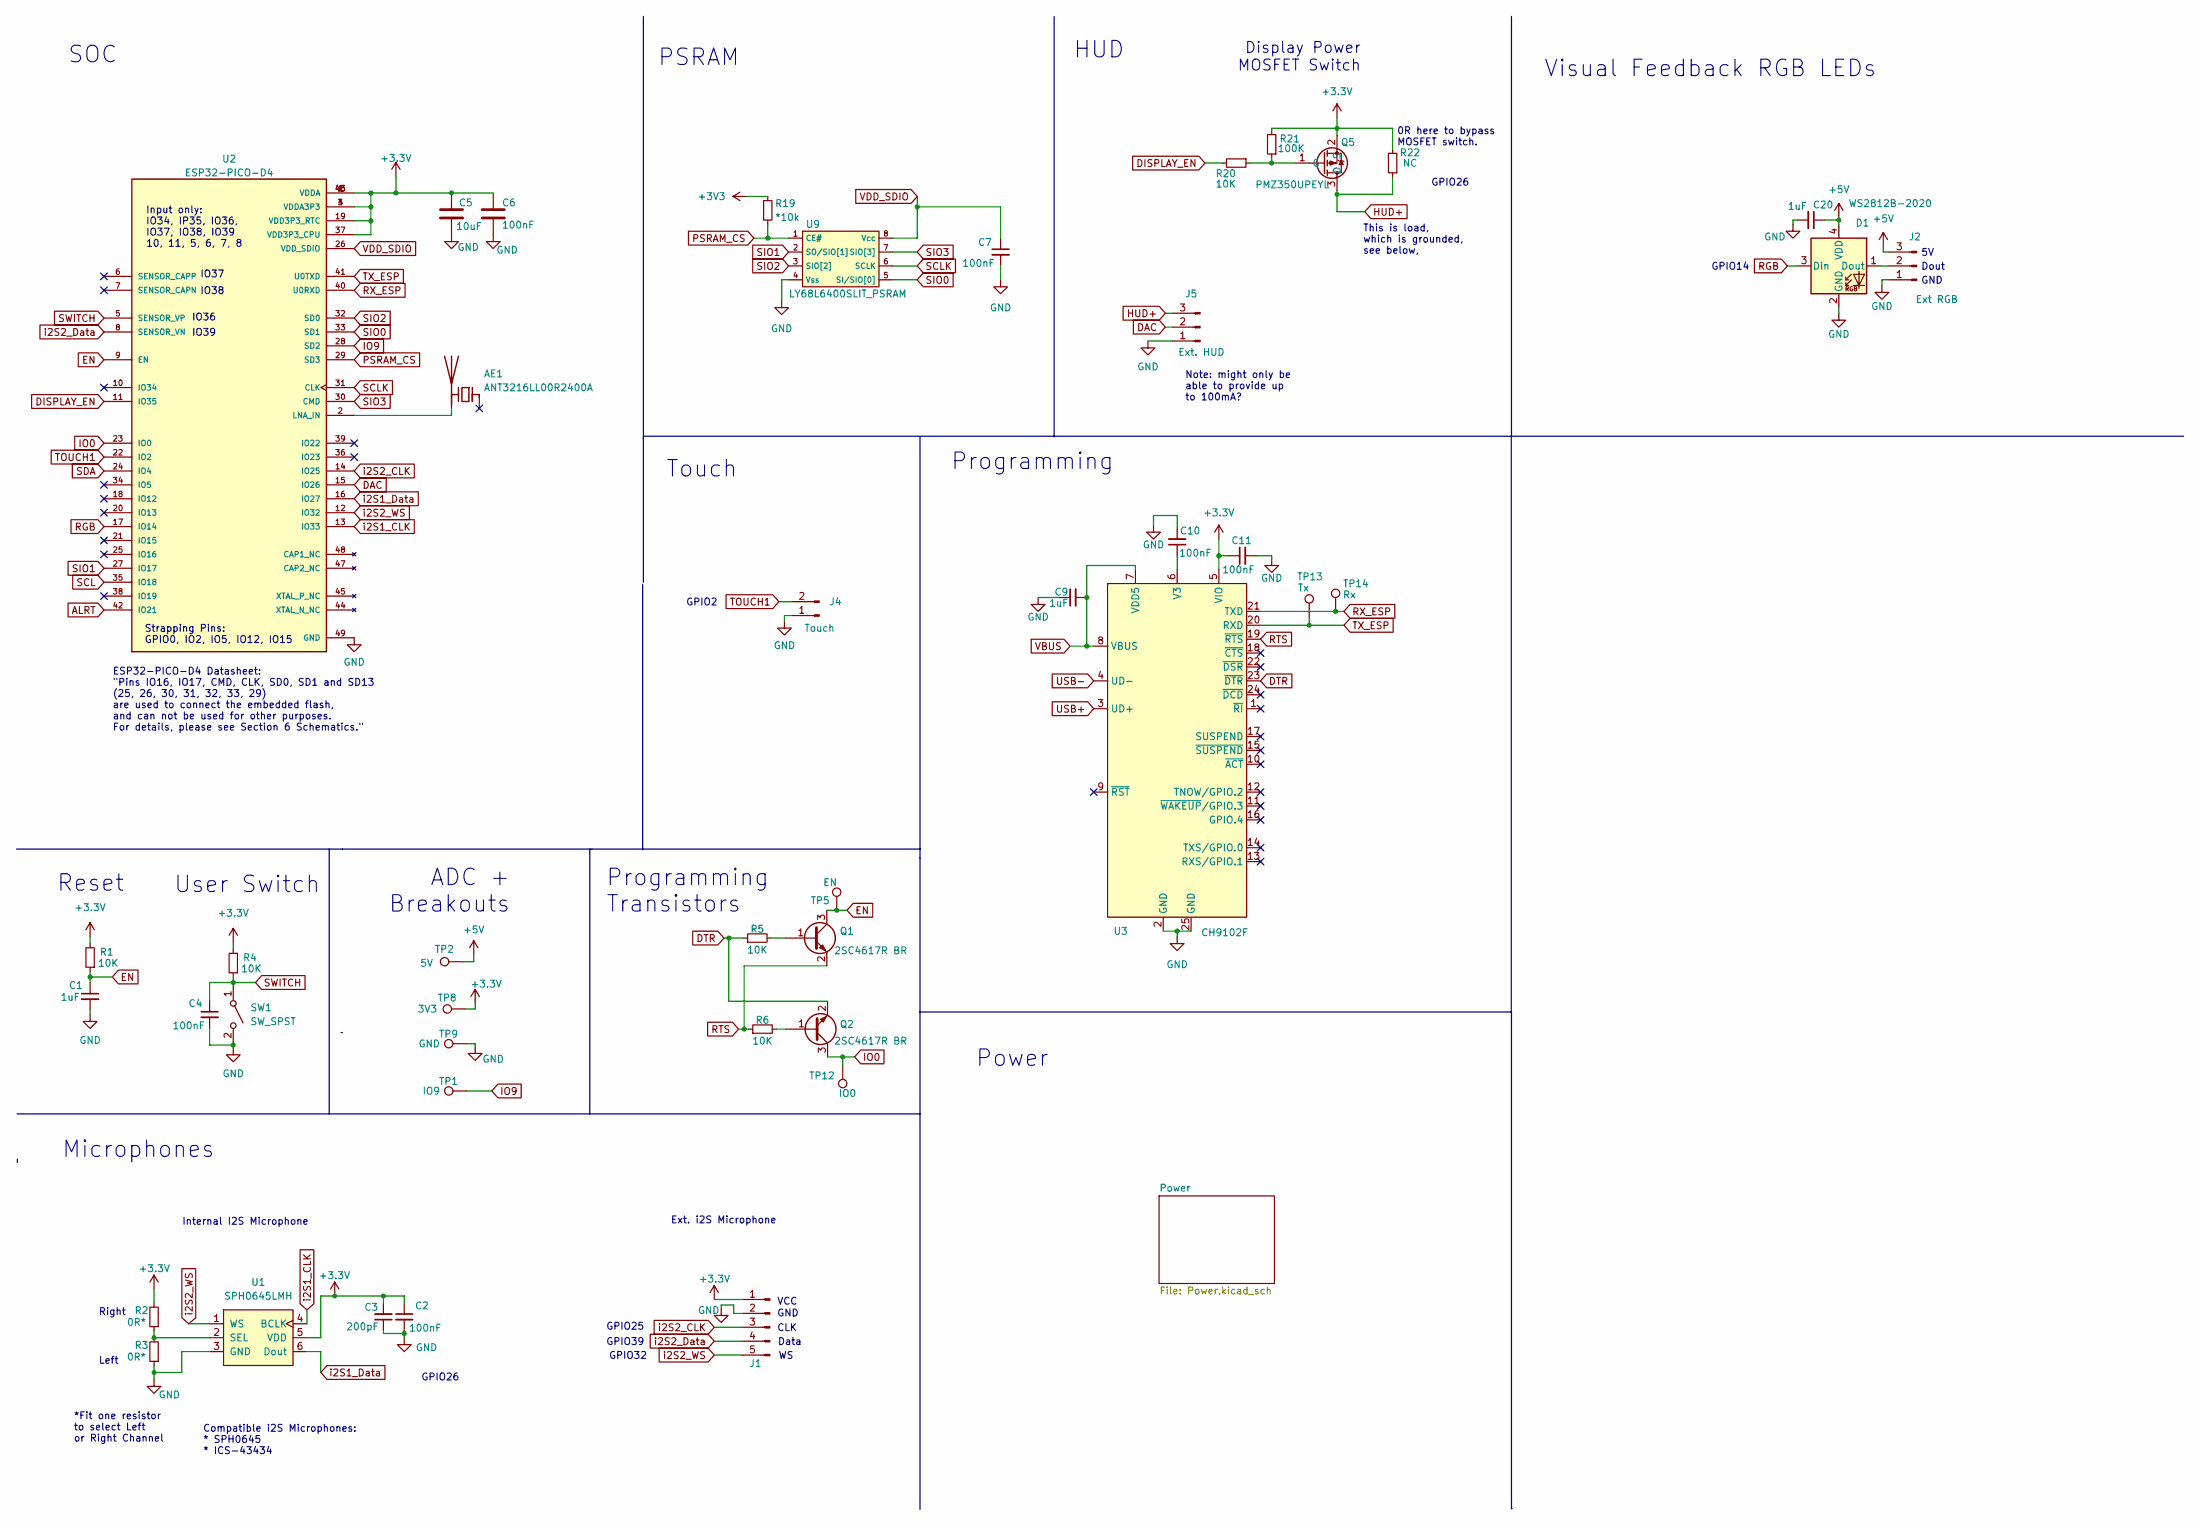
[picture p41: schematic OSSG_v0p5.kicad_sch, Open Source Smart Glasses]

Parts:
AE1: ANT3216LL00R2400A; MPN_LCSC C293767
C1, C9, C20: 1uF; C_0402_1005Metric; MPN 490-GRT155C80J105KE01JCT-ND
C2, C7: 100nF; C_0402_1005Metric; MPN_LCSC C41851
C3: 200pF; C_0402_1005Metric; MPN_LCSC C41851
C4: 100nF; C_0402_1005Metric; MPN 490-GRT155C80J105KE01JCT-ND
C5: 10uF; C_0402_1005Metric; MPN 1276-1450-1-ND
C6: 100nF; C_0402_1005Metric; MPN 1276-1043-1-ND
C10, C11: 100nF; C_0402_1005Metric; MPN_LCSC C258109
D1: WS2812B-2020; LED_WS2812C-2020; MPN_LCSC C965555
J1: Conn_01x05_Male; Solder-5P-Connector
J2: Ext RGB; Solder-3P-Connector
J4: Touch; Solder-2P-Connector
J5: Ext. HUD; Solder-3P-Connector
Q1, Q2: 2SC4617R BR; SOT-523; MPN_LCSC C2836080
Q5: PMZ350UPEYL; DFN100X60X40-3N; MPN_LCSC C478207
R1, R4, R5, R6: 10K; R_0402_1005Metric; MPN RMCF0402JT10K0CT-ND
R2, R3: 0R*; R_0402_1005Metric; MPN_LCSC C2906877
R19: *10k; R_0402_1005Metric; MPN_LCSC C2906885
R20: 10K; R_0402_1005Metric; MPN_LCSC 1
R21: 100K; R_0402_1005Metric; MPN_LCSC 1
R22: NC; R_0402_1005Metric; MPN_LCSC C2906877
SW1: SW_SPST; SMD_Switch_Panasonic_EVQPUL_EVQPUC_6.3x6.7; MPN UK-B0249-SP25Y
TP1: IO9; Breakout_pads_small
TP2: 5V; Breakout_pads_small
TP5: EN; Breakout_pads_very_small
TP8: 3V3; Breakout_pads_small
TP9: GND; Breakout_pads_small
TP12: IO0; Breakout_pads_very_small
TP13: Tx; Breakout_pads_very_small
TP14: Rx; Breakout_pads_very_small
U1: SPH0645LMH; MIC_SPH0645LM4H-B
U2: ESP32-PICO-D4; ESP32_PICO_D4_PQFN50P700X700X104-49N; PARTREV v1.9
U3: CH9102F; QFN-24-1EP_4x4mm_P0.5mm_EP2.6x2.6mm; MPN_LCSC C2858418
U9: LY68L6400SLIT_PSRAM; SOP-8_3.9x4.9mm_P1.27mm; MPN_LCSC C261881

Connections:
+5V: C20.1, D1.4 (VDD), J2.3, TP2.1; also elsewhere on the board
ALRT: U2.42 (IO21); also elsewhere on the board
BATT1-: C1.2, C2.2, C3.1, C4.2, C5.2, C6.2, C7.2, C9.1, C10.2, C11.2, C20.2, D1.2 (GND), J1.2, J2.1, J4.1, J5.1, R3.1, SW1.2 (B), TP9.1, U1.3 (GND), U2.49 (GND), U3.2 (GND), U3.25 (GND), U9.4 (Vss); also elsewhere on the board
DAC: J5.2, U2.15 (IO26)
DISPLAY_EN: R20.2, U2.11 (IO35)
DTR: Q2.2 (E), R5.1, U3.23 (~DTR)
EN: C1.1, Q1.3 (C), R1.1, TP5.1, U2.9 (EN)
HUD+: J5.3, Q5.3 (D), R22.1
IO0: Q2.3 (C), TP12.1, U2.23 (IO0)
IO9: TP1.1, U2.28 (SD2)
unnamed: AE1.2 (PCB_Trace), U2.2 (LNA_IN)
unnamed: C10.1, U3.6 (V3)
unnamed: D1.1 (Dout), J2.2
unnamed: Q1.1 (B), R5.2
unnamed: Q2.1 (B), R6.2
unnamed: Q5.1 (G), R20.1, R21.1
unnamed: R2.1, R3.2, U1.2 (SEL)
PSRAM_CS: R19.2, U2.29 (SD3), U9.1 (CE#)
RGB: D1.3 (Din), U2.17 (IO14)
RTS: Q1.2 (E), R6.1, U3.19 (~RTS)
RX_ESP: TP14.1, U2.40 (U0RXD), U3.21 (TXD)
SCL: U2.35 (IO18); also elsewhere on the board
SCLK: U2.31 (CLK), U9.6 (SCLK)
SDA: U2.24 (IO4); also elsewhere on the board
SIO0: U2.33 (SD1), U9.5 (SI/SIO[0])
SIO1: U2.27 (IO17), U9.2 (SO/SIO[1])
SIO2: U2.32 (SD0), U9.3 (SIO[2])
SIO3: U2.30 (CMD), U9.7 (SIO[3])
SWITCH: C4.1, R4.1, SW1.1 (A), U2.5 (SENSOR_VP)
TOUCH1: J4.2, U2.22 (IO2)
TX_ESP: TP13.1, U2.41 (U0TXD), U3.20 (RXD)
USB+: U3.3 (UD+); also elsewhere on the board
USB-: U3.4 (UD-); also elsewhere on the board
VBUS: C9.2, U3.7 (VDD5), U3.8 (VBUS); also elsewhere on the board
VDD_SDIO: C7.1, U2.26 (VDD_SDIO), U9.8 (Vcc)
i2S1_CLK: U1.4 (BCLK), U2.13 (IO33)
i2S1_Data: U1.6 (Dout), U2.16 (IO27)
i2S2_CLK: J1.3, U2.14 (IO25)
i2S2_Data: J1.4, U2.8 (SENSOR_VN)
i2S2_WS: J1.5, U1.1 (WS), U2.12 (IO32)

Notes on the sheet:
Ext. i2S Microphone
GPIO32
GPIO25
HUD
Right
SOC
Programming
GND
GPIO39
Reset
Input only: IO34, IP35, IO36, IO37, IO38, IO39 10, 11, 5, 6, 7, 8
Visual Feedback RGB LEDs
0R here to bypass MOSFET switch.
Touch
*Fit one resistor to select Left or Right Channel
ESP32-PICO-D4 Datasheet: "Pins IO16, IO17, CMD, CLK, SD0, SD1 and SD13 (25, 26, 30, 31, 32, 33, 29) are used to connect the embedded flash, and can not be used for other purposes. For details, please see Section 6 Schematics."
IO36
GPIO2
Left
Note: might only be able to provide up to 100mA?
Microphones
User Switch
ADC + Breakouts
This is load, which is grounded, see below,
Display Power MOSFET Switch
GPIO26
Strapping Pins: GPIO0, IO2, IO5, IO12, IO15
PSRAM
CLK
Power
Internal I2S Microphone
Data
Compatible i2S Microphones: * SPH0645 * ICS-43434
GPIO14
VCC
IO39
IO38
Programming Transistors
IO37
Dout

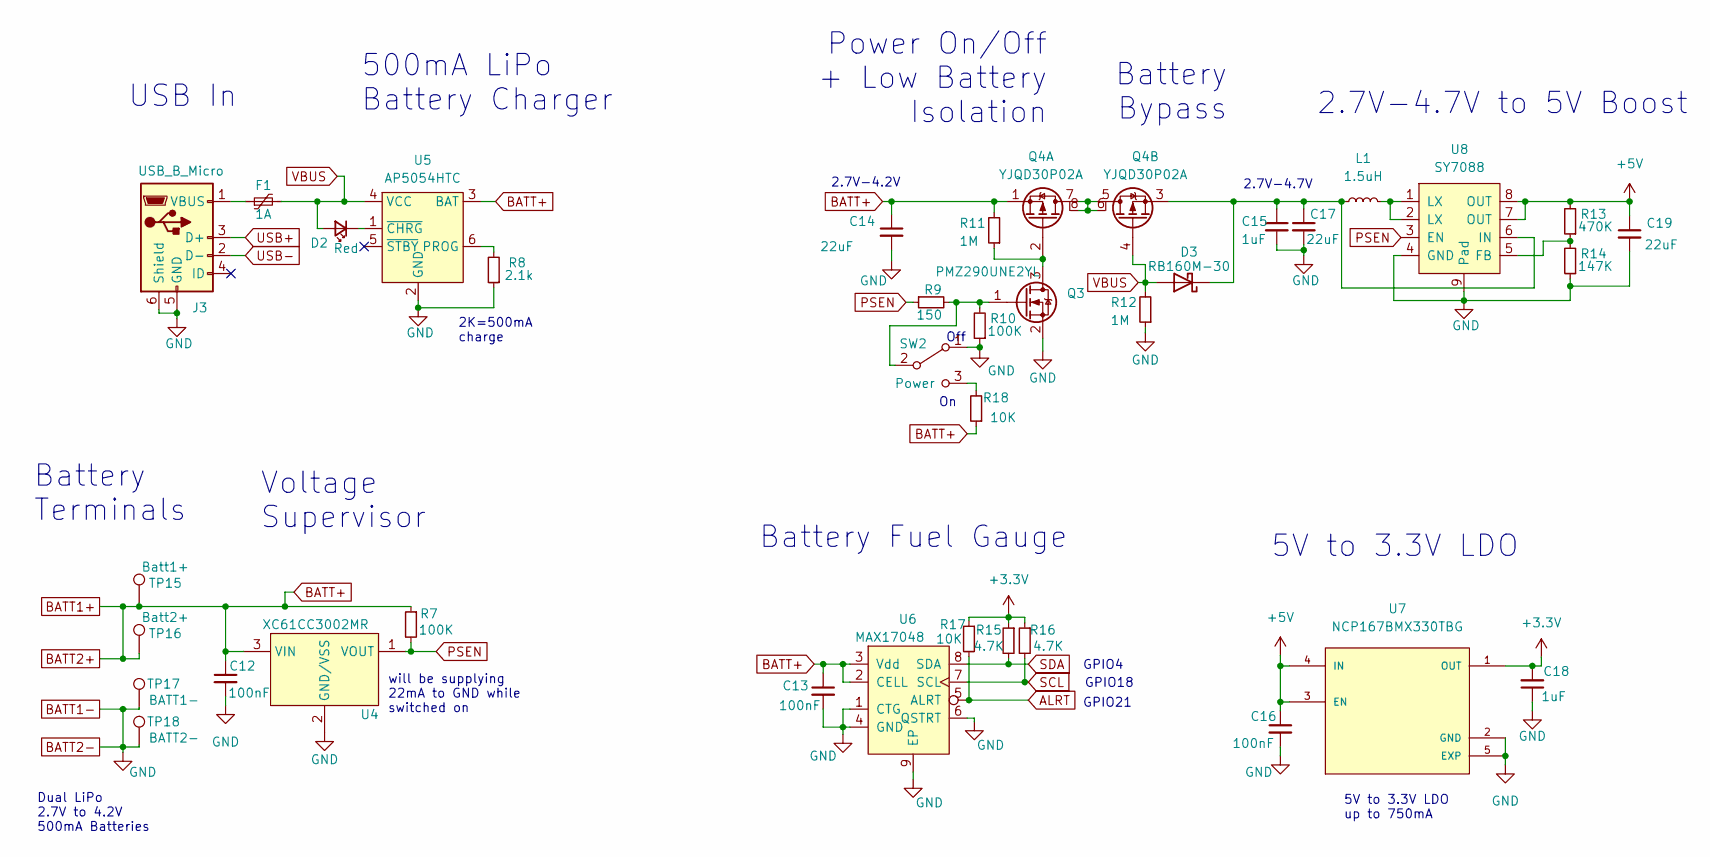
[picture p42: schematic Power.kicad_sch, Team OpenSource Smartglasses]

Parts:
C12: 100nF; C_0402_1005Metric; MPN_LCSC C41851
C13, C16: 100nF; C_0402_1005Metric; MPN 490-GRT155C80J105KE01JCT-ND
C14, C17, C19: 22uF; C_0402_1005Metric; MPN 490-GRT155C80J105KE01JCT-ND
C15, C18: 1uF; C_0402_1005Metric; MPN 490-GRT155C80J105KE01JCT-ND
D2: Red; D_0402_1005Metric; MPN_LCSC C965790
D3: RB160M-30; D_SOD-123; MPN_LCSC C2937163
F1: 1A; R_0805_2012Metric; MPN_LCSC C2830233
J3: USB_B_Micro; USB_Micro-B_Amphenol_10118194_Horizontal; MPN WM1399CT-ND
L1: 1.5uH; 1.5uH_YXMAA0402-1R5M-ANP; MPN_LCSC C241335
Q3: PMZ290UNE2YL; DFN100X60X40-3N; MPN_LCSC C478155
Q4: YJQD30P02A; YJQD30P02A_DFN3.3x3.3; MPN_LCSC C919546
R7: 100K; R_0402_1005Metric; MPN_LCSC C106234
R8: 2.1k; R_0402_1005Metric; MPN_LCSC C100301
R9: 150; R_0402_1005Metric; MPN_LCSC C106234
R10: 100K; R_0402_1005Metric; MPN_LCSC 1
R11, R12: 1M; R_0402_1005Metric; MPN_LCSC C2906900
R13: 470K; R_0402_1005Metric; MPN_LCSC C25562
R14: 147K; R_0402_1005Metric; MPN_LCSC C2933073
R15, R16: 4.7K; R_0402_1005Metric; MPN_LCSC C106234
R17: 10K; R_0402_1005Metric; MPN_LCSC C106234
R18: 10K; R_0402_1005Metric; MPN_LCSC 1
SW2: Power; SW_SMD_SPDT_Slide_9x6.9-hole; MPN_LCSC C145857
TP15: Batt1+; Breakout_pads
TP16: Batt2+; Breakout_pads
TP17: BATT1-; Breakout_pads
TP18: BATT2-; Breakout_pads
U4: XC61CC3002MR; SOT-23; MPN_LCSC C80698
U5: AP5054HTC; SOT-23-6; MPN_LCSC C2843820
U6: MAX17048; DFN-8-1EP_2x2mm_P0.5mm_EP0.8x1.6mm; MPN_LCSC C2682616
U7: NCP167BMX330TBG; REG_NCP167BMX330TBG; PARTREV 3
U8: SY7088; DFN-8-1EP_3x2mm_P0.5mm_EP1.7x1.4mm; MPN_LCSC C178240

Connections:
+5V: C16.1, C19.1, R13.2, U7.3 (EN), U7.4 (IN), U8.7 (OUT), U8.8 (OUT); also elsewhere on the board
ALRT: R17.2, U6.5 (ALRT); also elsewhere on the board
BATT1-: C12.2, C13.2, C14.2, C15.2, C16.2, C17.2, C18.1, C19.2, J3.5 (GND), J3.6 (Shield), Q3.2 (S), R8.1, R10.1, R12.1, R14.1, SW2.1 (A), TP17.1, TP18.1, U4.2 (GND/VSS), U5.2 (GND), U6.1 (CTG), U6.4 (GND), U6.6 (QSTRT), U6.9 (EP), U7.2 (GND), U7.5 (EXP), U8.4 (GND), U8.9 (Pad); also elsewhere on the board
BATT+: C12.1, C13.1, C14.1, Q4.1 (S2), R7.1, R11.2, R18.1, TP15.1, TP16.1, U4.3 (VIN), U5.3 (BAT), U6.2 (CELL), U6.3 (Vdd)
unnamed: C15.1, C17.1, D3.1 (K), L1.1, Q4.3 (S2), U8.6 (IN)
unnamed: D2.1 (K), U5.1 (~CHRG)
unnamed: F1.1, J3.1 (VBUS)
unnamed: L1.2, U8.1 (LX), U8.2 (LX)
unnamed: Q3.1 (G), R9.2, R10.2, SW2.2 (B)
unnamed: Q3.3 (D), Q4.2 (G2), R11.1
unnamed: Q4.5 (D2), Q4.6 (D2), Q4.7 (D2), Q4.8 (D2)
unnamed: R8.2, U5.6 (PROG)
unnamed: R13.1, R14.2, U8.5 (FB)
unnamed: R18.2, SW2.3 (C)
PSEN: R7.2, R9.1, U4.1 (VOUT), U8.3 (EN)
SCL: R16.2, U6.7 (SCL); also elsewhere on the board
SDA: R15.2, U6.8 (SDA); also elsewhere on the board
USB+: J3.3 (D+); also elsewhere on the board
USB-: J3.2 (D-); also elsewhere on the board
VBUS: D2.2 (A), D3.2 (A), F1.2, Q4.4 (G2), R12.2, U5.4 (VCC); also elsewhere on the board

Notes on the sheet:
USB In
Battery Fuel Gauge
2.7V-4.7V to 5V Boost
5V to 3.3V LDO
Power On/Off + Low Battery Isolation
2.7V-4.2V
GPIO18
5V to 3.3V LDO up to 750mA
Off
Battery Bypass
Dual LiPo 2.7V to 4.2V 500mA Batteries
2K=500mA charge
Battery Terminals
Voltage Supervisor
GPIO4
500mA LiPo Battery Charger
GPIO21
will be supplying 22mA to GND while switched on
2.7V-4.7V

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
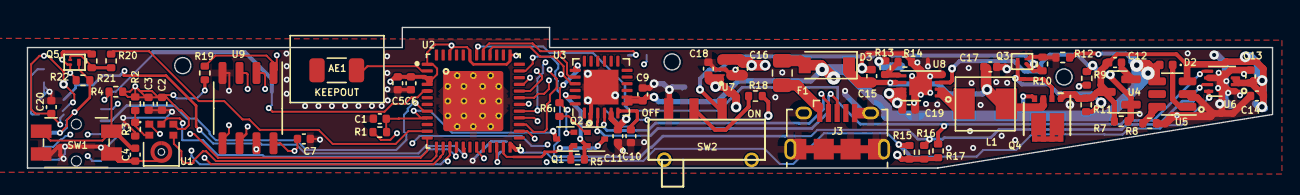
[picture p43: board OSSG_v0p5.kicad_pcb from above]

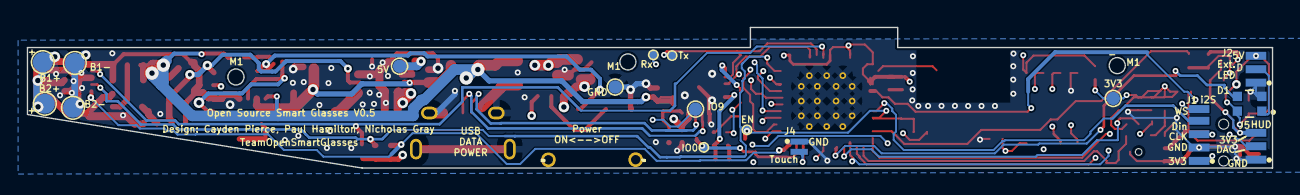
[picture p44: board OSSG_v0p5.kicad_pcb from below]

Board: 4 copper layers, 93.0 x 10.5 mm, 80 parts (17 on the bottom side), 53 nets.

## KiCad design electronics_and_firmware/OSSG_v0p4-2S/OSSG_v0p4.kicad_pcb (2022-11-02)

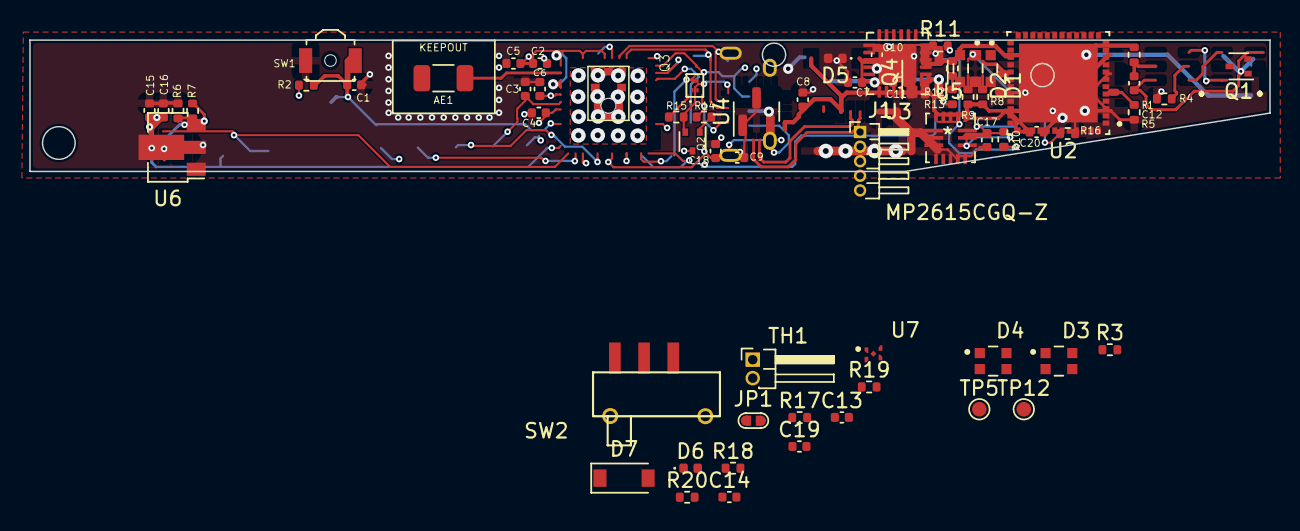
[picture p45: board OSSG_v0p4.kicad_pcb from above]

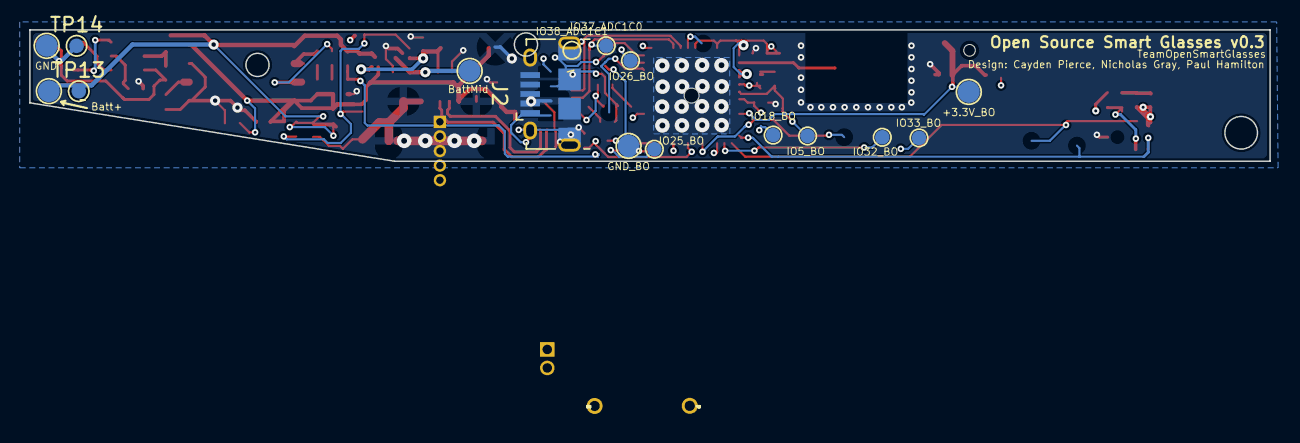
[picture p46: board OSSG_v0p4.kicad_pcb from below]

Board: 4 copper layers, 85.0 x 9.0 mm, 82 parts (16 on the bottom side), 54 nets.

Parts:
AE1: ANT3216LL00R2400A
C1, C12: 100nF; C_0402_1005Metric
C2, C9, C17, C19, C20: 1uF; C_0402_1005Metric
C3: 200pF; C_0402_1005Metric
C4, C18: 10uF; C_0402_1005Metric
C5, C6, C7, C8, C10, C11: 0.1uF; C_0402_1005Metric
C13, C14: 1uF/16V; C_0402_1005Metric
C15: 100nF/16V; C_0402_1005Metric
C16: 22uF/16V; C_0402_1005Metric
D1, D2, D3, D4: WS2812C-2020; LED_WS2812C-2020
D5, D6: LED; D_0402_1005Metric
D7: RB160M-30; D_SOD-123
J1: Conn_01x05_Male; PinHeader_1x05_P1.00mm_Horizontal
J2: USB_B_Micro; USB_Micro-B_Amphenol_10118194_Horizontal
JP1: SolderJumper_2_Open; JUMPER-2Psml_Open_RoundedPad2x1mm
Q1, Q2: 2SC4617R BR; SOT-523
Q3: PMZ290UNE2YL; DFN100X60X40-3N
Q4: EMF20B02V; SOT-23-6
R1, R2: 0R*; R_0402_1005Metric
R3, R4, R5, R7: 10K; R_0402_1005Metric
R6: 100k; R_0402_1005Metric
R8, R9: 2K; R_0402_1005Metric
R10, R18, R20: 100K; R_0402_1005Metric
R11, R12: 442K; R_0402_1005Metric
R13, R14: 160K; R_0402_1005Metric
R15, R19: 884K; R_0402_1005Metric
R16: 320K; R_0402_1005Metric
R17: .025; R_0402_1005Metric
SW1: SW_SPST; SW_SPST_B3U-3000P-B
SW2: Power; SW_SMD_SPDT_Slide_9x6.9-hole
TH1: 10K; PinHeader_1x02_P1.27mm_Horizontal
TP1: IO25_BO; Breakout_pads_small
TP2: IO26_BO; Breakout_pads_small
TP3: IO38_ADC1C1; Breakout_pads_small
TP4: IO37_ADC1C0; Breakout_pads_small
TP5: EN_TP; TestPoint_Pad_D1.0mm
TP6: IO32_BO; Breakout_pads_small
TP7: IO33_BO; Breakout_pads_small
TP8: +3.3V_BO; Breakout_pads
TP9: GND_BO; Breakout_pads
TP10: IO5_BO; Breakout_pads_small
TP11: IO18_BO; Breakout_pads_small
TP12: IO0_TP; TestPoint_Pad_D1.0mm
TP13: TXIN; TestPoint_Pad_D1.0mm
TP14: RXIN; TestPoint_Pad_D1.0mm
TP15: Batt+; Breakout_pads
TP16: GND; Breakout_pads
TP17: BattMid; Breakout_pads
U1: SPH0645LMH; SPH0645LM4H-B-SMD-GND
U2: ESP32-PICO-D4; ESP32_PICO_D4
U3: CH9102F; QFN-24-1EP_4x4mm_P0.5mm_EP2.6x2.6mm
U4: XC61CC3002MR; SOT-23
U5: MP2615CGQ-Z; MP2615GQ-P
U6: H7650-50PR; SOT-89-3
U7: NCP167BMX330TBG; REG_NCP167BMX330TBG

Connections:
+3V3: C1.1, C3.2, C11.1, C20.2, J1.1, R1.2, R3.2, TP8.1, U1.5 (VDD), U2.1 (VDDA), U2.3 (VDDA3P3), U2.4 (VDDA3P3), U2.19 (VDD3P3_RTC), U2.37 (VDD3P3_CPU), U2.43 (VDDA), U2.46 (VDDA), U3.5 (VIO), U7.1 (OUT)
+5V: C18.1, D1.4 (VDD), D2.4 (VDD), D3.4 (VDD), D4.4 (VDD), U6.3 (Vout), U7.3 (EN), U7.4 (IN)
ADC1C0: C6.1, TP4.1, U2.6 (SENSOR_CAPP)
ADC1C1: C7.1, TP3.1, U2.7 (SENSOR_CAPN)
ADC1C2: C8.1, R12.2, R13.1, R15.2, R16.1, U2.5 (SENSOR_VP)
BATT1-: C12.1, R6.1, TP17.1, U4.3 (VIN)
BATT2-: C1.2, C2.2, C3.1, C4.2, C5.2, C6.2, C7.2, C8.2, C9.1, C10.2, C11.2, C12.2, C13.2, C14.2, C16.2, C17.2, C18.2, C19.1, C20.1, D1.2 (GND), D2.2 (GND), D3.2 (GND), D4.2 (GND), J1.2, J2.5 (GND), J2.6 (Shield), JP1.2 (B), Q3.2 (S), R2.1, R10.1, R14.2, R16.2, R18.1, R20.1, SW1.1 (A), SW2.1 (A), TH1.2, TP9.1, TP16.1, U1.3 (GND), U2.49 (GND), U3.2 (GND), U3.25 (GND), U4.2 (GND/VSS), U5.8 (AGND), U5.16 (PGND), U6.1 (GND), U7.2 (GND), U7.5 (EXP)
BATT+: C16.1, Q4.1 (S2), R11.1, R15.1, R17.2, R19.2, TP15.1, U5.9 (BATT)
DTR: Q2.2 (E), R4.1, U3.23 (~DTR)
EN: C2.1, Q1.3 (C), R3.1, SW1.2 (B), TP5.1, U2.9 (EN)
IO0: Q2.3 (C), TP12.1, U2.23 (IO0)
IO4: D1.3 (Din), U2.24 (IO4)
IO5: TP10.1, U2.34 (IO5)
IO9: J1.5, U2.28 (SD2)
IO14: U1.6 (Dout), U2.17 (IO14)
IO18: TP11.1, U2.35 (IO18)
IO21: J1.3, U2.42 (IO21)
IO23: J1.4, U2.36 (IO23)
IO25: TP1.1, U2.14 (IO25)
IO26: TP2.1, U2.15 (IO26)
IO32: TP6.1, U1.4 (BCLK), U2.12 (IO32)
IO33: TP7.1, U1.1 (WS), U2.13 (IO33)
unnamed: AE1.2 (PCB_Trace), U2.2 (LNA_IN)
unnamed: C4.1, C5.1
unnamed: C10.1, U3.6 (V3)
unnamed: C13.1, R7.1, TH1.1, U5.13 (NTC)
unnamed: C14.1, U5.14 (TMR)
unnamed: C15.1, U5.15 (BST)
unnamed: C15.2, U5.1 (SW)
unnamed: D1.1 (Dout), D2.3 (Din)
unnamed: D2.1 (Dout), D3.3 (Din)
unnamed: D3.1 (Dout), D4.3 (Din)
unnamed: D5.1 (K), R9.1
unnamed: D6.1 (K), R8.1
unnamed: JP1.1 (A), U5.4 (CELL)
unnamed: R17.1, U5.10 (CSP)
unnamed: Q1.1 (B), R4.2
unnamed: Q2.1 (B), R5.2
unnamed: Q3.3 (D), Q4.2 (G2), R19.1
unnamed: R1.1, R2.2, U1.2 (SEL)
unnamed: R7.2, U5.3 (VCC)
unnamed: R8.2, U5.12 (~AOK)
unnamed: R9.2, U5.11 (~CHGOK)
unnamed: R10.2, U5.6 (~EN)
unnamed: R11.2, R12.1
unnamed: R13.2, R14.1
PSEN: Q3.1 (G), R6.2, R18.2, SW2.2 (B), U4.1 (VOUT)
RTS: Q1.2 (E), R5.1, U3.19 (~RTS)
RX_ESP: TP14.1, U2.40 (U0RXD), U3.21 (TXD)
TX_ESP: TP13.1, U2.41 (U0TXD), U3.20 (RXD)
USB+: J2.3 (D+), U3.3 (UD+)
USB-: J2.2 (D-), U3.4 (UD-)
V_PSU: C17.1, C19.2, D7.1 (K), Q4.3 (S2), U6.2 (Vin)
V_USB: C9.2, D5.2 (A), D6.2 (A), D7.2 (A), J2.1 (VBUS), Q4.4 (G2), R20.2, U3.7 (VDD5), U3.8 (VBUS), U5.2 (Vin)

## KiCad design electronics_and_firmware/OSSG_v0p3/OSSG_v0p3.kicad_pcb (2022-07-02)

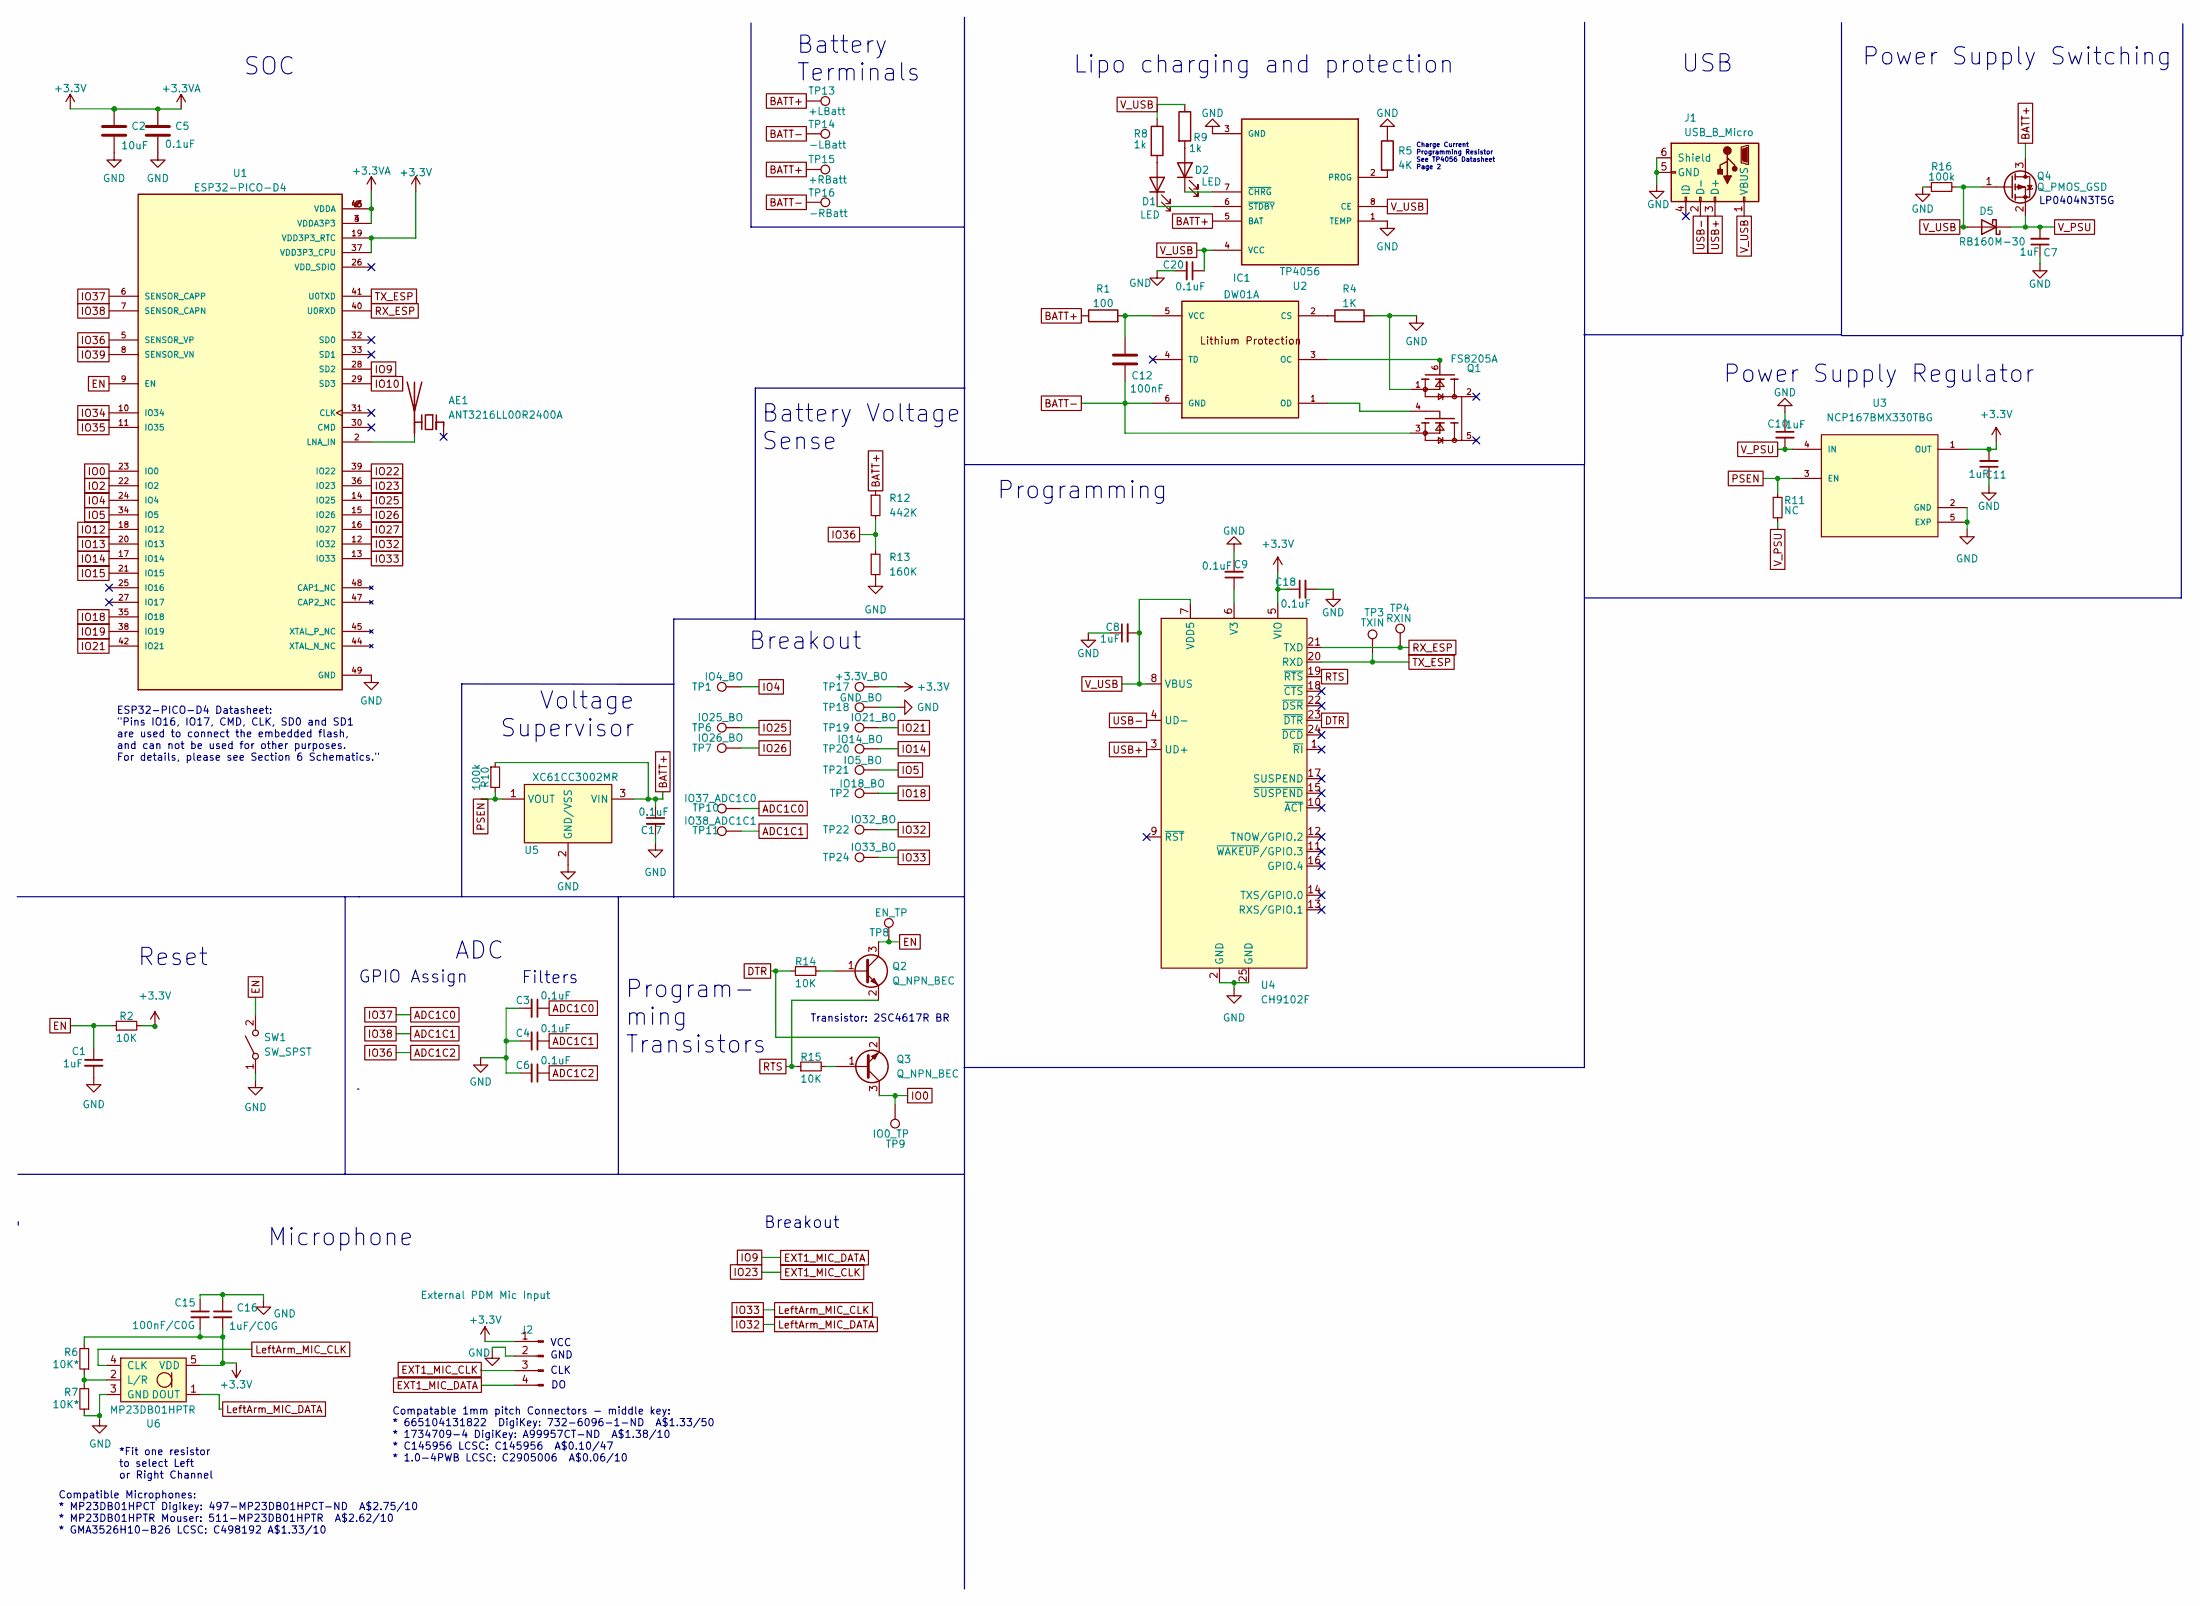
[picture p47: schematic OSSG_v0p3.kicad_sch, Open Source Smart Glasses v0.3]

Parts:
AE1: ANT3216LL00R2400A; MPN_LCSC C293767
C1, C7, C8, C10, C11: 1uF; C_0402_1005Metric; MPN 490-GRT155C80J105KE01JCT-ND
C2: 10uF; C_0402_1005Metric; MPN 1276-1450-1-ND
C3, C4, C6, C17: 0.1uF; C_0402_1005Metric; MPN_LCSC C41851
C5: 0.1uF; C_0402_1005Metric; MPN 1276-1043-1-ND
C9, C18, C20: 0.1uF; C_0402_1005Metric; MPN_LCSC C258109
C12: 100nF; C_0402_1005Metric; MPN_LCSC C41851
C15: 100nF/C0G; C_0402_1005Metric; MPN_LCSC C41851
C16: 1uF/C0G; C_0402_1005Metric; MPN_LCSC C14445
D1: LED; D_0402_1005Metric; MPN_LCSC C2984137
D2: LED; D_0402_1005Metric; MPN_LCSC C2992661
D5: RB160M-30; D_SOD-123; MPN_LCSC C2937163
IC1: DW01A; SOT-23-6; MPN DW01A
J1: USB_B_Micro; USB_Micro-B_Amphenol_10118194_Horizontal; MPN WM1399CT-ND
J2: External PDM Mic Input; Solder-4P-Connector
Q1: FS8205A; SOT-23-6; PARTREV 1.7
Q2, Q3: Q_NPN_BEC; SOT-523; MPN_LCSC C2836080
Q4: Q_PMOS_GSD; SOT-883; MPN_LCSC C172433
R1: 100; R_0402_1005Metric; MPN_LCSC C258109
R2, R14, R15: 10K; R_0402_1005Metric; MPN RMCF0402JT10K0CT-ND
R4: 1K; R_0402_1005Metric; MPN_LCSC C2906899
R5: 4K; R_0402_1005Metric; MPN_LCSC C43251
R6, R7: 10K*; R_0402_1005Metric; MPN RMCF0402JT10K0CT-ND
R8, R9: 1k; R_0402_1005Metric; MPN_LCSC C2906899
R10: 100k; R_0402_1005Metric; MPN_LCSC C106234
R11: NC; R_0201_0603Metric
R12: 442K; R_0402_1005Metric; MPN_LCSC C273339
R13: 160K; R_0402_1005Metric; MPN_LCSC C423115
R16: 100k; R_0402_1005Metric; MPN_LCSC 1
SW1: SW_SPST; SW_SPST_B3U-3000P-B; MPN SW1103CT-ND
TP1: IO4_BO; Breakout_pads_small
TP2: IO18_BO; Breakout_pads_small
TP3: TXIN; TestPoint_Pad_D1.0mm
TP4: RXIN; TestPoint_Pad_D1.0mm
TP6: IO25_BO; Breakout_pads_small
TP7: IO26_BO; Breakout_pads_small
TP8: EN_TP; TestPoint_Pad_D1.0mm
TP9: IO0_TP; TestPoint_Pad_D1.0mm
TP10: IO37_ADC1C0; Breakout_pads_small
TP11: IO38_ADC1C1; Breakout_pads_small
TP13: +LBatt; Breakout_pads
TP14: -LBatt; Breakout_pads
TP15: +RBatt; Breakout_pads
TP16: -RBatt; Breakout_pads
TP17: +3.3V_BO; Breakout_pads
TP18: GND_BO; Breakout_pads
TP19: IO21_BO; Breakout_pads_small
TP20: IO14_BO; Breakout_pads_small
TP21: IO5_BO; Breakout_pads_small
TP22: IO32_BO; Breakout_pads_small
TP24: IO33_BO; Breakout_pads_small
U1: ESP32-PICO-D4; ESP32_PICO_D4; PARTREV v1.9
U2: TP4056; SOP-8_5.28x5.23mm_P1.27mm; MPN_LCSC C21417
U3: NCP167BMX330TBG; REG_NCP167BMX330TBG; PARTREV 3
U4: CH9102F; QFN-24-1EP_4x4mm_P0.5mm_EP2.6x2.6mm; MPN_LCSC C2858418
U5: XC61CC3002MR; SOT-23; MPN_LSCC C80698
U6: MP23DB01HPTR; MPN 497-MP23DB01HPCT-ND

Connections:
+3.3VA: C2.1, C5.1, U1.1 (VDDA), U1.3 (VDDA3P3), U1.4 (VDDA3P3), U1.43 (VDDA), U1.46 (VDDA)
+3V3: C11.2, C15.2, C16.2, C18.1, J2.1, R2.2, R6.2, TP17.1, U1.19 (VDD3P3_RTC), U1.37 (VDD3P3_CPU), U3.1 (OUT), U4.5 (VIO), U6.5 (VDD)
ADC1C0: C3.1, TP10.1, U1.6 (SENSOR_CAPP)
ADC1C1: C4.1, TP11.1, U1.7 (SENSOR_CAPN)
ADC1C2: C6.1, R12.2, R13.1, U1.5 (SENSOR_VP)
BATT+: C17.1, Q4.3 (D), R1.1, R10.1, R12.1, TP13.1, TP15.1, U2.5 (BAT), U5.3 (VIN)
BATT-: C12.2, IC1.6 (GND), Q1.3 (S2), TP14.1, TP16.1
DTR: Q3.2 (E), R14.1, U4.23 (~DTR)
EN: C1.1, Q2.3 (C), R2.1, SW1.2 (B), TP8.1, U1.9 (EN)
EXT1_MIC_CLK: J2.3, U1.36 (IO23)
EXT1_MIC_DATA: J2.4, U1.28 (SD2)
GND: C1.2, C2.2, C3.2, C4.2, C5.2, C6.2, C7.1, C8.1, C9.2, C10.1, C11.1, C15.1, C16.1, C17.2, C18.2, C20.2, J1.5 (GND), J1.6 (Shield), J2.2, Q1.1 (S1), R4.2, R5.1, R7.1, R13.2, R16.1, SW1.1 (A), TP18.1, U1.49 (GND), U2.1 (TEMP), U2.3 (GND), U3.2 (GND), U3.5 (EXP), U4.2 (GND), U4.25 (GND), U5.2 (GND/VSS), U6.3 (GND)
IO0: Q3.3 (C), TP9.1, U1.23 (IO0)
IO2: U1.22 (IO2)
IO4: TP1.1, U1.24 (IO4)
IO5: TP21.1, U1.34 (IO5)
IO10: U1.29 (SD3)
IO12: U1.18 (IO12)
IO13: U1.20 (IO13)
IO14: TP20.1, U1.17 (IO14)
IO15: U1.21 (IO15)
IO18: TP2.1, U1.35 (IO18)
IO19: U1.38 (IO19)
IO21: TP19.1, U1.42 (IO21)
IO22: U1.39 (IO22)
IO25: TP6.1, U1.14 (IO25)
IO26: TP7.1, U1.15 (IO26)
IO27: U1.16 (IO27)
IO32: TP22.1, U1.12 (IO32), U6.1 (DOUT)
IO33: TP24.1, U1.13 (IO33), U6.4 (CLK)
IO34: U1.10 (IO34)
IO35: U1.11 (IO35)
IO39: U1.8 (SENSOR_VN)
unnamed: AE1.2 (PCB_Trace), U1.2 (LNA_IN)
unnamed: C9.1, U4.6 (V3)
unnamed: C12.1, IC1.5 (VCC), R1.2
unnamed: D1.1 (K), U2.6 (~STDBY)
unnamed: D1.2 (A), R8.2
unnamed: D2.1 (K), U2.7 (~CHRG)
unnamed: D2.2 (A), R9.2
unnamed: IC1.1 (OD), Q1.4 (G2)
unnamed: IC1.2 (CS), R4.1
unnamed: IC1.3 (OC), Q1.6 (G1)
unnamed: Q2.1 (B), R14.2
unnamed: Q3.1 (B), R15.2
unnamed: R5.2, U2.2 (PROG)
unnamed: R6.1, R7.2, U6.2 (L/R)
PSEN: R10.2, R11.1, U3.3 (EN), U5.1 (VOUT)
RTS: Q2.2 (E), R15.1, U4.19 (~RTS)
RX_ESP: TP4.1, U1.40 (U0RXD), U4.21 (TXD)
TX_ESP: TP3.1, U1.41 (U0TXD), U4.20 (RXD)
USB+: J1.3 (D+), U4.3 (UD+)
USB-: J1.2 (D-), U4.4 (UD-)
V_PSU: C7.2, C10.2, D5.1 (K), Q4.2 (S), R11.2, U3.4 (IN)
V_USB: C8.2, C20.1, D5.2 (A), J1.1 (VBUS), Q4.1 (G), R8.1, R9.1, R16.2, U2.4 (VCC), U2.8 (CE), U4.7 (VDD5), U4.8 (VBUS)

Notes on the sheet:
Battery Terminals
SOC
Programming
Compatable 1mm pitch Connectors - middle key: * 665104131822 DigiKey: 732-6096-1-ND A$1.33/50 * 1734709-4 DigiKey: A99957CT-ND A$1.38/10 * C145956 LCSC: C145956 A$0.10/47 * 1.0-4PWB LCSC: C2905006 A$0.06/10
LP0404N3T5G
Reset
Filters
GND
Breakout
*Fit one resistor to select Left or Right Channel
ESP32-PICO-D4 Datasheet: "Pins IO16, IO17, CMD, CLK, SD0 and SD1 are used to connect the embedded flash, and can not be used for other purposes. For details, please see Section 6 Schematics."
Transistor: 2SC4617R BR
USB
Lipo charging and protection
Voltage Supervisor
GPIO Assign
Microphone
Power Supply Regulator
ADC
CLK
Power Supply Switching
Charge Current Programming Resistor See TP4056 Datasheet Page 2
Compatible Microphones: * MP23DB01HPCT Digikey: 497-MP23DB01HPCT-ND A$2.75/10 * MP23DB01HPTR Mouser: 511-MP23DB01HPTR A$2.62/10 * GMA3526H10-B26 LCSC: C498192 A$1.33/10
VCC
Battery Voltage Sense
Program- ming Transistors

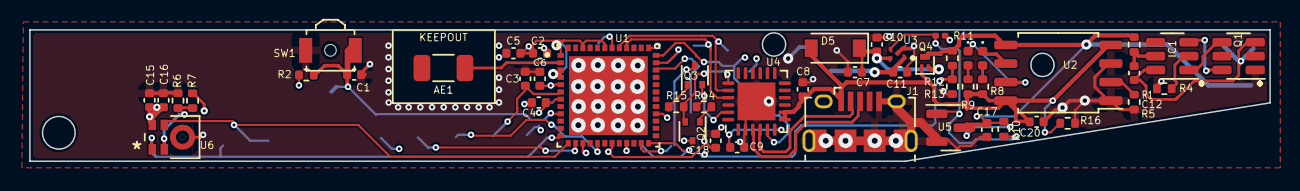
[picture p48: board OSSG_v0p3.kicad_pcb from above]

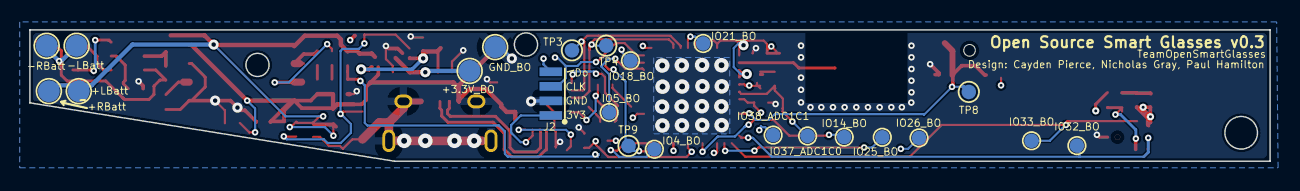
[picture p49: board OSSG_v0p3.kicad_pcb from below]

Board: 4 copper layers, 85.0 x 9.0 mm, 71 parts (22 on the bottom side), 44 nets.

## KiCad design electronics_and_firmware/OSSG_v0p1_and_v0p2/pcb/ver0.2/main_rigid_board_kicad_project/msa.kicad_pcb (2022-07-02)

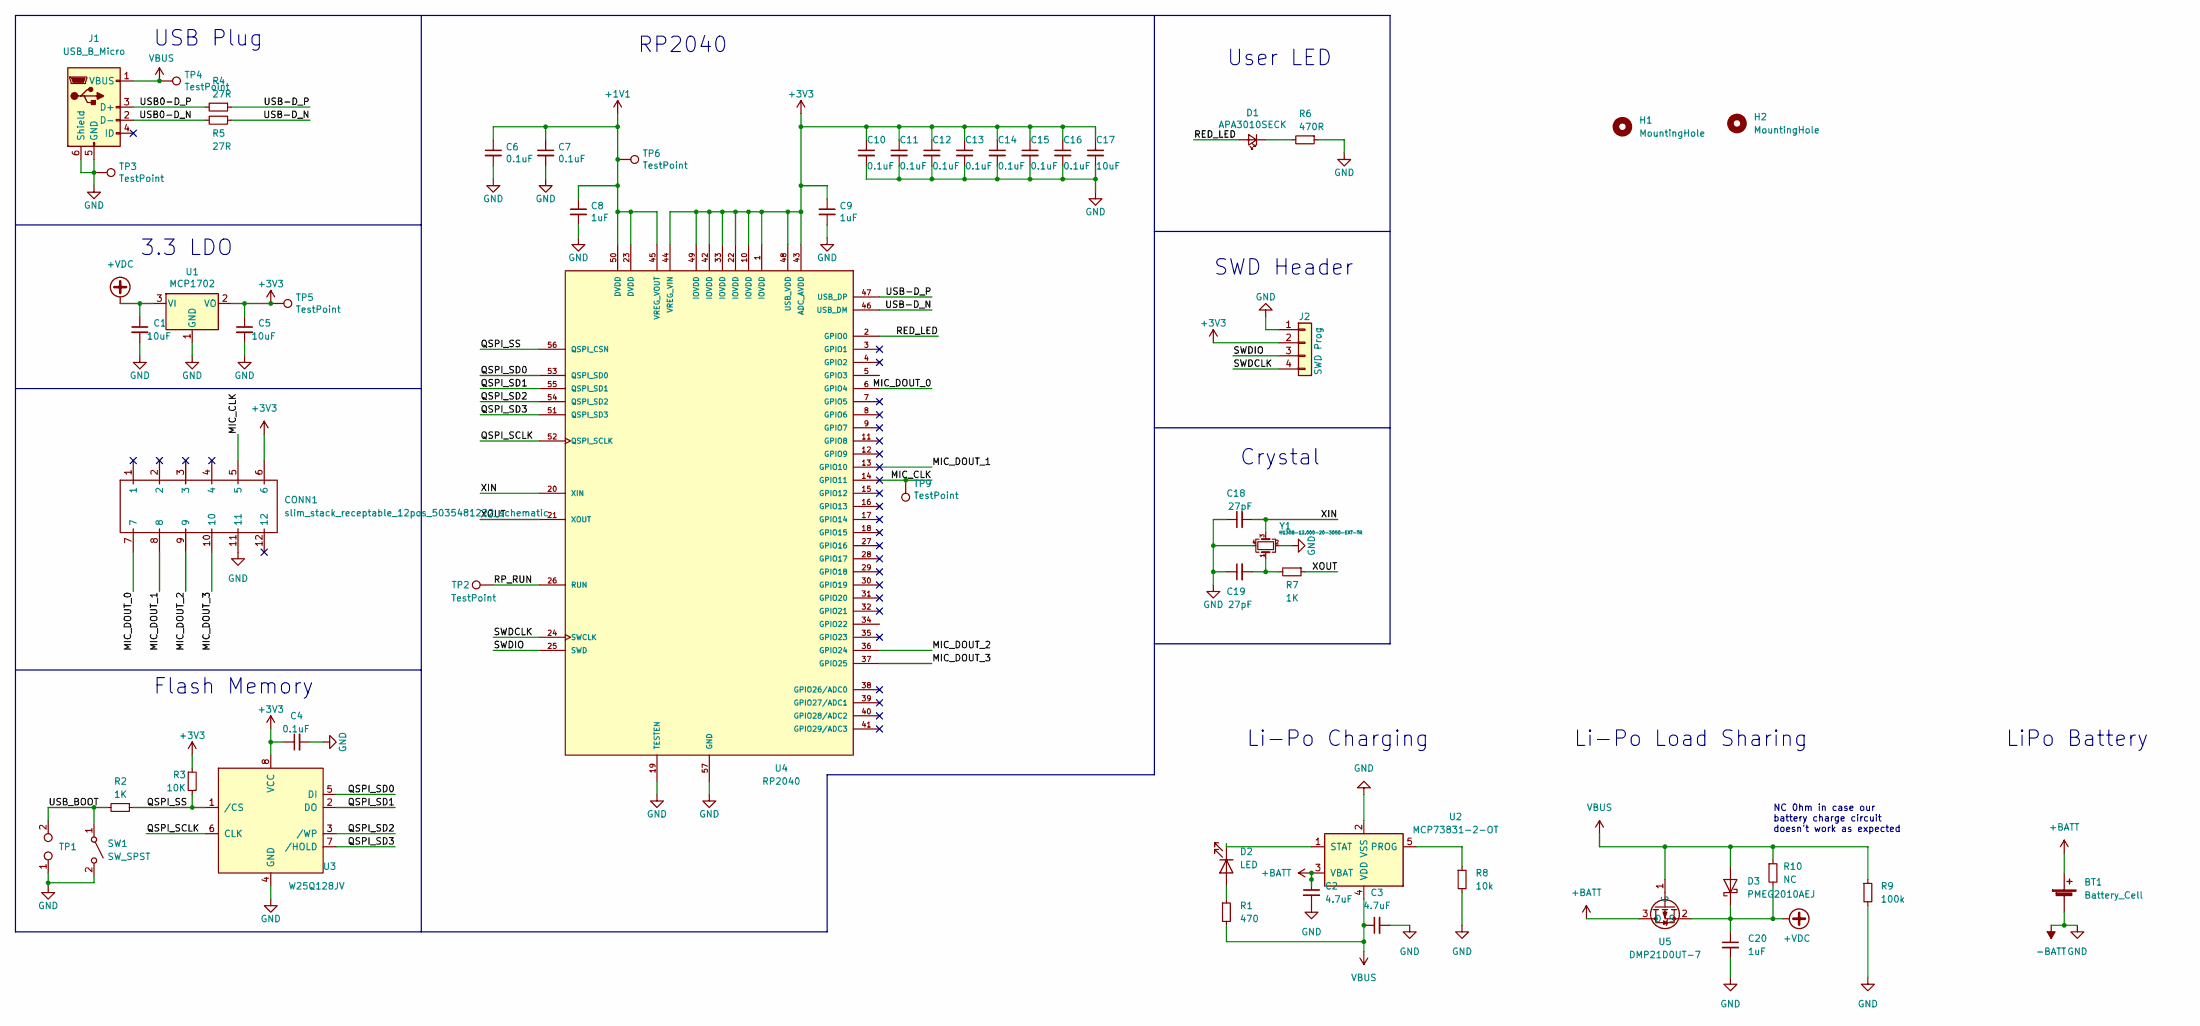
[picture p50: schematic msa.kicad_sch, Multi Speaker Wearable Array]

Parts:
BT1: Battery_Cell; BatterySolderOn
C1, C5, C17: 10uF; C_0402_1005Metric
C2, C3: 4.7uF; C_0402_1005Metric_Pad0.74x0.62mm_HandSolder
C4, C6, C7, C10, C11, C12, C13, C14, C15, C16: 0.1uF; C_0402_1005Metric
C8, C9: 1uF; C_0402_1005Metric
C18, C19: 27pF; C_0402_1005Metric
C20: 1uF; C_0402_1005Metric_Pad0.74x0.62mm_HandSolder
CONN1: slim_stack_receptable_12pos_5035481222_schematic; slim_stack_molex_RECEPTACLE_5035481222
D1: APA3010SECK; LED_0402_1005Metric
D2: LED; LED_0402_1005Metric
D3: PMEG2010AEJ; D_SOD-323F
H1, H2: MountingHole; Mount_hole_small_0.7mm
J1: USB_B_Micro; micro_usb_right_angle_1050170001_molex
J2: SWD Prog; SMD_1x04_P1.27mm
R1: 470; C_0402_1005Metric_Pad0.74x0.62mm_HandSolder
R2, R7: 1K; R_0402_1005Metric
R3: 10K; R_0402_1005Metric
R4, R5: 27R; R_0402_1005Metric
R6: 470R; R_0402_1005Metric
R8: 10k; C_0402_1005Metric_Pad0.74x0.62mm_HandSolder
R9: 100k; C_0402_1005Metric_Pad0.74x0.62mm_HandSolder
R10: NC; R_0402_1005Metric
SW1: SW_SPST; SW_SPST_B3U-3100P-B
TP1: TestPoint_2Pole; SMD_1x02_P1.27mm
TP2, TP3, TP4, TP5, TP6, TP9: TestPoint; SMD_1x01_P1.27mm
U1: MCP1702; SOT-23
U2: MCP73831-2-OT; SOT-23-5
U3: W25Q128JV; PSON50P300X200X60-9N
U4: RP2040; QFN40P700X700X90-57N; PARTREV 1.6.1
U5: ‎DMP21D0UT-7‎; SOT-523
Y1: H130B-12.000-20-3050-EXT-TR; Crystal_SMD_5032-4Pin_5.0x3.2mm

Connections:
+1V1: C6.1, C7.1, C8.1, TP6.1, U4.23 (DVDD), U4.45 (VREG_VOUT), U4.50 (DVDD)
+3V3: C4.1, C5.1, C9.1, C10.1, C11.1, C12.1, C13.1, C14.1, C15.1, C16.1, C17.1, CONN1.6, J2.2, R3.1, TP5.1, U1.2 (VO), U3.8 (VCC), U4.1 (IOVDD), U4.10 (IOVDD), U4.22 (IOVDD), U4.33 (IOVDD), U4.42 (IOVDD), U4.43 (ADC_AVDD), U4.44 (VREG_VIN), U4.48 (USB_VDD), U4.49 (IOVDD)
+BATT: BT1.1 (+), C2.1, U2.3 (VBAT), U5.3 (D)
+VDC: C1.1, C20.1, D3.1 (K), R10.2, U1.3 (VI), U5.2 (S)
-BATT: BT1.2 (-), C1.2, C2.2, C3.2, C4.2, C5.2, C6.2, C7.2, C8.2, C9.2, C10.2, C11.2, C12.2, C13.2, C14.2, C15.2, C16.2, C17.2, C18.1, C19.1, C20.2, CONN1.11, J1.5 (GND), J1.6 (Shield), J2.1, R6.1, R8.2, R9.2, SW1.2 (B), TP1.1, TP3.1, U1.1 (GND), U2.2 (VSS), U3.4 (GND), U4.19 (TESTEN), U4.57 (GND), Y1.2, Y1.4
/MIC_CLK: CONN1.5, TP9.1, U4.14 (GPIO11)
/MIC_DOUT_0: CONN1.7, U4.6 (GPIO4)
/MIC_DOUT_1: CONN1.8, U4.13 (GPIO10)
/MIC_DOUT_2: CONN1.9, U4.36 (GPIO24)
/MIC_DOUT_3: CONN1.10, U4.37 (GPIO25)
/QSPI_SCLK: U3.6 (CLK), U4.52 (QSPI_SCLK)
/QSPI_SD0: U3.5 (DI), U4.53 (QSPI_SD0)
/QSPI_SD1: U3.2 (DO), U4.55 (QSPI_SD1)
/QSPI_SD2: U3.3 (/WP), U4.54 (QSPI_SD2)
/QSPI_SD3: U3.7 (/HOLD), U4.51 (QSPI_SD3)
/QSPI_SS: R2.1, R3.2, U3.1 (/CS), U4.56 (QSPI_CSN)
/RED_LED: D1.2 (A), U4.2 (GPIO0)
/RP_RUN: TP2.1, U4.26 (RUN)
/SWDCLK: J2.4, U4.24 (SWCLK)
/SWDIO: J2.3, U4.25 (SWD)
/USB0-D_N: J1.2 (D-), R5.2
/USB0-D_P: J1.3 (D+), R4.2
/USB-D_N: R5.1, U4.46 (USB_DM)
/USB-D_P: R4.1, U4.47 (USB_DP)
/USB_BOOT: R2.2, SW1.1 (A), TP1.2
/XIN: C18.2, U4.20 (XIN), Y1.3
/XOUT: R7.1, U4.21 (XOUT)
unnamed: C19.2, R7.2, Y1.1
unnamed: D1.1 (K), R6.2
unnamed: D2.1 (K), U2.1 (STAT)
unnamed: D2.2 (A), R1.1
unnamed: R8.1, U2.5 (PROG)
VBUS: C3.1, D3.2 (A), J1.1 (VBUS), R1.2, R9.1, R10.1, TP4.1, U2.4 (VDD), U5.1 (G)

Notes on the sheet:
NC 0hm in case our battery charge circuit doesn't work as expected
USB Plug
Li-Po Charging
Li-Po Load Sharing
Crystal
Flash Memory
SWD Header
User LED
3.3 LDO
RP2040
LiPo Battery



Board: 2 copper layers, 47.8 x 9.4 mm, 53 parts (15 on the bottom side), 33 nets.

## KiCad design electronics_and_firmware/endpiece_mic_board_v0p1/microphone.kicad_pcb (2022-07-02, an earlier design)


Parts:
C1: 100nF/C0G; C_0402_1005Metric
C2: 1uF/C0G; C_0402_1005Metric
G1: Microphone_Graphic; Microhone_Graphic_sml
J1: PDM Mic; Solder-4P-Connector
R1, R2: 10K*; R_0402_1005Metric
U1: MP23DB01HPTR

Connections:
GND: C1.1, C2.1, J1.2, R2.2, U1.3 (GND)
unnamed: C1.2, C2.2, J1.1, R1.1, U1.5 (VDD)
unnamed: J1.3, U1.4 (CLK)
unnamed: J1.4, U1.1 (DOUT)
unnamed: R1.2, R2.1, U1.2 (L/R)

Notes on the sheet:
Compatable 1mm pitch Connectors - middle key: * 665104131822 DigiKey: 732-6096-1-ND A$1.33/50 * 1734709-4 DigiKey: A99957CT-ND A$1.38/10 * C145956 LCSC: C145956 A$0.10/47 * 1.0-4PWB LCSC: C2905006 A$0.06/10
CLK
*Fit one resistor to select Left or Right Channel
Compatible Microphones: * MP23DB01HPCT Digikey: 497-MP23DB01HPCT-ND A$2.75/10 * MP23DB01HPTR Mouser: 511-MP23DB01HPTR A$2.62/10 * GMA3526H10-B26 LCSC: C498192 A$1.33/10
GND
VCC



Board: 2 copper layers, 5.1 x 5.8 mm, 7 parts (6 on the bottom side), 5 nets.

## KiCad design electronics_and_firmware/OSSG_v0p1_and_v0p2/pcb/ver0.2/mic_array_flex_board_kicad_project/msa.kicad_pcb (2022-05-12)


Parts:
C2, C20, C22, C24: 0.1uF; C_0402_1005Metric
C3, C21, C23, C25: 1uF; C_0402_1005Metric
CONN1: slim_stack_12pos_5035521222_schematic; slim_stack_molex_PLUG_5035521222
R1, R8, R9, R10, R11, R12, R13, R14: 10K; R_0402_1005Metric
TP1, TP2, TP7, TP8, TP10, TP11: TestPoint; SMD_1x01_P1.27mm
U2, U5, U6, U7: MP23DB01HPTR; MIC_SPH0641LU4H-1

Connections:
+3V3: C2.2, C3.2, C20.2, C21.2, C22.2, C23.2, C24.2, C25.2, CONN1.6, R1.1, R9.1, R11.1, R13.1, TP2.1, U2.5 (VDD), U5.5 (VDD), U6.5 (VDD), U7.5 (VDD)
/MIC_CLK: CONN1.5, U2.4 (CLK), U5.4 (CLK), U6.4 (CLK), U7.4 (CLK)
/MIC_DOUT_0: CONN1.7, TP7.1, U2.1 (DOUT)
/MIC_DOUT_1: CONN1.8, TP8.1, U5.1 (DOUT)
/MIC_DOUT_2: CONN1.9, TP10.1, U6.1 (DOUT)
/MIC_DOUT_3: CONN1.10, TP11.1, U7.1 (DOUT)
GND: C2.1, C3.1, C20.1, C21.1, C22.1, C23.1, C24.1, C25.1, CONN1.11, R8.2, R10.2, R12.2, R14.2, TP1.1, U2.3 (GND), U5.3 (GND), U6.3 (GND), U7.3 (GND)
unnamed: R1.2, R8.1, U2.2 (L/R)
unnamed: R9.2, R10.1, U5.2 (L/R)
unnamed: R11.2, R12.1, U6.2 (L/R)
unnamed: R13.2, R14.1, U7.2 (L/R)

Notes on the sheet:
WARNING: This must match the pinout on the main rigid board that is attaches to, you can't just arbitrarily change this, you have to align it with the other board, because it's a PCB-PCB connector.
PCB-PCB Connector - Slim Stack Molex
PDM Microphone Array


Board: 2 copper layers, 206.5 x 4.6 mm, 27 parts (0 on the bottom side), 11 nets.

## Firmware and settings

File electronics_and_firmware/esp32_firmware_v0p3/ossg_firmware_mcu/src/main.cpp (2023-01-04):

//Open Source Smart Glasses main firmware - Wearable Intelligence System thin client
//OSSG repo: https://github.com/CaydenPierce/OpenSourceSmartGlasses
//Wearable Intelligence System Repo: https://github.com/emexlabs/WearableIntelligenceSystem
//OSSG firmware authors: Cayden Pierce, Alex Israelov

static const char *TAG = "MAIN_OSSG";

#include "../include/ossg_constants.hpp"
#include <stdio.h>
#include <stdlib.h>
#include <string.h>
#include "esp_event.h"
#include "freertos/FreeRTOS.h"
#include "freertos/task.h"
#include "freertos/event_groups.h"
#include "freertos/message_buffer.h"
#include "esp_system.h"
#include "esp_log.h"
#include "nvs_flash.h"

//wifi and websocket communications
#include "wifi_websocket_comms.hpp"

// JSON parsing
#include "json_parse.hpp"

//audio
#include "microphones.hpp"

//gpio
#include "driver/gpio.h"

//websocket buffer
MessageBufferHandle_t websocketSendBuffer;
const size_t websocketSendBufferLen = (1024 * 4 * sizeof(char *)) + sizeof(size_t); // room for websocket buffer, room for one size_t for MessageBuffer overhead

#define MEM_MSG 0

#define ENABLEDISPLAY 1

#if ENABLEDISPLAY
    #include "displaymanager.hpp"
#endif

#include <iostream>
using std::cout;
using std::endl;

void printPerfInfo(bool justHeap = false){
    if(!justHeap){
        printf( "Task Name\tStatus\tPrio\tHWM\tTask\tAffinity\n");
        char stats_buffer[1024];
        vTaskList(stats_buffer);
        printf("%s\n", stats_buffer);
        int dog =  heap_caps_get_largest_free_block(MALLOC_CAP_8BIT);
        printf("===========\nLargest free block: %d\nMin free heap: %d\n===========", dog, esp_get_minimum_free_heap_size());
    }

    ESP_LOGI(TAG, "INTERNAL heap_caps_get_free_size:          %d\n", heap_caps_get_free_size(MALLOC_CAP_8BIT | MALLOC_CAP_INTERNAL));
    ESP_LOGI(TAG, "INTERNAL heap_caps_get_minimum_free_size:  %d\n", heap_caps_get_minimum_free_size(MALLOC_CAP_8BIT | MALLOC_CAP_INTERNAL));
    ESP_LOGI(TAG, "INTERNAL heap_caps_get_largest_free_block: %d\n", heap_caps_get_largest_free_block(MALLOC_CAP_8BIT | MALLOC_CAP_INTERNAL));
}

MessageBufferHandle_t eventsBuffer;
const size_t eventsBufferLen = (1024 * 1 * sizeof(char *)) + sizeof(size_t); // room for events buffer, room for one size_t for MessageBuffer overhead

MessageTypes messageTypesList;
//# currentModeSize = 1024;
char currentMode[1024];
int currentModeSize = 1024;

void eventDistributor(void *args){
    messageTypesList = MessageTypes();
    char * jsonString = (char *)malloc(eventsBufferLen);
    
    //start with current mode being home
    snprintf(currentMode, currentModeSize, messageTypesList.MODE_HOME);

    while (true)
    {
        //vTaskDelay(pdMS_TO_TICKS(1000));
        
        int bytes_written = xMessageBufferReceive(eventsBuffer, jsonString, eventsBufferLen, portMAX_DELAY);
        
        if (bytes_written != 0){
            //ESP_LOGI(TAG, "===========\nESP EVENT DISTR GOT EVENT!!!\n===========");
            //printPerfInfo(true);
            vTaskDelay(pdMS_TO_TICKS(1));
            ESP_LOGI(TAG, "%s", jsonString);
            JsonMessageParser* jsonMessageParser = new JsonMessageParser(jsonString);
            char * messageType = (*jsonMessageParser).getMessageType();
            //ESP_LOGI(TAG, "Message Type is: %s", messageType);
            //can't use a switch statement here, so big if-else
            if (!strcmp(messageType, messageTypesList.FINAL_TRANSCRIPT)){
                ESP_LOGI(TAG, "GOT FINAL TRANSCRIPT");

                ESP_LOGI(TAG, "222 NEW MODE IS: %s", currentMode);
                ESP_LOGI(TAG, "222 Hopeing for: %s", messageTypesList.MODE_LIVE_LIFE_CAPTIONS);
                //if our current mode is live life captions, display the intermediate caption
                if(!strcmp(currentMode, messageTypesList.MODE_LIVE_LIFE_CAPTIONS)){
                    ESP_LOGI(TAG, "RUNNIGN LLC");
                    char * title = "Live Life Captions:";
                    char * body = (*jsonMessageParser).getJsonKey(messageTypesList.TRANSCRIPT_TEXT);
                    ESP_LOGI(TAG, "BODY IS: %s", body);
                    #if ENABLEDISPLAY
                        displayLiveCaptions(title, body);
                    #endif
                }
            } else if (!strcmp(messageType, messageTypesList.INTERMEDIATE_TRANSCRIPT)){
                //ESP_LOGI(TAG, "GOT INTERMEDIATE TRANSCRIPT");
            } else if (!strcmp(messageType, messageTypesList.SEARCH_ENGINE_RESULT)){
                ESP_LOGI(TAG, "GOT SEARCH ENGINE RESULT");
                JsonMessageParser *searchEngineResultData = new JsonMessageParser((*jsonMessageParser).getJsonKey(messageTypesList.SEARCH_ENGINE_RESULT_DATA));
                char * title = (*searchEngineResultData).getJsonKey(messageTypesList.SEARCH_ENGINE_RESULT_DATA_TITLE);
                char * body = (*searchEngineResultData).getJsonKey(messageTypesList.SEARCH_ENGINE_RESULT_DATA_BODY);
                char * image = (*searchEngineResultData).getJsonKey(messageTypesList.SEARCH_ENGINE_RESULT_DATA_IMAGE);
                ESP_LOGI(TAG, "title: %s \n body: %s \n image: %s", title, body, image);
                
                //call display reference card here with title, body, image arguments
                #if ENABLEDISPLAY
                displaySearchEngineResult(title, body, image);
                #endif

                delete searchEngineResultData;
            }
            else if(!strcmp(messageType, messageTypesList.TRANSLATE_TEXT_RESULT)){
                ESP_LOGI(TAG,"GOT TRANSLATION RESULT");
                char * title = "Translation result:";
                char * body = (*jsonMessageParser).getJsonKey(messageTypesList.TRANSLATE_TEXT_RESULT_DATA);
                //call display reference card here with title, body, image arguments
                #if ENABLEDISPLAY
                //displaySearchEngineResult(title, body);
                displayLiveCaptions(title, body);
                #endif
            }
            else if(!strcmp(messageType, messageTypesList.ACTION_SWITCH_MODES)){
                ESP_LOGI(TAG, "GOT NEW MODE");
                //currentMode = strdup((*jsonMessageParser).getJsonKey(messageTypesList.NEW_MODE));
                snprintf(currentMode, currentModeSize, (*jsonMessageParser).getJsonKey(messageTypesList.NEW_MODE));
                ESP_LOGI(TAG, "NEW MODE IS: %s", currentMode);
                ESP_LOGI(TAG, "Hopeing for: %s", messageTypesList.MODE_LIVE_LIFE_CAPTIONS);

                #if ENABLEDISPLAY
                    if(!strcmp(currentMode, messageTypesList.MODE_HOME)){
                        displayEnterVoiceCommandStep1();
                    }
                #endif
            }
            delete jsonMessageParser;
        }
    }
    free(jsonString);
}

void startTheDisplay(){
    #if ENABLEDISPLAY
        //start display+LovyanGFX+LVGL
        displayStart();
        displayEnterVoiceCommandStep2();
    #endif
}

extern "C"
{
    void app_main();
}
void app_main(void)
{
    int maxHeap = esp_get_free_heap_size();
    ESP_LOGI(TAG, "Free heap before NVS : %d", heap_caps_get_free_size(MALLOC_CAP_8BIT));
    esp_err_t ret;

    // NVS flash uses ~3000 bytes
    // Initialize NVS.
    ret = nvs_flash_init();
    if (ret == ESP_ERR_NVS_NO_FREE_PAGES || ret == ESP_ERR_NVS_NEW_VERSION_FOUND)
    {
        ESP_ERROR_CHECK(nvs_flash_erase());
        ret = nvs_flash_init();
    }
    ESP_ERROR_CHECK(ret);

    // create event loop
    ESP_ERROR_CHECK(esp_event_loop_create_default());

    //start the display
    #if ENABLEDISPLAY
        startTheDisplay();
    #endif

    // start WIFI
    wifi_init_sta();
    
    //setup eventsDistributor and eventsBuffer, which handles incoming data from WIS and calls functions based on what WIS tells us to do
    eventsBuffer = xMessageBufferCreate(eventsBufferLen);
    TaskHandle_t eventsTask = NULL;
    xTaskCreate(eventDistributor, "events_distribution_task", 10*1024, NULL, 1, &eventsTask);

    //connect to WIS web socket
    websocketSendBuffer = xMessageBufferCreate(websocketSendBufferLen);
    websocket_app_start(websocketSendBuffer, websocketSendBufferLen, eventsBuffer);

    //start websocket sending listening loop
    TaskHandle_t webSocketSendTask = NULL;
    if(BaseType_t retrb = xTaskCreate(websocket_send_loop, "web_socket_send_task", 6*1024, NULL, 1, &webSocketSendTask) != pdPASS)
        ESP_LOGI(TAG, "Create Task websocket_send_loop failed, ERR: %d", retrb);
    else ESP_LOGI(TAG, "Create Task websocket_send_loop SUCCESS, RES: %d", retrb);

    //start websocket pinger
    TaskHandle_t webSocketPingTask = NULL;
    BaseType_t retrc = xTaskCreate(ping_loop_task, "ping_loop_task", 2*1024, NULL, 1, &webSocketPingTask);
    if(retrc != pdPASS)
        ESP_LOGI(TAG, "Create Task ping_loop_task failed, ERR: %d", retrc);
    else ESP_LOGI(TAG, "Create Task ping_loop_task SUCCESS, RES: %d", retrc);
   
    //audio 
    setup_audio_buffer(); //must call this before starting the audio tasks
    
    printPerfInfo(true);

    //send audio task
    TaskHandle_t sendAudioTaskHandle = NULL;
    BaseType_t retrd = xTaskCreate(sendAudioChunk, "send_audio_chunk_task", 6*1024, websocketSendBuffer, 1, &sendAudioTaskHandle);
    if(retrd != pdPASS)
        ESP_LOGI(TAG, "Create Task sendAudioChunk failed, ERR: %d\nFree Heap Size: %d, WANTED TO ALLOCATE %d", retrd,heap_caps_get_largest_free_block(MALLOC_CAP_8BIT), 6*1024);
    else ESP_LOGI(TAG, "Create Task sendAudioChunk SUCCESS, RES: %d", retrd);

     printPerfInfo(true);

    //start microphone input AFTER STARTING AUDIO QUEUE
    TaskHandle_t microphoneTaskHandle = NULL;
    BaseType_t retre = xTaskCreate(microphone_stream, "microphone_stream_task", 6*1024, NULL, 1, &microphoneTaskHandle);
    if(retre != pdPASS)
        ESP_LOGI(TAG, "Create Task microphone_stream failed, ERR: %d\nFree Heap Size: %d, WANTED TO ALLOCATE %d", retre, heap_caps_get_largest_free_block(MALLOC_CAP_8BIT), 6*1024);
    else ESP_LOGI(TAG, "Create Task microphone_stream SUCCESS, RES: %d", retre);
    
    return;
}

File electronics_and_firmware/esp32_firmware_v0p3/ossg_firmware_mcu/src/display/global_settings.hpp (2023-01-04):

/*
The maximum resolution that can be output depends on the signal type.
720x480 (NTSC,NTSC-J), 864x576 (PAL,PAL-M), 720x576 (PAL-N).

Any resolution less than the maximum resolution can be set.
It is recommended to specify the resolution obtained by dividing the maximum resolution by an integer.
If you specify any other resolution, the ratio of pixels will vary depending on the location, 
and the display will be slightly distorted.

Notes:

(For width)
720/1.125 = 640
480/1.125 = 426.666667

(For height) Works sometimes???
720/1.2 = 600
480/1.2 = 400

(x/1.5) <=== HIGHEST CURRENT WORKING
720/1.5 = 480
480/1.5 = 320

(x/2) = 360
720/2 = 240

Max res 720x480 will only work if use_psram = 2;
*/

//Change screen res here
#define AV_WIDTH_OG 480
#define AV_HEIGHT_OG 360

#define AV_SAFEZONE 40 //Raise to effectively raise FOV at the cost of resolution

//Reference these for runtime shit
#define AV_WIDTH AV_WIDTH_OG - AV_SAFEZONE
#define AV_HEIGHT AV_HEIGHT_OG - AV_SAFEZONE

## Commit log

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2022-02-08 finsh schematic, resize pcb layers and edge cuts for 140mm mic array
    [mico.kicad_pcb, mico.sch]
2022-02-08 precisely place microphones, seperate each mic resistor and capacitors
    [mico.kicad_pcb]
2022-02-08 wire up mics, just need to connect data lines
    [mico.kicad_pcb, mico.sch]
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2022-02-08 last few changes, fix DRC issues, generate gerbers
    [mico-B_Cu.gbl, mico-B_Mask.gbs, mico-B_Paste.gbp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]
2022-02-11 add test pads, last check before order PCB
    [MSA_bom.csv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]
2022-03-19 make repo, add in battery model, main compute board reference model
    [ear_battery_to_scale_OSSG.f3d, ear_battery_to_scale_OSSG.step, main_compute_board_mxiot_OSSG.f3d]
2022-03-19 fix offset in signal sample counts by checking all DMA IRQ every time handler is thrown - seems some handlers are being missed? This might not be the perfect solution as it's not expected performance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
    [main.c, pdm_microphone.c, serial_reader.py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]
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2022-03-24 seperate into two boards, design first iteration of flex pcb mic array and small form factor rp2040 board
    [MSA_bom.csv, RP2040.step, XTAL1140X470X420N.step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]
2022-03-24 make slim stack connector PLUG footprint + symbol, add slim stack connector to flex pcb
    [msa.kicad_pcb, msa.kicad_sch, slim_stack_molex_PLUG_5035521222.stp]
2022-03-24 add slimstack receptacle to library, add to main rigid board
    [mico.kicad_pcb, msa.kicad_pcb, msa.kicad_sch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]
2022-03-25 finish implementing slim stacks, add stiffeners to flex pcb, run DRC and fix all issues on both boards
    [msa.kicad_pcb, msa.kicad_sch]
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2022-03-28 last changes setup for manufacturing for v0p2 - only step left is spacing of microphones
    [msa.kicad_pcb, msa.kicad_sch]
2022-03-28 add new v0p2 boards, add start of combining together electronics
    [combined_hardware_electronics_OSSG_v1.f3z, mic_array_flex_board_kicad_project.step]
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2022-03-30 change usb to proper right angle, set 45 mm spacing of microphones and proper overhang space
    [1050170001.stp, 1051330001.stp, RP2040--3DModel-STEP-269445.STEP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]
2022-03-30 move main board connector to top of board, cutout main board outline to taper
    [msa.kicad_pcb]
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2022-05-12 pull in electronics to same repo as mechanical
    [1050170001.stp, 1051330001.stp, MSA_bom.csv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]
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2022-05-14 add stls and remove version control from file names (timestamps in file names)
    [MAIN_3DPRINT_OSSG_0p2.stl]
2022-05-14 rearrange electronics folder and start new project for esp32 board
    [1050170001.stp, 1051330001.stp, MSA_bom.csv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]
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2022-05-15 flash - select component, make symbol, add to schematic
    [OSSG_v0p3.kicad_sch]
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2022-05-16 swap out LDO for a better one
    [OSSG_v0p3.kicad_sch]
2022-05-16 layout edge cuts for PCB to maximize length whilst fitting glasses
    [OSSG_v0p3.kicad_pcb]
2022-05-17 add crystal oscillator
    [OSSG_v0p3.kicad_sch]
2022-05-17 Antenna, caps and serial
    Antenna and matching circuitry added
    External capacitor added
    TX resistor
    [OSSG_v0p3.kicad_sch]
2022-05-18 ADC caps and test point, esp32 external capacitor, esp reset pullup and switch
    [OSSG_v0p3.kicad_sch]
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2022-05-20 Replaced with picod4 and added programming
    [OSSG_v0p3.kicad_sch]
2022-05-21 Fixed ADC and added uart leds
    [OSSG_v0p3.kicad_sch]
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2022-05-22 Add files via upload
    Changes:
    - Arms longer by 20mm
    - Made corner part more solid
    - Fixed battery compartment size
    [MAIN_3DPRINT_OSSG_0p3.stp]
2022-05-22 add GPIO breakouts, fix ADC pins and filters, add battery terminals
    [OSSG_v0p3.kicad_sch]
2022-05-22 fix antenna by removing impedance matching (impedance matching is built into PICO-D4
    [OSSG_v0p3.kicad_sch]
2022-05-26 start PCB layout, small schematic fixes
    [OSSG_v0p3.kicad_pcb, OSSG_v0p3.kicad_sch]
2022-05-29 Replaced uart adapter
    Replaced FT232RL with FT232RQ due to size constraints
    [OSSG_v0p3.kicad_sch]
2022-05-29 battery voltage divider, fix USB GND, add USB reverse voltage diode, update footprints of everything, update layout
    [OSSG_v0p3.kicad_pcb, OSSG_v0p3.kicad_sch, PRO-OB-440.step]
2022-06-02 Changed antenna
    Added keepout zone as graphic and required trace.
    [OSSG_v0p3.kicad_pcb, OSSG_v0p3.kicad_sch]
2022-06-08 fix TX/RX switch, fix DW01A transistor symbol, update footprint sizes, remove IO0 and GPIOs at north side of ESP32-PICO-D4
    [OSSG_v0p3.kicad_pcb, OSSG_v0p3.kicad_sch]
2022-06-08 more work on layout, small schematic fixes
    [OSSG_v0p3.kicad_pcb, OSSG_v0p3.kicad_sch]
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2022-06-11 lots of layout, fix footprint not found error, work towards better RF for antenna
    [OSSG_v0p3.kicad_pcb, OSSG_v0p3.kicad_sch]
2022-06-11 change breakout test pads footprint size and start laying out breakouts
    [OSSG_v0p3.kicad_pcb, OSSG_v0p3.kicad_sch]
2022-06-12 add voltage supervisor, go back to PRO_OB_440 antenna, more layout
    [OSSG_v0p3.kicad_pcb, OSSG_v0p3.kicad_sch]
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2022-06-15 initial import of KiCAD 5.1 single PDM microphone PCB
    [microphone.kicad_pcb, microphone.sch]
2022-06-16 swap two SH connectors
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2022-06-17 Kicad V5.1 Microphone with solder connector and no screw
    [microphone.kicad_pcb, microphone.sch]
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2022-06-18 add microphone and external microphone breakout pads to left arm board schematic and layout
    [OSSG_v0p3.kicad_pcb, OSSG_v0p3.kicad_sch]
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2022-06-18 Graphical fixes
    Added silkscreen for adc testpoints
    [OSSG_v0p3.kicad_pcb]
2022-06-19 add io0 and en TPs, fix silk screen, add missing capacitors, add ground pour and exposed pad for thermals under ESP32-PICO-D4
    [OSSG_v0p3.kicad_pcb, OSSG_v0p3.kicad_sch]
2022-06-20 start adding in MPN, links, pricing, BOM... digikey and LCSC
    [OSSG_v0p3.kicad_sch]
2022-06-21 add in part numbers and prices for almost all components for LCSC
    [BOM_draft.csv, OSSG_v0p3.kicad_pcb, OSSG_v0p3.kicad_sch]
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2022-06-22 attempt to fix CH9102F programmer circuit
    [OSSG_v0p3.kicad_sch]
2022-06-24 add power supply switching, update all footprint to be accurate, move antenna to LCSC part, start new layout
    [OSSG_v0p3.kicad_pcb, OSSG_v0p3.kicad_sch]
2022-06-25 layout complete after fixing footprints, adding PSU switching, spreading out breakout points, etc.
    [OSSG_v0p3.kicad_pcb, OSSG_v0p3.kicad_sch]
2022-06-27 make breakout smaller, fix issues with breakouts too close to thermal pad, clean up silk screen, generate gerbers
    [OSSG_BOM.csv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]
2022-06-28 change PSU MOSFET symbol from DGS to DSG to match part, cleanup schematic
    [OSSG_v0p3.kicad_sch]
2022-06-29 Fixed front silkscreen overlaps
    [OSSG_v0p3.kicad_pcb]
2022-06-30 change to new LDO, change voltage supervisor, inspect board, slight silk screen changes
    [OSSG_v0p3.kicad_pcb, OSSG_v0p3.kicad_sch]
2022-07-01 change PICO gpios to use non-reserverd pins (and add reserved pins note), change FS8205A MPN to SOT-23 version, fix voltage supervisor symbol
    [OSSG_v0p3.kicad_pcb, OSSG_v0p3.kicad_sch]
2022-07-01 convert to kicad 6, make footprint project libs, shrink layout to smaller bord
    [microphone.kicad_pcb, microphone.kicad_sch]
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2022-07-02 fix MSAv0p2 main board pcb connector pinout, fix gerber renders, update README
    [OSSG_v0p3-B_Cu_Signals.gbl, OSSG_v0p3-B_Cu_Signals.gbr, OSSG_v0p3-B_Mask.gbr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]
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2022-07-28 Add files via upload
    - Lens alignment is better (still needs work).
    - Micro USB slot has moved to the correct position.
    - Battery compartment is sized to fit the above 500mAh battery
    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
2022-08-06 Redesigned the arm cavities so that the covers are now on the inside. Added bolt mounts to arm covers and arms.
    [ARM_COVER_LEFT_3DPRINT_OSSG_0p3.stl, ARM_COVER_RIGHT_3DPRINT_OSSG_0p3.stl]
2022-08-09 better quality audio streaming, still need to fix dropping data
    [main.c]
2022-08-11 Arms now slide into the front frame with a dovetail joint. Both left and right arms and the front frames are included in seperate stl files. The stp file is updated. The covers are unchanged.
    [ARM_LEFT_3DPRINT_OSSG_0p3.stl, ARM_RIGHT_3DPRINT_OSSG_0p3.stl]
2022-08-14 Fixed the corner part to have more material near the slot. Covers now have clips.
    [ARM_LEFT_3DPRINT_OSSG_0p3.stl]
2022-08-19 Fixed ARM_LEFT to be the same as ARM_RIGHT
    [ARM_COVER_LEFT_3DPRINT_OSSG_0p3.stl, ARM_COVER_RIGHT_3DPRINT_OSSG_0p3.stl, ARM_LEFT_3DPRINT_OSSG_0p3.stl]
2022-08-21 clean audio signal from esp32 PDM mics - change rates so sending doesn't fall behind
    [main.c]
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2022-09-12 add auto reconnect, add pingpong to check for broken connection, add auto gateway IP finder
    [main.c]
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2022-09-14 adding in ESP32-Pico datasheet + partial Power schematic
    [Power.kicad_sch]
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2022-09-16 adding in last update for the 2S branch design
    [OSSG_v0p4.kicad_sch, Power.kicad_sch]
2022-09-16 duplicate V0.4 directory to split project into 2S and 2P battery pack designs
    [ANT3216LL-Antenna-Chip.step, B3U-3100P-B--3DModel-STEP-56544.STEP, ESP32-PICO-D4--3DModel-STEP-56544.STEP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]
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2022-09-18 V0.4 PCB nearly finished. 3D models mostly added in. Needs reviewing
    [1.5uH-4.5x4mm.step, OSSG_v0p4.kicad_pcb, OSSG_v0p4.kicad_sch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]
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2022-09-19 only PCB edge clearance errors
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2022-09-19 adding in V0.4 BoM listings and small schematic changes
    [OSSG_v0p4.kicad_sch, OSSG_v0p4p5_BoM.csv, OSSG_v0p4p5_BoM.ods]
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2022-10-24 fix build errors re sdkconfig and partition table
    [partitions_singleapp_large.csv]
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2022-10-27 Fixed my name lol
    [main.cpp]
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2022-10-29 fix audio streaming issues, parse transcripts incoming
    [main.cpp]
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2022-11-22 Display + Mic sort of works. Works great until around 10 words have been transcribed. Then crashes.
    [main.cpp]
2022-11-22 Need to investigate memory leak, perhaps JSON related
    [main.cpp]
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2022-11-27 Fixed the memory leak
    [main.cpp]
2022-11-29 move pcb shape notch to top, swap mic for i2s mic
    [OSSG_v0p5.kicad_pcb, OSSG_v0p5.kicad_sch]
2022-12-02 fix issues, fix silk screen, add psram pullup, change i2s mic footprint, change battery charging resistor, make notch bigger and fix 3v3 pour not contiguous
    [OSSG_v0p5.kicad_pcb, OSSG_v0p5.kicad_sch, Power.kicad_sch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]
2022-12-02 fill in missing LCSC part numbers (still missing polyfuse
    [OSSG_v0p5.kicad_sch, Power.kicad_sch]
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2022-12-03 add mosfet switch for display power, thicken some traces, check things over
    [OSSG_v0p5.kicad_pcb, OSSG_v0p5.kicad_sch]
2022-12-04 change display MOSFET switch to p-type and switch high, thicken some traces on ext. i2s board, slide button down (check this fits capabilities), get rid of via in pad, move i2s line so not over top o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
    [OSSG_v0p5.kicad_pcb, OSSG_v0p5.kicad_sch, microphone.kicad_pcb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]
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2022-12-18 updated KiCAD V0.4 and V0.5 schematics with correct switch part number
    [Power.kicad_sch]
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2022-12-27 make live life captions work by fixing current mode string bugs
    [displaymanager.cpp, main.cpp]

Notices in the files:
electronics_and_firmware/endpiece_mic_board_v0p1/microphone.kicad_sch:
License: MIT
